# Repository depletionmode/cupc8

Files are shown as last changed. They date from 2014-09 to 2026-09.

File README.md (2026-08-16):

## CUPC/8

###### Documentation
https://github.com/depletionmode/cupc8/blob/master/doc/CUPC8%20Manual.md

###### Blog
http://depletionmode.com/

### Terminal debugger

Build the debugger from `tools/` with:

```sh
nim c -d:release simtui.nim
```

Then run `kernel/debug.sh`. The guest display is embedded by default; use
`kernel/debug.sh --display:window` for the standalone SDL window. Terminal
graphics and color treatment can be selected explicitly:

```sh
kernel/debug.sh --gfx:half --theme:light
kernel/debug.sh --gfx:auto --theme:dark
```

Inside the debugger, `:display embedded|window`, `:theme auto|dark|light`, and
`:gfx auto|kitty|half` switch these modes without restarting. Pane borders can
be dragged with the mouse to resize the layout. Press `?` for the complete
keymap and command reference.

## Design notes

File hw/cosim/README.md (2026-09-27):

# Schematic-derived wiring prerequisite

`gen_top.py` exports fresh KiCad netlists for the seven cards and reads the
main-board netlist. For routed slot execution it also reads the generated
GPU, IO, storage, Wi-Fi and e-ink card PCBs from `build/hw` (or
`--card-board-dir`), and the explicitly selected routed system PCB
(`--system-board`, default `build/hw/system/system-routed.kicad_pcb`) and CPU
card PCB (`--cpu-board`). It joins contacts by physical pad number, including the
system socket's x4 pad translation. It checks the shared slot buses, their
chipset series resistors, the weak MISO pull, CPU socket and resistor packs,
and SRAM/ROM attachment. Its JSON manifest lists contact joins and the
verified model attachment paths. A broken connection exits nonzero.

The native RTL machine consumes the manifest when `CUPC8_COSIM_TOP` points to
it. CPU address/data wires and SRAM/ROM address/data pins use physical bit
maps read from KiCad pads. Slot SPI/IRQ and system bridge lines use their
connector maps. The shared MISO idle level comes from the verified 47 kΩ
pull-up. Cards receive edges after the 33 Ω source RC delay (1.089 ns for a
15 pF input). SRAM and ROM reads wait their 45 ns and 70 ns maximum access
times plus routed copper delay (7 ps/mm). A memory bus with no routed copper
gets provisional access times and `routed_timing: false`. The manifest lists
unrouted CPU, memory, slot, bridge, clock, reset and power-policy signal nets
under `missing_routes`; `--require-route` rejects them.
The generator separates `runtime_nets`, whose netlist values affect the
machine, from `structural_only_nets`, which have only a connectivity check.
All named nets without an executed model or a reviewed waiver appear in
`unmodeled_nets`; `structural_only_nets` still lists every structural-only net,
including waived ones. `coverage_families` groups the remaining gaps by their
required model domain. This classification is a work queue and grants no
coverage. E2E-001 through E2E-004 use `--require-coverage` and fail while any
gap remains. This keeps local card and power circuits from being silently
counted as covered.

`reviewed_waivers` currently permits only reserved connector contacts with
exactly one passive test point and no active electrical load. CPU and system
reserved contacts require the corresponding card pad to be KiCad NC; a slot
reserved contact requires all five possible card pads to be NC. The system's
two B-side reserved contacts instead require a passive test point at each end.
The waiver is recalculated from both netlists on every generation. Attaching
an IC pin or changing a mating card pad to an active net restores the coverage
gap; the wiring mutation probe checks both cases. The record includes the
actual pin list, mating contact, and reason for review. No power, clock,
programming, bus, LED, or data signal receives this waiver.

The Type-C source input in E2E-004 passes through the extracted Rd/averaging/
reference network before it reaches the chipset's `PWR_HI` pin. The nominal
trip is 1.289 V on the active CC line; the test drives the 3 A minimum or
1.5 A maximum CC voltage, so a bad resistor network changes the class.
The main-board supervisor U6 reset output must connect to chipset U7's nPOR
input in the KiCad netlist **and** over measured routed copper. The manifest
passes `por_connected` to the native machine's reset input. On the routed
snapshot the shortest planar path is 88.152 mm; removing the supervisor
launch track makes `por_connected` false, and the native CPU stays at reset
PC `$E000` instead of reaching `$E2B9` in the 20 ms probe.
The separate chipset-to-CPU reset path crosses U7.32 to R34.1 on
`CPU_nRST_SRC`, R34.2 to main socket J2.B16 on `CPU_nRST`, and CPU-card
J1.B16 to U1.22. The archived main and current CPU card measure 12.342,
103.930, and 27.014 mm on these legs. The native RTL now gates the CPU's
reset input with their combined continuity while leaving the chipset's own
reset output visible. Opening the U7 launch removes only the source leg;
the native 20 ms probe leaves the chipset reset output high but holds the
CPU PC at `$E000` instead of `$E2B9`. Holding the otherwise floating input
low is a deterministic digital counterexample, not a voltage prediction.
The chipset's MEM_nWE pad U7.114 must also connect by KiCad net and routed
copper to SRAM U9.5 and ROM U10.31. The two independent branch flags gate
native memory writes. On the routed snapshot the shortest planar branches
measure 11.292 mm to SRAM and 54.867 mm to ROM. Removing the chipset's /WE
launch disables both. In a 20 ms CPU probe, an open SRAM /WE changes PC from
`$E2B9` to `$E1FF`; an open ROM /WE makes a 4 KiB sysctl flash write fail
read-back verification. This models the write-enable path only; other memory
controls and analog timing remain separate work.
ROM DQ0 has an additional route-bound read dependency from U10.13 to chipset
U7.119. The measured planar route is 23.517 mm. Opening its ROM launch track
keeps the other memory data traces in place but changes the native CPU's 20 ms
state from PC `$E2B9`/GPO `$02` to PC `$E35B`/GPO `$00`. The open net has no
pull resistor, so its voltage is physically undefined; the digital model
uses a deterministic high DQ0 value solely to expose the missing connection.
This counterexample does not establish analog open-pin behavior.
The CPU card's 16 address and 8 bidirectional data driver channels are now
traced in two copper legs each: FPGA pad to the 33 Ω pack input, and pack
output to the CPU socket finger. The generated per-bit links gate the native
CPU–chipset RTL bus in both data directions. Opening the routed FPGA A0
launch changes the native program counter; an open D0 link also changes
execution. An open bit is held high only as a deterministic digital
counterexample because its real voltage is undefined. This does not establish
CPU-card propagation delay or analog margin, and the remaining control lines
still need executed models.
The IO card's USB host data pair must pass from the RP2040 pins through the
27 Ω series resistors to the receptacle. That netlist path controls keyboard
attachment in the native machine; an open path leaves it disconnected.
Each of the six main-board slot chip selects is now connected to the native
card-select input through its netlist-identified 33 Ω resistor. Copper is
traced separately from the chipset package pad to the resistor input and
from the resistor output to the slot contact. A missing leg deasserts the
corresponding card's select in the native machine and fails `--require-route`.
The slot 1 source launch mutation leaves the other five selects intact and
reduces recorded SPI frames from 15 to 0. This accounts for the six
`SPI_nCS*_SRC` nets. Shared SPI SCK and MOSI use the same two-leg check from
the chipset through their 33 Ω source resistors to each of six slot pads;
MISO is traced from each slot pad back to the chipset input. The corresponding
per-slot link flags control the native card clock, outbound data, and return
bit. Opening the routed SCK source launch stops all slot 1 frames (15 to 0).
With the MOSI link disabled, the first GPU command changes from `$F0` to `$00`;
with MISO disabled, the native GPU workload records only 2 frames instead of
15. For digital counterexamples, open SCK/MOSI are held low and open MISO
reads the modeled idle high value; these choices do not predict analog
floating-pin voltage. The two source-side SCK/MOSI nets now count as executed.
The five slot cards now supply card-local route flags as well. SCK, MOSI,
CS_n and IRQ_n run from J1 to the MCU pad. MISO crosses the 74LVC1G125
buffer: MCU output to buffer input, buffer output to J1, and CS_n to its
output-enable pad. The generated top includes all five card kinds, while the
native machine combines only the installed kind's links with the physical
slot's main-board links. A missing generated card PCB leaves those links
disconnected and fails `--require-route`. Opening the GPU card's U1 SCK
launch changes 15 SPI frames to 0; opening IO-card IRQ_n prevents five
keyboard-service SPI frames within the first 25 ms after a key is queued.
This models digital connectivity and IRQ delivery, not analog edge quality
or open-pin voltage.
Five RP2040 boards (system, GPU, IO, storage, e-ink) also require all six
QSPI MCU-to-flash nets to have pad-to-pad copper before their native firmware
starts. An open clock launch on the GPU card changes 15 SPI frames to none;
the same board-level prerequisite removes only that card's firmware endpoint.
Mutating the IO prerequisite removes its keyboard, and mutating the system
prerequisite removes its bridge USB endpoint. The native firmware still comes
from an ELF image, so this checks a digital boot wiring prerequisite only;
flash contents, protocol timing, signal integrity, power rails, crystals,
reset and RP2040 boot-ROM fallback remain outside this model.
The storage card's seven SD signal contacts similarly control whether the
microSD socket is attached to its RP2040 model.
All four HDMI differential pairs, including the clock pair, must pass through
their 270 Ω series pack channels to the receptacle before the TMDS capture
endpoint attaches. Seven e-paper data/control lines through 33 Ω resistors
likewise control whether the panel attaches.
E2E-002 and E2E-003 capture the native HDMI frame after the BASIC program or
network page, replay the
observed GPU-slot SPI traffic through the independent host GPU core, and
compares all 640×480 decoded TMDS pixels at RGB222 precision. A fast mutation
test changes one SPI PUTC byte and requires the pixel comparison to fail.

From the repo root, after building the main board and five slot cards:

```
python3 hw/cosim/gen_top.py --output build/hw/cosim/top.json
python3 test/hw/test_cosim_wiring.py --main-board build/hw/main/main.kicad_pcb --card-board-dir build/hw --system-board build/hw/system/system-routed.kicad_pcb --cpu-board build/hw/cpu/cpu.kicad_pcb
python3 test/hw/test_cosim_runtime.py --top build/hw/cosim/top.json
# after the main route is complete:
python3 hw/cosim/gen_top.py --require-route --output build/hw/cosim/top.json
CUPC8_COSIM_TOP=build/hw/cosim/top.json CUPC8_EMU=native node test/emu/test_e2e.mjs E2E-002
# The catalogue can use this strict entry point for each row:
python3 hw/cosim/run.py E2E-001
python3 hw/cosim/run.py E2E-002
python3 hw/cosim/run.py E2E-003
python3 hw/cosim/run.py E2E-004
```

The second command proves swapped SCK/MOSI contacts, a missing chip select,
and a missing MISO pull are rejected. With `--main-board` it also opens the
supervisor's routed nPOR launch, chipset CPU-reset launch, slot 1 chip-select launch, shared SCK
source launch, GPU card SCK launch, GPU QSPI clock launch and CPU-card A0
launch, then executes the native
counterexamples. The third proves
that ROM and CPU
address/data swaps, slot SCK/MOSI swaps, bridge SCK/MOSI swaps, an open
nPOR and CPU-reset paths, memory-write branches and ROM DQ0 read route change the running
machine. The manifest currently covers the CPU, main memory, slot data paths,
system bridge, Type-C source class and
supervisor nPOR release and CPU reset delivery. Other power and reset circuits still use native
machine wiring. On the routed-board snapshot used for this audit, all required
top-level routes are present. Of 502 previously uncovered named nets, 45
reserved contacts have pin-bound waivers, eight slot-bus source nets, 30
card-local slot nets, 30 QSPI boot nets, 24 CPU-card bus nets and three CPU
reset nets now affect execution; 362 remain unmodeled. The remaining groups are boot/programming
(68), slot/control bus (36), CPU/memory (47), power/return (65), clock/reset
(50), indicators (52), external IO (26),
and power policy (18). E2E-001 through E2E-004 remain
pending behind `--require-coverage` despite passing narrower runtime probes.

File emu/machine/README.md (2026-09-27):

# emu/machine: the whole machine, natively

The native whole-machine emulator of `doc/milestone-1.md` ("Whole-machine
emulator", "Emulator speed"): `test/emu/machine.mjs` in C++, cycle for cycle.
The main board is the Verilated CPU + chipset (`soc/emu/board.h`, shared with
`build/emu/core.node`) with the SRAM and the SST39 ROM model
(`fw/test/sysmodels.c`); the GPU, IO and system cards run their real firmware
on the native RP2040 (`emu/rp2040`, its card-test harness for the `Emu` step
loop and TMDS capture); the Wi-Fi card is Espressif's QEMU, in step with the
board (below, "The Wi-Fi card"), with machine.mjs's `$A6`/`$A5` protocol.

| file | what |
|---|---|
| `machine.h`, `machine.cpp` | the cards (`Rp2040Card`, `SysctlCard`, `EspCard`), TMDS frame decoding and font matching, `Machine` (the loop, the card threads, `screen()`, `type()`) |
| `addon.cpp` | `machine.node`, wrapped by `test/emu/machinenative.mjs` into machine.mjs's `Machine` API |
| `machinerun.cpp` | the machine from the command line: speed runs, serial vs threaded digests |
| `../../soc/emu/board.h` | the main board (also used by `soc/emu/core.cpp`) |

## Build and run

```sh
tools/emu_machine_build.sh          # tools/emu_build.sh, then cmake + ninja into build/emu-machine
tools/qemu_build.sh                 # the Wi-Fi card's lockstep QEMU (build/qemu-esp); tools/fw_esp32c3.sh qemu, its firmware
node test/emu/test_wifi_lockstep.mjs # EMU-009: the Wi-Fi card in step, serial vs threaded
CUPC8_EMU=native node test/emu/test_e2e.mjs E2E-002
test/emu/machine_diff.sh            # serial/threaded determinism (EMU-007; machine.mjs is legacy, not compared)
build/emu-machine/machinerun --root . --rom ROM --mode both \
    --until '>>' 6e9 --type '10 print 6*7\nrun\n' --until 42 3e9 --run 200e6
```

`machinenative.mjs` has the same API as machine.mjs (`create({slots, rom,
sysctl})`, `powerOn`, `runFor`, `runAsync`, `runUntil`, `ns`, `state`,
`frame`, `screen`, `type`, `keyboard.press`, `stop`, `sysctlPort`), plus
`setThreaded`, `stats`, `cards`, `spiLog` and the `spiLog`/`threaded` create
options. `create({pwrHi: false})` drives the chipset's PWR_HI input low to
exercise the kernel policy for a source below 3 A; it does not model CC
voltage or supply current. `CUPC8_EMU_THREADS=0` runs serially. `runFor` runs on the calling
thread's call and returns; `runAsync`/`runUntil` yield to Node's event loop
between slices exactly as machine.mjs does, so cupc8.py can talk to the
system card's TCP port. The system card's CDC output is collected during a
slice and written to the socket at its end; input from the socket is queued
between slices, as in machine.mjs (where both only move when the event loop
turns). `-DMACHINE_LTO=ON`: see Speed.

The system card is a composite USB device with two CDC ports (`sysctl.md`);
the host side is `rp2040js::CdcHost` (`emu/rp2040/src/usb/cdchost.cpp`, the
port of `test/emu/cdchost.mjs`). Port 0 is the TCP port above; port 1, the
USB console (`../../doc/proposals/usb-console.md`), is `m.console` in
machinenative.mjs: `open()`/`close()` set and clear DTR on it (between
runs), `write()` queues bytes, `read()` returns what arrived, `listen(port)`
serves it on TCP (a connection opens it). The addon's `cdcWrite`/`cdcRead`
take the port as their last argument, and `consoleOpen(h, on)` sets DTR.

## The loop

`Machine::iterate()` is machine.mjs's `runFor` loop body, statement for
statement: `bridgePins` (the system card's SPI byte clocked into BR_* at
1 MHz); *busy* if a slot or the bridge is selected; while busy, every card is
advanced to the next clock edge, the board runs one clock, the system card
and then each slot card (slot order) advance to the board's time and are
driven; otherwise the board runs up to 120 clocks (stopping early when a
watched output changes) with its inputs sampled once, and the cards are
advanced and driven afterwards.

## Threads, and why they change nothing

Each RP2040 card has a thread. In an idle iteration nothing is advanced before
the board runs, the board's inputs (the cards' IRQ pins, the bridge pins,
`sysReset`) are sampled once at the start, and each card is then advanced to
the board's end time `t` (`while (ns < t) step()`) and driven with the
board's end outputs. So:

- The cards' work in the window depends only on `t`, the end outputs and the
  card's own state; it touches only that card (no RP2040 state is shared:
  emu/rp2040 has no globals). The order of cards within a window cannot
  matter, so they may run concurrently.
- A card's step sequence does not depend on its target. A card that steps
  while `ns < c * 1000/12`, for a clock count `c` the board has already
  reached in this window, takes a prefix of the steps `advance(t)` takes,
  because `t >= c * 1000/12` (the same double expression). So each card
  *chases* the board's clock count while the board runs, and finishes at
  `t` once the board marks the window FINAL: exactly the serial state.
- Nothing flows back until the window ends: the next iteration starts only
  when every card has arrived at the barrier; only then are the pins read.
- Busy iterations run serially, in machine.mjs's order, on one thread (every
  card is sampled each clock there: IRQ pins of unselected cards reach the
  chipset clock by clock, and the shared SCK/MOSI lines re-set their GPIO
  edge bits, so no card may run ahead).

There is no board thread: whoever leads an iteration runs the serial part
(bridgePins, busy iterations, the board's run while the others chase), then
does its own card's share; `runFor` hands the run to the threads and waits.
The leader is normally a quick card (IO, system card) that has finished its
window and volunteers, spinning until the slow card (the GPU) arrives and
hands over, so the GPU only ever chases; if nobody volunteers in time, the
last card to arrive leads. Who leads cannot change the result: the leader
does exactly the serial loop's work, with every other card parked.
`CUPC8_EMU_VOLUNTEER_SPINS` (default 200000, 0 = never volunteer) bounds the
volunteer's spin. Waits spin briefly and then sleep on a futex. `machinerun --mode
both` and `test/emu/machine_diff.sh` check the result: identical board
clocks, CPU state, RAM, every card's time, cycle counts and UART, a hash over
(board clocks, outputs, every card's time) after every iteration, every SPI
frame, and the screen.

A `storage` slot runs `build/rp2040/storage.elf` with the SD card model's
socket on its SPI1 (`emu/rp2040/harness/sdcard.h`); `Machine::sd()`, and
`sdInsert`/`sdRemove`/`sdCard` in the addon (`m.sd` in machinenative.mjs), put
an image in and take it out between runs. The model runs on the storage
card's own clock, inside its thread.

Harness hooks used in emu/rp2040: `FIFO::onPull` (TMDS capture), the SPI
`onTransmit`/`completeTransmit` callbacks, USBCDC and UsbKeyboard; nothing in
emu/rp2040 was changed for this directory.

## Speed

Boot to BASIC and type a program (1.6 s emulated, `test/emu/machine_diff.sh`,
quiet 4-core 2.1 GHz Xeon, emu/rp2040 with its PIO fast path, 2026-09-24):

| backend | slower than real time |
|---|---|
| machine.mjs (rp2040js) | 108x |
| native, serial (`CUPC8_EMU_THREADS=0`) | 23.5x |
| native, threaded (default) | 18.0x |

The threaded machine runs at the GPU card's speed: the GPU thread is busy
~95% of the wall time (252 MHz, three DVI serialisers every cycle), while the
IO card, the system card and the main board (each ~2-3x slower than real time
alone) run beside it. The spec's "a few times slower than real time" needs a
faster GPU card emulation in emu/rp2040. `-DMACHINE_LTO=ON` builds this
tree's copy of the RP2040 library with -O3 and LTO (about 10% faster before
the PIO fast path; not re-measured). On an oversubscribed host the threaded
mode can be slower than serial: the threads meet every 10 us of emulated time.

## The Wi-Fi card

The Wi-Fi card's firmware (its QEMU build, `tools/fw_esp32c3.sh qemu`) runs
in Espressif's QEMU, built by `tools/qemu_build.sh` from the tag the SDK's
binary comes from with `tools/patches/qemu-esp-lockstep.patch` (the SDK's
binary has no plugins and no outside clock control). It runs **in step with
the board**:

- `-icount shift=3,sleep=off`: the guest's clock is its instruction count
  (8 ns each), and an idle guest's clock jumps straight to its next timer.
  `-seed 1` and the patch's fix to the SYSCON random register (it was
  `rand()` seeded from `time(NULL)`) make its random numbers repeat.
- `-chardev cupc8` (the patch's `system/cupc8-lockstep.c`) is the emulator's
  line to QEMU. The guest runs only as far as the emulator lets it:
  `EspCard::advance(t)` grants it the board's time in 100 us steps, so it
  trails the board and runs beside it, in its own process.
- **The slot SPI slave is a device in QEMU**, a stand-in for the ESP32-C3's
  GPSPI2 slave at GPSPI2's address and interrupt source (registers in
  `cupc8-lockstep.c`). Like the real slave's queued DMA descriptor it holds
  the MISO preload the firmware armed, so the board never waits for the
  guest: at CS_n falling QEMU runs to the board's time and hands the preload
  over, and at CS_n rising the frame's MOSI bytes reach the device at the
  board's time and raise its interrupt. The firmware's ISR
  (`fw/wifi/port/esp32c3/main/transport_slotdev.c`) is `transport_spi.c`'s
  `done()`/`arm()`: it queues the frame and arms the next preload, swapped
  in whole by one register write. QEMU's clock is the board's at every
  select (to within one instruction), through `net join`'s back-to-back
  polling too (EMU-009 checks both). A stock QEMU has no such device (its ID
  register reads 0): the firmware then serves frames over UART1 (`$A6`/`$A5`,
  `transport_uart.c`), which `test_wifi_qemu.py` and the legacy machine.mjs
  use.
- **When a stale preload can be seen**, as on the card (`slot.md`: the card
  preloads before CS_n falls; `wifi-card.md`, "Status byte"): a frame shifts
  out the preload armed after the previous frame ended, so the status byte
  and any offered response are as of the previous frame's end, never
  updated mid-frame. The status byte is the task's last reading (the firmware
  takes it with `frames_status()` in its main loop, at most a tick old): the
  ISR may not ask the network stack for it. A response is offered only when
  no command is queued or running (`frames_preload()`), so a READ gets it
  only if it was ready when the frame before that READ ended, and RESP_LEN
  `$00` otherwise. After a READ the next preload may offer the same response
  again until the task has replayed that READ; the host reads a response
  once and sends a new command, which discards it. If the host selects
  before the ISR has re-armed (the host must leave 20 us), the device shifts
  out the previous preload again and still takes the frame (INT bit 1 if the
  ISR had not read the last one); the real slave has no descriptor queued
  then and would miss the frame. EMU-009 counts such selects and requires
  none.
- So the same board run gives the same guest run, instruction for
  instruction: EMU-009 (`test/emu/test_wifi_lockstep.mjs`) runs a join and
  an HTTP GET serially and threaded twice and compares everything, the
  Wi-Fi card's frames, QEMU's clock and the guest's network traffic (pcap)
  included.

**The one known timing approximation: the guest runs at 125 MIPS.** icount
steps are powers of two (`shift=3`: 8 ns an instruction), and the real
ESP32-C3 runs at 160 MHz, at best one instruction a cycle (less out of
flash: cache misses). So the firmware takes its instruction counts at 125
MIPS, e.g. its frame-end ISR is up to 1.28x slower than on the card. Timers
(FreeRTOS ticks, lwIP, the UART's) are in guest time and exact. Accepted by
David, 2026-09-27.

**The network outside the machine is not in step and never can be**: QEMU's
user networking (slirp) talks to real sockets on the host's clock. The patch
pins down the common case: when the guest sends a packet the vCPU stops
right after it, and QEMU waits (wall clock) until slirp has given the guest
nothing new for `CUPC8_LOCKSTEP_SETTLE_MS` (default 20, at most
`CUPC8_LOCKSTEP_SETTLE_MAX_MS`, 2000), so a host that answers within that
time is seen at a defined guest time. A host that answers later, or sends
unasked (a client through a port forward, E2E-014), is seen whenever QEMU's
main loop gets to it. A server inside the test's own Node process answers
only when the event loop turns between slices, usually too late for that,
so EMU-009's server runs in a child process. (Runs where cupc8.py talks to
the system card are not deterministic either: its bytes arrive at slice
boundaries that depend on wall time.)

`CUPC8_ESP_TRACE=FILE` logs every select (`S`, with QEMU's clock after `@`
and the preload) and frame (`F`, the MOSI bytes) at the board's time, and `Machine.create({ pcap })` records the guest's traffic. Two
E2E-003 runs with `CUPC8_E2E003_PORT` set give identical traces (before the
lockstep they differed from the first exchange after the join).

Found by the SPI slave stand-in: the firmware's frame-end ISR built the
preload with the card's `status()`, which asks lwIP (FIONREAD on each
socket); from an interrupt that corrupted FreeRTOS's lists once a socket was
open (the interrupt watchdog fired in `vListInsert`). The UART stand-in took
the preload in a task and hid it; on the card it was waiting to happen. The
ISR now takes the status byte the task last read.

Speed (2026-09-26, 24-core host at load ~15, boot and type a program, 2.4 s
emulated): a Wi-Fi card costs nothing measurable, before or after the
lockstep: threaded 8.6x slower than real time without it, 8.5x with it;
serial 11.3x and 11.2x. QEMU runs in its own process beside the board and
is far faster than it (1.5 s of guest time takes about 0.3 s alone). E2E-003
took 32 s of wall time (40 s before, on its real-time clock).

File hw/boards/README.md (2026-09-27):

# Board designs

Each board is a Python script that generates its KiCad schematic and PCB and
runs the whole pipeline in `hw/tools/kicadgen.py` (`pipeline()`):

1. schematic, ERC
2. netlist, board build, Freerouting
3. GND stitching, zone fill
4. silkscreen and 3D-model checks
5. DRC with schematic parity
6. Gerbers and drill
7. JLC BOM and CPL (every placed part carries an LCSC number), and `order.json`
8. 3D renders

Outputs land in `build/hw/<board>/`, and `fab/` holds what goes to JLCPCB.

```
python3 hw/boards/wifi.py
```

Shared rules:
- **Revision:** every board passes `title`, `revision` and `revision_at` to `pipeline()`, which prints `<title> rev <revision>` on the top silkscreen and puts the revision in the title block (and so in the Gerbers). Bump the board script's `REVISION` (A, B, ...) for every order that changes the board (`doc/milestone-1.md`, Board revision).
- **Cards:** 1.6 mm, with hard-gold fingers and a 30° chamfer. These are
  order options, written in `fab/order.json` and checked there.
- **Card edge:** each card's finger tab is KiCad's `BUS_PCIexpress_*`
  footprint. The script draws the body's outline and meets the tab where it
  starts.
- **Finger tab (every card, done by `pipeline(card_edge=True)`):** GND
  fingers tied into the pour, the PRSNT1_n/PRSNT2_n presence link pre-routed
  (`presence={"layer": ..., "rise": ...}` puts its run on an inner layer: the
  CPU card and the system card use In2.Cu), no vias on the tab, pre-routed
  escapes for the signal fingers beside the key notch, and routed GND tracks
  cleared off the contacts.
- **Inner layers on 4-layer cards (both opt-in):**
  - `zones=(..., ("/GND", ("In1.Cu",)), ("/3V3", ("In2.Cu",)))` makes each named
    inner layer a solid **plane** (a power layer, which Freerouting never
    routes on): the **CPU card**.
  - `plane=True` pours the outer layers' net on In1.Cu as well but leaves In1
    a **signal layer**, which the pour fills around the routes: the **system
    card**. Its QFN-56 fan-out would not route with a layer lost to a plane.
- **Fine pitch:** `fine_nets=` puts nets in the "Fine" class (0.15 mm track
  and clearance, 0.7 mm vias), for parts at 0.4–0.5 mm pitch: the system
  card's RP2040 and USB-C.
- **Branding:** the Kaplan Labs logo on the top silkscreen of every board.
  On the cards, `pipeline(logo_keepout=True)` keeps tracks and vias off the
  top copper under it (a rule area; the pour still fills there), and the
  silkscreen step fails on any track under it: routed across the logo, a
  track shows through the mask as a ridge over the artwork. The system
  card's logo is the 10 mm size (milestone-1.md's minimum): with the 12 mm
  one's keep-out, Freerouting left QFN nets unrouted or pour pockets
  unjoined at every position tried.
- **Designators** (`kicadgen.place_designators`, checked by
  `check_designators` in the silkscreen step, SILK-001): never over a pad
  or a via, another part's courtyard, any part's body or another word, by
  their printed strokes. They are placed before routing; the fixed vias
  (finger ties, presence link, fan-out, a board's own) and then the
  router's move any that landed under one to the nearest clear spot, up to
  2 mm off its part (45 % of a big part's size, for a QFN in its ring of
  vias), turned upright or at JLC's 0.8 mm minimum if that is what fits.
  Two words in one line keep 0.5 mm apart (closer, "C13" and "C11" read
  as "C13C11"). A designator walled in by vias gets room from a
  neighbour's, which steps aside (the build output says which). The
  stitching vias keep off every word. A designator with still no clear
  spot is left off (listed in the build output); none is on the cards. The board's name moves the same way off vias (a wide tab's GND
  ties), and its new spot is then a via keep-out for the router.
- **Assembly:** nothing is fitted by hand. The Wi-Fi card's antenna lead (MHF III to SMA) is
  the one exception: it is plugged in, not soldered.

## Wi-Fi card (`wifi.py`)

Spec: `doc/hardware/wifi-card.md`.

- **U1, ESP32-C3-MINI-1U-N4** (C2911374). The antenna receptacle (MHF III) end sits towards the card's top
  edge. The GPIOs follow `hw/pins.yaml`:
  - SCK: GPIO6
  - MOSI: GPIO7
  - MISO: GPIO5
  - CS_n: GPIO10
  - IRQ_n: GPIO3, open drain
  - LINK, TX and RX LEDs: GPIO4, GPIO0, GPIO1
- **U2, TLV62569DBVR buck** (C141836), fed from the slot's +5V, with L1
  2.2 µH (FNR3015S2R2MT, C167747), 22 µF in, 22 µF + 100 nF out, and a
  453k/100k feedback divider (3.32 V). An AMS1117 LDO failed the power
  checks: in a TX burst at the worst-case corner it left the ESP32-C3 at
  2.71 V (3.0 V minimum), and it ran at Tj ≈ 120 °C (`hw/power`, POW-003,
  THM-001). The slot's +3V3 pins are left unconnected: Wi-Fi TX peaks near
  350 mA, and the slot's +3V3 is limited to 300 mA.
- **U3, 74LVC1G125** (C52140430). Its /OE is CS_n, so the card drives the
  shared MISO line only while it is selected.
- **EN:** 10 kΩ / 1 µF RC, per Espressif. CARD_RST_n, which is open drain on
  the main board, pulls it low.
- **Straps:** GPIO9 has a 10 kΩ pull-up and PROG_n pulls it low for the ROM
  bootloader. GPIO8 and GPIO2 each have a 10 kΩ pull-up and carry nothing
  else.
- **Programming port:** SWCLK drives U0RXD and SWDIO carries U0TXD. esptool
  runs through sysctl's UART tunnel.
- **LEDs:** power at the standard spot (red: a green LED drops ~3 V, too
  close to the 3.3 V rail for 1 kΩ), then LINK (GPIO4), TX (GPIO0) and RX
  (GPIO1) in a row with it along the top edge, green with 100 Ω. TX and RX light for 30 ms whenever
  socket data moves.
- **Outline:** the standard I/O card outline, with its M3 hole
  (`slot.md`, Mechanical).
- **Test pads** for the native USB-Serial/JTAG (GPIO18/19). They are for
  debugging only.
- **PRSNT1_n (A1) is joined to PRSNT2_n (B18).** The RSVD pins are left
  unconnected.

## RP2040 cards: what the GPU and IO cards share (`rp2040card.py`)

- **U1, RP2040** (C2040), the minimal design from Raspberry Pi's *Hardware
  design with RP2040*: 100 nF on each IOVDD, DVDD, ADC_AVDD and USB_VDD pin,
  1 µF on VREG_VIN and VREG_VOUT, the core regulator feeding DVDD (1V1).
  TESTEN to GND.
- **U3, W25Q16JVSSIQ** (C131025), QSPI boot flash, 100 nF.
- **Y1, 12 MHz X322512MSB4SI** (C9002, CL = 20 pF): 33 pF each side
  (2 × (20 − ~3 pF stray)), and 1 kΩ in series with XOUT as the design guide
  has for drive level (the crystal is rated 10–200 µW).
- **3V3 from the slot's +3V3** (power.md: each card is well under the
  slot's 300 mA), with 22 µF where it comes on at B4/A4. No regulator.
- **Slot:** SCK, MOSI, CS_n, IRQ_n on GPIO2, 3, 5, 6 (IRQ_n is open drain in
  firmware). SWCLK/SWDIO go straight to the RP2040's SWD pins; CARD_RST_n
  is RUN, with a 10 kΩ pull-up. PRSNT1_n is joined to PRSNT2_n, the RSVD pins
  and PROG_n are unconnected.
- **MISO through U4, 74LVC1G125** (C52140430), enabled by CS_n, as on the
  Wi-Fi card. An RP2040 pad resets with its ~50 kΩ pull-down on, so a card
  held in reset, blank, or running firmware that never clears the pull would
  otherwise drag the shared MISO line against the main board's 47 kΩ
  pull-up (two cards: ~1.2 V), and an empty slot would no longer read `$FF`.
- **BOOTSEL:** a test pad on QSPI_SS through 1 kΩ (short to GND at power-up).
  Test pads also for SWCLK, SWDIO, RUN, UART TX and GND, down the left edge.
  Blank cards need none of them: SWD loads the flash (`slot.md`).
- **Power LED** (red, 1 kΩ) at the standard spot; the M3 hole at the
  standard spot.
- **Net classes:** every net on the RP2040's 0.4 mm-pitch pads (3V3 and 1V1
  included) is in kicadgen's `Fine` class: 0.15 mm tracks, 0.15 mm clearance
  (JLC: 0.127) and 0.65 mm vias. With the Default 0.2/0.2, a track can't
  turn out of a pad beside its neighbour, and Freerouting left QFN pins
  unrouted.
- **Four layers** (JLC04161H-7628, the stackup `order_spec` names): In1 a
  solid GND plane (a power layer Freerouting doesn't route), In2 routed with
  a GND pour. On two layers Freerouting never completed around the QFN on
  any of the cards; four layers also put every fast line (TMDS, SD, USB)
  over a solid ground.
- **Hand-laid copper before Freerouting** (`preroute`): TESTEN straight in
  to the exposed pad (a GND pin between two signal pins, which no pour
  reaches); on the turned cards (GPU, storage) the seven pins in the middle
  of the chip's top edge escape by vias, three in the ring under the chip
  and four just outside (`pocket_escapes`), because on the GPU they are
  walled in by the TMDS pairs; on the IO card DVDD 23 is tied to its cap.

## IO card (`io.py`)

Spec: `doc/hardware/io-card.md`.

- **J2, USB-A USB-302S-T** (C112455) at the top edge, with our footprint
  `cupc8:USB_A_SOFNG_USB-302S-T` (EasyEDA's has a malformed courtyard that
  misses the pads' rear ends). The shell face is on the board edge.
- **U7, TPS61023DRLR** (C919459) boosts the slot's +5V to 5.06 V for the
  keyboard (power.md, IO card keyboard boost): 1 µH FXL0420 (C167203),
  10 µF in, 2 × 22 µF out, 750k/100k feedback. Always on. Its pins are
  0.3 mm pads, so the board script lays their tracks (VIN/EN to the input
  cap, SW to the inductor, VOUT to the output caps, FB to the divider) with
  the loops short, as TI's layout guide asks.
- **U5, SY6280AAC** (C55136) switches the boost's output to VBUS, enabled by
  GPIO7 (100 kΩ pull-down, so VBUS is off while the RP2040 is in reset).
  R_SET = 12 kΩ: I_lim = 6800 / 12k = 0.57 A nominal, 0.42–0.71 A over the
  datasheet's ±25 %, so a keyboard gets its 500 mA and the card stays under
  the slot's 750 mA PTC. 10 µF at IN, 100 µF + 100 nF on VBUS.
- **VBUS_nFAULT (GPIO8):** the SY6280AAC has no fault flag (io-card.md
  assumed one). GPIO8 reads VBUS through 15k/22k (5 V → 2.97 V), so it goes
  low when the switch limits and VBUS sags below ~3.4 V, or is shorted.
  The firmware's active-low sense is unchanged.
- **USB data:** 27 Ω in series with D+ and D− at the RP2040 (design guide),
  USBLC6-2SC6 (C7519) at the connector. **No external 15 kΩ pull-downs:**
  the RP2040's USB PHY switches its own on in host mode; external ones as
  io-card.md lists would halve them to 7.5 kΩ, outside USB's 14.25–24.8 kΩ.
- **LEDs:** PWR, KBD (red, GPIO25: keyboard connected) and KEY (green,
  100 Ω, GPIO24: lit 30 ms after each HID report, the one activity LED an
  input-only link needs). GPIO24 is new in `hw/pins.yaml`.
- **UART TX** (GPIO16) on a test pad.

## GPU card (`gpu.py`)

Spec: `doc/hardware/gpu-protocol.md`.

- **J2, HDMI type A** (C2858275) at the top edge, with our footprint
  `cupc8:HDMI_A_SHOUHAN_HDMI-19PIN-043`: EasyEDA's pads, the maker's drawing's
  leg slots (EasyEDA's are 0.2–0.4 mm smaller than the drawing asks), and a
  courtyard that covers the pads. The shell legs are through-hole.
- **TMDS:** 270 Ω in series with every line (two 4 × 0603 arrays, C425067),
  PicoDVI's DC-coupled output: the sink terminates each line with 50 Ω to its
  3.3 V, so a low GPIO sinks ~10 mA as TMDS asks (PicoDVI README, "Improved
  Output Circuit"; its mini board, R12–R19). 0402 arrays would put pads
  0.15 mm apart, under the 0.2 mm rule.
- **ESD:** two TPD4E05U06DQAR (C138714, 0.5 pF) by the receptacle, laid
  flow-through: each line crosses its pin and the NC pad opposite, which are
  on its net in the schematic (the datasheet: NC pads are for straight-through
  routing).
- **Pin order:** the RP2040's pins run counterclockwise, the receptacle's
  pads the other way round, so with the pins as they were every pair had to
  cross the others. `hw/pins.yaml` now puts green on GPIO14/15 and the clock
  on GPIO10/11, and the firmware sets PicoDVI's `invert_diffpairs` (P on
  GPIO n+1). Around the turned-round chip the pairs then come out in the
  receptacle's order, D2, D1, D0, clock, P before N: no crossings.
  `invert_diffpairs` is a pad output override, so the PIO lanes are the same;
  GPU-005 (the real gpu.elf, TMDS decoded) passes.
- **TMDS routing:** with the pairs in order they need no vias between the
  chip and the receptacle, over In1's solid ground. 252 Mb/s over < 20 mm
  is electrically short (a bit is ~0.6 m of FR-4), so the pairs are not
  impedance-controlled; PicoDVI's own 2-layer boards pass the DVI eye mask.
- **GND between the lines** (`preroute`): the receptacle's shield and DDC
  ground pins get a via 2 mm behind the pad, under the receptacle's body;
  each ESD's GND pins, in the middle of its rows, are joined through the
  package and taken down by a via.
- **+5V to the sink** (HDMI: 4.8–5.3 V, ≥ 55 mA at the source's pin), the
  circuit power.md decides ("GPU card HDMI +5V"): the slot's +5V is 4.1 V
  at the card at the worst corner and up to 5.4 V at vSafe5V max, so U7, a
  **TPS63802DLAR buck-boost** (C2845237), holds the pin at 5.045 V either
  way (4.88–5.21 V over VFB, the 1 % divider and the power-save ripple).
  Slot +5V → F1, a 200 mA PTC SMD0805P020TF (C20976), **ahead** of the
  converter (after it, its drop would take the pin to 4.67 V; ahead, it
  still trips on a shorted cable) → 10 µF (C21) at VIN → U7 (VIN and EN
  on the PTC's output, MODE to GND for power save, PG unconnected), L1
  0.47 µH FXL0420-R47-M (C167200), 2 × 22 µF out (C22, C23), FB 300k
  (C23024) / 33k (C4216), both basic → HDMI pin 18, with the DDC pull-ups and the HPD
  divider. No Schottky: the TPS63802 disconnects its output from its input
  when off. It draws 95 mA from the slot's +5V at the worst corner
  (POW-008; POW-006 B9b). `hw/power/design.py` `GPU_BOARD` lists these
  parts, and POW-008 and THM-001 fail if the board script differs.
- **Buck-boost layout** (TI SLVSEU9D, 12; `buck_boost()` lays it before
  Freerouting, the pads being 0.3 mm at 0.5 mm pitch): U7 turned so its
  power row (VIN, L1, GND, L2, VOUT) faces up, the inductor across it
  above, C21 and C22 at VIN and VOUT on either side, C23 beside C22. EN is
  tied to VIN under the package; MODE, AGND and GND pin 8 are joined
  through the package's middle and taken down by a via that also ties in
  C21's ground. FB runs down to the divider below, away from L1/L2. The
  block sits in the open area left of the receptacle.
- **HPD** (GPIO18): 22k/33k from the connector, 5 V → 2.9 V, pulled low when
  nothing is plugged in.
- **DDC** (GPIO19/20, EDID): a 2N7002 (C8545) per line as a bidirectional
  level shifter, gate at 3V3, 2.2 kΩ to the HDMI +5V on the cable side (HDMI
  source pull-ups) and 4.7 kΩ to 3V3 on the RP2040's. The RP2040 is not 5 V
  tolerant; the monitor's EEPROM wants 0.7 × 5 V for a high.
- **LEDs:** only PWR. GPIO25 (LED_ACT in pins.yaml) is left unconnected.
- **UART TX** (GPIO0) on a test pad. CEC and the utility pin are unconnected.

## Storage card (`storage.py`)

Spec: `doc/hardware/storage-card.md` (card type $04).

- The RP2040 core of the other two cards (`rp2040card.py`), turned round as
  on the GPU card so its SD pins (GPIO12–19) face the socket. Four layers,
  In1 a GND plane.
- **J2, TF-01A** (C91145, 206k in stock): push-push microSD with a
  card-detect contact, JLC's own footprint. It sits on the top edge with its
  opening flush with the edge; a card sticks out by the push-push travel.
  The card-detect contact closes to the shell (GND) with a card in, so
  SD_nDETECT (GPIO17) reads low (as `hw/pins.yaml` expects).
- SD in SPI mode on SPI1 (`storage_mcu` in `hw/pins.yaml`): SCK GPIO14, CMD
  GPIO15, DAT0 GPIO12, DAT3/CS GPIO13; DAT1/DAT2 routed to GPIO18/19.
- **Pull-ups:** 10 kΩ on CMD, DAT0, DAT1, DAT2 (a 4 × 0603 array, C29718,
  basic) and on DAT3 and card detect (0402).
- **At the socket:** 10 µF + 100 nF on VDD (the card's 3V3, from the slot).
- **ESD:** two TPD4E05U06DQAR on the seven signal lines.
- **LEDs:** PWR at the common spot, then ACT (GPIO24) and CARD (GPIO25),
  green with 100 Ω, along the top edge.

## System card (`system.py`)

    python3 hw/boards/system.py [outdir]     (default build/hw/system)

sysctl, the RP2040 that programs and debugs the machine
([system-slot.md](../../doc/hardware/system-slot.md),
[sysctl.md](../../doc/hardware/sysctl.md)), on a 56 × 48 mm card above a
PCIe x4 finger tab (the shared card rules above), with a USB-C port on
the top edge for the host PC. Everything is placed by JLC; nothing is fitted
by hand.

**Power.** The card runs from the slot's **+3V3** (contacts B1, B2, A2):
the main board's 3V3 buck, which is where [power.md](../../doc/hardware/power.md)
puts sysctl in its distribution tree and its current budget (50 mA max).
There is no AMS1117 on this card: running the RP2040 from the same rail as
the chipset, flashes and expanders it drives means its I/O can never be
powered while theirs is not, or the other way round, and it saves a part.
The slot's **+5V (A11) is not connected**. The ADC's reference (ADC_AVDD)
is the same slot +3V3, with 100 nF at the pin, which is what the power
analysis assumes for CC sensing (power.md: ±3 %, ≤ 12 LSB).

**USB-C.** A data-only device port: 5.1 kΩ Rd on CC1 and CC2, 27 Ω on
D+/D−, and a USBLC6-2SC6 between the receptacle and the resistors.
**VBUS powers nothing**, so the card cannot back-feed the host or the slot
rails. The USBLC6's rail pin goes to +3V3, not VBUS: tied to VBUS, its
steering diode would lift VBUS to about 2.7 V from the D+ pull-up whenever the
card is on and the host is not. **VBUS is sensed**, because a self-powered
device must not pull D+ up while VBUS is absent (USB 2.0, 7.1.5): it drives
the gate of Q1, a 2N7002 (10 kΩ in, 100 kΩ to GND: ~4.5 V from 5 V, Vth ≤ 2.5 V),
whose drain (10 kΩ to +3V3) is GPIO29, USB_nVBUS, low while a host is there.
The RP2040 pin never sees VBUS, so no 5 V on a 3.3 V pin and no current into
it while the card is unpowered. The firmware starts USB only once VBUS is
seen and calls `tud_disconnect()` (D+ pull-up off) whenever it goes. The pin
is active low so that a model with nothing driving it (the whole-machine
emulators) reads "host present" and behaves as before.

**RP2040.** Raspberry Pi's minimal design: W25Q16JVSSIQ on QSPI, a 12 MHz
X322512MSB4SI crystal (C_L 20 pF, so 33 pF load caps with about 4 pF of
stray capacitance) with 1 kΩ on XOUT, the internal 1V1 regulator (1 µF in
and out), and 100 nF on every supply pin.

**Slot signals.** Every signal goes to the GPIO in `hw/pins.yaml`, unchanged.
The nine SPI outputs sysctl drives (SCK, MOSI and nCS of the bridge, FL0 and
FL1) have 33 Ω source termination at the RP2040, as every card driver on
the CPU bus has ([cpu-bus.md](../../doc/hardware/cpu-bus.md)). MISO, CDONE,
the open-drain CRESET_n and SYS_nRST, the programming port (the main board
has its 33 Ω), MUX_SEL, CC1/CC2 and V1V2_SENSE (1.2 V fits the ADC's range
directly) connect directly. I2C has 10 kΩ pull-ups on the card, in parallel
with whatever the main board fits. PRSNT1_n (A1) is joined to PRSNT2_n (B32)
on the card, as on PCIe. RSVD_A1–A3 are not connected; RSVD_B1/B2 go to
test pads.

**Test pads** (not assembled parts): SWCLK, SWDIO, RUN, BOOTSEL (short it to
GND while powering up for the USB boot ROM; it reaches QSPI_SS through
1 kΩ), +3V3, 1V1, GND, and RSVD_B1/B2.

**LEDs** ([milestone-1.md](../../doc/milestone-1.md), Indicator LEDs):
power (D1, red KT-0603R, 1 kΩ from +3V3) at `kg.power_led_at`, 3 mm in from
the body's top-left; USB activity to the host (D2, TX, GPIO0) and from it
(D3, RX, GPIO1), green KT-0603G with 100 Ω, each lit for ~30 ms after data
in its direction. All 30 GPIOs were assigned, so the activity LEDs take
GPIO0/1, which `hw/pins.yaml` had as a debug UART that no firmware used (the
USB CDC link and the SWD pads cover debugging), and the VBUS sense takes
GPIO29, which was a status LED.

**Board.** Four layers (JLC04161H-7628), 56 × 48 mm above the tab. GND is
poured on F.Cu, B.Cu and In1.Cu; all four layers route (In1 as a power
plane left the QFN-56 fan-out unroutable). The body is taller than the parts
need: the 10 mm band above the tab is where 50-odd slot nets fan out of the
fingers. The RP2040's and J1's nets are in kicadgen's "Fine" class (0.15 mm
track and clearance, 0.7 mm vias): at 0.2 mm clearance Freerouting counts
every pair of the QFN's 0.2 mm-apart pads a violation and routes none of
them. Freerouting necks those tracks to 0.11 mm at the pads, inside JLC's
4-layer minimum (0.09 mm), which 4-layer boards now check against (0.1 mm).
The presence link (A1 to B32) crosses on In2.Cu 1.8 mm above the tab. The
script's `prepare()` pre-routes one finger's escape, CHIPSET_CDONE on A21:
it sits between two all-GND columns whose ties wall it in, and Freerouting
left it unrouted at every pass count. The pipeline checks it (and the
key-notch escapes) on KiCad's connectivity after routing. J1 is
JLC's own footprint (jlc: import), since KiCad's splits the paired contacts
(A1/B12 ...) that JLC places as one pad; its EasyEDA 3D model is moved
2.27 mm onto the footprint. Passives are 0603 basic parts.

**Firmware and pins.** `hw/pins.yaml` gives GPIO0/1 to LED_USB_TX/RX (they
were a debug UART that nothing used) and GPIO29 to USB_nVBUS (it was the
status LED); every other GPIO is taken. `fw/rp2040/sysctl/main.c` lights each
LED for 30 ms after USB data in its direction and follows VBUS as above.
SYS-006 checks the LEDs light after a request and go dark after, that
without VBUS there is no D+ pull-up and no enumeration, and that the pull-up
goes and comes back with VBUS.

## CPU card (`cpu.py`)

    python3 hw/boards/cpu.py            # outputs in build/hw/cpu

The M1 CPU card: `cpu.vhd` in an iCE40HX4K-TQ144 on the PCIe-x8-style CPU
socket ([cpu-bus.md](../../doc/hardware/cpu-bus.md)). It boots from its own
W25Q32JVSSIQ, which the system card reprograms through the socket (FL1 bus,
CRESET_n, CDONE; [system-slot.md](../../doc/hardware/system-slot.md)).

- **Outline.** The I/O cards' outline (cpu-bus.md, CPU card outline): the
  62 × 39.05 mm body `kg.IO_CARD_BODY`, with the M3 hole and the PWR LED
  where every card has them. The x8 tab (x −0.65…50.65) sits under it with
  5.35 mm shoulders, and finger B1 is at the same offset from the body's left
  edge as on the x1 cards. `pipeline(io_card=True, tab=kg.X8_TAB)` draws and
  checks the outline. The width is set by the x8 tab plus its two 5 mm
  shoulders (61.3 mm, which the existing 62 covers).
- **FPGA pins** are read from `hw/pins.yaml` (`cpu_fpga`), the file that also
  generates `build/hw/cpucard.pcf`, so the schematic and the bitstream agree
  by construction. Each side of the package carries its bus lines in the
  order of their fingers, left to right. The bottom side (bank 3) has A0–A15
  on pins 1–20, then CPU_CLK (21, GBIN6), /RST, /STB, /RDY, RW and SYNC
  (22–26). The right side (bank 2), bottom up, has D0–D7 (37–45), IRQ0–3
  (47–52), TMR_EXP0/1, HALTED and WAITING (55–61). I also tried the other
  way round (D and the control lines on the bottom side, A on the right),
  and it routed worse.
- **Footprints** are JLC's own (`jlc:`, imported from the LCSC part) for the
  FPGA, the flash and the resistor arrays, so the BOM check (BRD-001) matches
  them pad for pad. The pin tables are in `hw/parts/`. The FPGA's table is
  Lattice's HX4K TQ144 pinout. All 144 pins were cross-checked against
  KiCad's symbol and icestorm's chipdb.
- **Power** (Lattice FPGA-TN-02006, the iCE40 hardware checklist). VCC 1V2
  comes from an RT9013-12GB off the socket's +3V3. All four VCCIO banks,
  SPI_VCC and VPP_2V5 are on 3V3; VPP_2V5 may be 2.5–3.3 V when the FPGA
  boots from SPI flash. The PLLs are unused, but each VCCPLL still gets
  100 Ω + 4.7 µF + 100 nF, as the checklist asks. The caps go to that PLL's
  own GNDPLL pin, which is *not* joined to board ground. VPP_FAST is left
  open. Every supply pin has 100 nF and its own via to its plane or rail,
  and each rail group has 4.7 µF. The card takes nothing from +5V.
- **Configuration.** SPI_SS_B and SPI_SCK are pulled up (controller mode).
  CRESET_B and CDONE are pulled up on the card as well as on the main board.
  /WP and /HOLD are pulled high, because the FPGA uses plain 0x0B reads.
- **Bus.** Every card output (A, D, RW, /STB, SYNC, TMR_EXP, HALTED,
  WAITING) has 33 Ω at the driver: eight 4D02 arrays (0402x4, 4 × 33 Ω).
  Each array keeps its pins' order on both rows: FPGA side on pads 1–4,
  finger side on 8–5. CPU_CLK and the other inputs go straight to the FPGA.
- **Straps.** CARD_ID = `10`: CARD_ID0 goes to GND, and CARD_ID1 is left to
  the main board's pull-up. PRSNT1_n is joined to PRSNT2_n. On this wide
  card the link runs round the card's edge on In3 (`presence_ring`, passed to
  the pipeline as `presence=`). Straight across above the fingers, it walled
  that layer off from every line crossing towards them.
- **LEDs.** The PWR LED (D1, red, 1 kΩ from 3V3) is at the common power-LED
  spot, 3 mm in from the body's top-left corner. The 1V2 rail LED (D2,
  [power.md](../../doc/hardware/power.md)) is next to it along the top edge.
  1.2 V cannot light an LED, so an MMBT3904 driven from 1V2 switches a red
  LED on 3V3. The silkscreen labels them "PWR" and "1V2". There are test
  pads for 1V2, 3V3 and GND. The title and revision are "CUPC/8 CPU rev A".
- **Parts** (LCSC): iCE40HX4K-TQ144 C1521989, W25Q32JVSSIQ C179173,
  RT9013-12GB C58464, 4D02WGJ0330TCE 33 Ω × 4 C25501, MMBT3904 C20526,
  KT-0603R red LED C2286, and 0402 basics: 100 nF C1525, 1 µF C52923,
  4.7 µF C23733, 10 kΩ C25744, 1 kΩ C11702, 100 Ω C25076.
- **Stackup.** 6 layers (David, 2026-09-25), JLC06161H-3313, 1.6 mm, with
  hard-gold fingers, bevelled per the fab order spec (`kicadgen.order_spec`).
  The layers are signal + GND pour / solid GND plane / signal / signal /
  solid 3V3 plane / signal + GND pour. 1V2 is routed as tracks. JLC offers
  gold fingers at any layer count, given ENIG and a board of at least 50 mm.
- **Routing.** The bus and configuration nets are in kicadgen's Fine class,
  0.15 mm track and clearance (`fine_nets`). The TQ144's pads are 0.5 mm
  apart with 0.22 mm between them, so at the Default class's 0.2 mm
  clearance no track can pass between two pins. Freerouting then left 1–13
  nets unrouted on 4 layers and on 6 alike. With Fine, 11 of 12 tries of a
  search routed the card completely, and the pipeline's first try does.
- **Placement.**
  - The FPGA sits against the top edge, with its top pad row 0.85 mm in.
    That leaves the 10 mm band under it for the arrays and the bus fan-out.
  - The four top-side supply pins (VPP, VCC and 2 × VCCIO1, the last an
    unused bank) are decoupled from the package's corners and sides, 5–10 mm
    away, all on planes or the 1V2 rail. Every other supply pin has its
    100 nF beside it.
  - The A and control arrays are in a row under the bottom side, and the D
    arrays sit under the package's bottom-right corner. Every array flows
    down towards its fingers. The timer array is right of the right side,
    above its fingers at the right-hand end.
  - The flash is by the config pins, under the top edge beside the M3 hole.
    The configuration pull-ups are at the lower left, over their fingers.
  - The LDO, the 1V2 switch and the PLL1 filter are on the left, on a grid.
  - The logo is in the lower right.
  - The designators are at JLC's 0.8 mm minimum height (`silk_text`): the
    card is 0402s. Nothing sits in the 4.5 mm strip above the fingers.

## E-ink card (`eink.py`)

Spec: `doc/proposals/eink-gpu.md` (its Decisions): card type $01, a
replacement for the GPU card, never fitted with it. The panel (5.83"
GDEY0583T81 on a DESPI-C02, or a Waveshare e-Paper HAT) comes on its driver
module, which carries the booster; the card only drives its SPI.

- **The RP2040 core** from `rp2040card.py`, laid out as on the storage card
  (the same chip-area placement and `pocket_escapes` prerouting): the chip turned
  round, so the panel pins (GPIO9–15, `hw/pins.yaml` `eink_mcu`) sit at its
  top-right corner, facing the header. Four layers, In1 a GND plane.
  Its `pocket_escapes` put SWDIO's via a row further out and towards the
  fingers, as the storage card's do.
- **J2, 1 × 9 right-angle 2.54 mm header PZ254R-11-09P** (C492417,
  through-hole, JLC's own footprint) on the top edge: the insulator flush
  with the edge, the pins out over it, in the module cable's order: 1 VCC,
  2 GND, 3 DIN, 4 CLK, 5 CS, 6 DC, 7 RST, 8 BUSY, 9 PWR. Each pin's name is
  on the silkscreen under it (the DESPI-C02's header has another order and
  is wired with loose jumpers by these names); the names are a board-only
  footprint that `eink.py` writes (`cupc8:EInk_Header_Legend`).
- **ESD:** two TPD4E05U06DQAR (C138714), as the storage card, at the header:
  the seven signals and VCC. The header is handled from outside the case.
- **33 Ω in series** (0603, C23140, basic) with each of the seven signals,
  at the RP2040 side of the TVS: the edge rate on the 20 cm cable, and the
  current into a pin while the TVS clamps. They sit in two staggered rows in
  the order the chip's pins come out, so the fan-out doesn't cross (0603, not
  0402, so each designator fits over its part).
- **Module power:** the slot's +3V3 through F1, a 100 mA PTC (C20975, as on
  the GPU card's HDMI +5V), then 10 µF + 100 nF at the header. The slot's
  +3V3 has no fuse of its own and is shared by every card, so a shorted
  cable or module must not pull it down; the module's capacitors also charge
  through the PTC, not straight off the card's rail. The module draws
  ≤ 40 mA while refreshing (0.36 V across the PTC at its 9 Ω worst case).
  EPD_PWR (GPIO15) switches the module's power on Waveshare's Rev 2.3 HATs;
  the RP2040 pad's reset pull-down keeps it off until the firmware runs.
- **LEDs:** PWR, and REFRESH (green, 100 Ω, GPIO24) in the top-edge row:
  lit while the panel refreshes.
- **UART TX** (GPIO16) on a test pad.

## Main board (`main.py`)

Specs: `doc/hardware/cpu-bus.md`, `slot.md`, `system-slot.md`,
`memory-map.md`, `power.md` (and `hw/power`), `sysctl.md`, `debugging.md`.
6 layers (JLC06161H-3313), as the
CPU card: F.Cu / In1 GND plane / In2 / In3 / In4 +3V3 plane / B.Cu, with
GND also poured on the outer layers. Four signal layers are what it takes:
with two (a 4-layer board, both inner layers planes) Freerouting stalls at
~80 unrouted connections; with four on a 4-layer board (the pours cut round
the routing) it completes, but the +3V3 pour splits into pieces and GND
islands form round the chipset. Every SMD pad on GND or +3V3 has its own
via to its plane, placed where Freerouting also finds it clear
(`FANOUT_MARGIN`: its hole a clearance off its own pad, clear of the NPTH
holes' keep-outs; at KiCad's margins those vias were ~117 violations
Freerouting carried through every pass). The TQ144, sTSOP-32 and eFuse
signal nets route in kicadgen's Fine class (0.15 mm), as on the CPU card;
the eFuse's VBUS_F and 5V_SYS in FinePower (0.5 mm track, Fine's
clearance between the QFN's pins). Each routing try runs 16 differently
ordered Freerouting runs at once and keeps the lowest-ordered one that
completes (kicadgen `route_parallel`); tries are capped at 30 passes, then
60, then 90 (`ROUTE_PASSES`, `ROUTE_TRIES`), each run at 3 hours of wall
time (`ROUTE_TIMEOUT`) and a 1 GB Java heap (`ROUTE_HEAP`; uncapped, each
JVM reserved a quarter of the RAM). The eFuse's IN/OUT escapes, EN's stub,
and the VBUS_F/5V_SYS connections the router kept leaving open are locked
copper laid before routing (`prepare()`). 125 × 184 mm, 3 boards assembled.

```
python3 hw/boards/main.py        # also runs hw/boards/sockets.py and the pincheck netlist check
```

- **Chipset U7, iCE40HX4K-TQ144** (C1521989). Its pins come from
  `hw/pins.yaml` at run time, so the schematic cannot drift from the `.pcf`.
  The symbol is KiCad's (the footprint JLC's), whose pinout agrees with
  Lattice's HX4K pinout
  (`hw/datasheets/iCE40HX4K-TQ144-pinout.csv`). **EasyEDA's symbol for
  C1521989 is the HX1K-TQ144's** (pins 15–18 NC, PLL on 35/36): never use it.
  `cupc8_main.kicad_sym` is generated by `main.py` (the unused
  three-digit pins lengthened so their no-connect crosses clear the numbers).
  Configuration from U8, W25Q32 (C179173): CRESET, CDONE, SS pulled up, so
  it boots with no system card. Each VCCPLL pin through its own 100 Ω with
  10 µF + 100 nF beside it.
  VPP_FAST and the spare I/O (105–107 and others) are left unconnected.
- **Series terminations:** 33 Ω at the chipset on every chipset output to
  the CPU socket (/RDY, IRQ, D, /CPU_RST), the slot SPI (SCK, MOSI, every
  CS_n) and BR_MISO. The FPGA side of each is net `<signal>_SRC`.
- **Memory:** U9 IS62WV5128EBLL (all of A0–A18, for banked extended RAM; M1
  drives A16–A18 low for RAM), U10 SST39VF040 (PLCC-32),
  on MEM_A/MEM_D. /CE_RAM, /CE_ROM and /WE have 10 kΩ pull-ups, so nothing
  is selected or written while the chipset configures.
- **Clock and reset:** Y1 12 MHz (C160457) into CLK12 and CPU_CLK through
  33 Ω each. U6 MAX811T: nPOR to the chipset; MR from SW1 (RESET) and SYS_nRST.
- **Sockets:** one row (slot.md, "One row of cards"): the CPU socket
  (x8) first, then slots 1–6 (x1), 20.32 mm apart, all with contact 1 at
  x = 12 mm and the same way round, so the seven cards, which share one
  outline, stand in line with their top edges, M3 holes and LEDs aligned.
  Both are UMAX 3183 sockets from one drawing (318307001), so they seat the
  cards at the same height (the same 11.25 mm body and contact section). The
  system slot (x4, its own card) is off the row in the south-east.
  `sockets.py` mates KiCad's finger footprint with each socket footprint
  (key in key, B side facing south) and fails if any finger meets a contact
  of another name; its self-test proves it catches swapped rows and reversed
  numbering. The UMAX footprints are JLC's with the drawing's recommended
  holes (0.75 mm) and posts (2.35 mm), so pin A11/B11 clears the key post.
  The system slot uses JLC's own C19188869 footprint (hold-downs narrowed
  off the locating holes) with a copy of `CUPC8_SystemSlot` numbered as its
  pads (A1–A32 = 1–32, B1–B32 = 33–64, hold-downs 65 on GND).
- **Card rail:** the row's M3 holes (`kg.IO_CARD_HOLE`, 52 mm east of
  contact 1, 40 mm up) line up at x = 64 mm; two M3 holes on that line,
  midway between slots 1 and 2 and 10 mm south of slot 6, carry the rail's
  posts (`slot.md`, Mechanical). Six more M3 holes at the corners and the
  east edge.
- **Slots:** each +5V through its own 1.1 A PTC (SMD1206P110TFT: 0.80 A per card), 0 Ω 0805 link and 50 mΩ
  sense resistor, with test pads either side of the sense. IRQ_n 4.7 kΩ,
  CARD_RST_n, PROG_n and PRSNT2_n 10 kΩ pull-ups. SWCLK/SWDIO from the two
  CD74HC4051 (U11 clock, U12 data; channel n−1 = slot n, MUX_SEL pulled high
  = channel 7, nothing) through 33 Ω. Expanders U13 ($20: CARD_RST_n,
  PROG_n) and U14 ($21: slot presence, CPU presence and CARD_ID, PWR_HI), as
  `sysctl.md`. Shared MISO 47 kΩ pull-up. RSVD contacts to test pads.
- **CPU socket:** /STB, /CPU_RST, PRSNT2_n, CARD_ID, CRESET_n, CDONE and
  FL1_nCS 10 kΩ pull-ups; D[7:0] 47 kΩ keepers. PRSNT1_n on GND.
- **Power** (`power.md`; every value `hw/power/design.py` assumes is in
  `main.py`'s `POWER`, in one place): USB-C (C165948, JLC's footprint)
  with 5.1 kΩ Rd, USBLC6 on CC, SMD1812P350TF/16 3.5 A PTC, SMF5.0A,
  1 µF, then the TPS259470 eFuse (EN from the POWER button's controller, RILM 1.13 kΩ: 2.63–3.21 A,
  OVLO 37.4k/10.0k 0.1 %, dVdt 680 pF), 22 µF on 5V_SYS, 0 Ω link to +5V.
  3V3: TLV62569PDDCR (DDC, for THM-001; PG open), 2.2 µH HPC5020NF (4.1 A,
  32 mΩ), 10 µF in, 22 µF out, 453k/100k 0.1 %, 0 Ω link; 3 × 22 µF more at
  the loads. 1V2: RT9013-12, 1 µF in and out, 0 Ω link, 100 nF at each
  iCE40 VCC pin; each PLL supply pin its own 100 Ω + 10 µF/100 nF filter. PWR_HI (a 3.0 A source): TLV7011 with CC1/CC2 averaged
  through 1 MΩ each against 0.645 V (41.2k/10k from 3V3), because only
  the active CC line carries Rp.
- **POWER and RESET** (David, 2026-09-26; `power.md`, On/off): two
  C318884 tactile switches side by side on the front (south) edge, labelled
  on silk, in front of every card. POWER (SW2) toggles the machine: U16
  MAX16054 (C79401) drives the eFuse's EN/UVLO (R44 100 kΩ pull-down), from
  3V3_STBY, U15 HT7533-2 (C82217, 24 V in) on VBUS_F, so it is always
  powered; the machine starts off when USB is plugged in. RESET (SW1) is
  the MAX811's MR, as before.
- **LEDs:** PWR (3V3, top-left corner as on every board), then, in one row
  with it along the top edge (milestone-1.md, Indicator LEDs), east of the
  CPU socket: rails 5V, 3V3, 1V2 (the 1V2 one through an NPN), CDONE
  (through an NPN, 100 kΩ base so CDONE still reads high), and GPO bits 7–0
  (the POST code, read as a binary number). Each label just south of its
  LED, its resistor south of that (`LABEL_SIDE`); the NPNs in a column
  east of the row. All red 0603 (C2286), labelled on silk.
- **Headers and pads:** J4, 2 × 5 AUX SPI (SPI dev 6: 1 +3V3, 3 SCK,
  5 MOSI, 7 MISO, 8 AUX_CS_n, 9 +5V, even pins GND). Test pads on every rail,
  the clock, the resets, both flash buses, the bridge, the slot SPI, I2C, the
  programming port and every RSVD contact. The CPU-bus and memory-bus
  signals are probed on the CPU socket's through-hole pins and the ROM's
  PLCC leads, not on pads of their own.
- **Assembly:** the x8 and x1 sockets and J4 are through-hole parts in JLC's
  library; they need JLC's Standard PCBA with through-hole assembly
  (hand/wave soldered, charged per joint), not Economic.

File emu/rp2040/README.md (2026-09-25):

# rp2040emu: a native port of rp2040js

A C++17 port of [rp2040js](https://github.com/wokwi/rp2040js) v1.1.1 **with the
cupc8 dual-core patch** (`tools/patches/rp2040js-dualcore.patch`, applied at
`~/.local/share/cupc8-sdk/rp2040js`). It exists for the "Emulator speed" row of
`doc/milestone-1.md`: the whole-machine emulator must run natively with the
same cycle model as the TypeScript one. The port is **structure-preserving**:
one C++ class per TS class, the same member and method names, the same
algorithms and the same cycle accounting, so that running the same firmware in
both and diffing `--trace-every` output can prove it cycle-identical.

Do not improve behaviour. A TS bug is ported as a bug (and may get a comment).

## Build and run

```sh
cmake -G Ninja -S emu/rp2040 -B build/emu-native   # RP2040JS_DIR=... if the SDK is elsewhere
ninja -C build/emu-native
build/emu-native/rp2040run build/rp2040/emu_nested.elf \
    --until 'NEST (PASS|FAIL)[^\n]*\n' --max-ns 500e6 --toggle-gpio 2:997
```

Build options (plain `cmake` + `ninja` needs none of them). The library is
compiled twice: `rp2040emu` (plain `-O2`; what `emu/machine` links, and
`test_periph_diff`, whose `-Wl,--wrap` of `RP2040::setInterrupt` needs the
calls between object files) and `rp2040emu_fast`, which `rp2040run`,
`rp2040emu.node` (through `rp2040harness_fast`) and the other test drivers
link, with

- `-DRP2040EMU_LTO=ON` (the default where the compiler supports it):
  link-time optimisation;
- `-DRP2040EMU_NATIVE=ON`: `-march=native` (off by default: the binaries then
  need this kind of CPU);
- `-DRP2040EMU_PGO=generate|use` with `RP2040EMU_PGO_DIR`: profile-guided
  optimisation (GCC). `emu/rp2040/tools/pgo.sh [build dir] [-D...]` does it
  all: an instrumented build in `<dir>-pgogen`, trained by `rp2040run` on the
  gpu (also with the slot pins moving), io, sysctl and self-test images, then
  `<dir>` rebuilt with the profile.

Everything is compiled with `-ffp-contract=off`: the float arithmetic must
round as JS's does, so no fused multiply-adds (which `-march=native` offers).

`rp2040run <elf> --until <regex> --max-ns <ns> [--mhz N] [--core1-slow F]
[--toggle-gpio PIN:EVERY_N_CYCLES] [--trace-every N]` is
`test/emu/rp2040emu.mjs` in C++: B1 bootrom (extracted from
`rp2040js/demo/bootrom.ts` at build time), the ELF's `PT_LOAD` segments with a
flash `paddr`, `core0.PC = 0x10000000`, `nsPerCycle = 1000 / mhz`, the same
`step()` / `cycles()` / `runUntil()` loop (PIO stepped every cycle, the idle
path capped at 1000 ns), UART0 collected. It prints the UART0 text and exits 0
if `<regex>` (ECMAScript syntax, searched like `RegExp.test`) matched, else 1.
`--toggle-gpio` is `run_nested.mjs`'s `onCycle` hook;
`--core1-slow` is the `core1Slow` option. `--trace-every N` prints
`<ns> <pc0> <pc1>` to stderr after every Nth `step()`; the matching JS line is
`` `${emu.ns} ${hex8(mcu.core0.PC)} ${hex8(mcu.core1.PC)}` `` with
`hex8 = (v) => (v >>> 0).toString(16).padStart(8, '0')`.

Output of the library: `librp2040emu.a`, include directory `src/`, namespace
`rp2040js`.

## Card-test harness and Node addon

`harness/` (C++20, `librp2040harness.a`, namespace `rp2040js::harness`) is the
test bench side, reusable from C++: `emu.h` is `test/emu/rp2040emu.mjs`'s Emu
loop (bootrom, ELF loading, `step`/`cycles`/`runUntil`, an `onCycle` hook);
`slothost.h` is `test/emu/slothost.mjs` (the slot's SPI master; its
byte/select/deselect/frame/read generators are coroutines with the same waits
and pin changes, and a script is a callback run between operations);
`tmds.h` is `test/emu/tmds.mjs`'s capture. `node/rp2040emu_node.cpp` wraps
them as `build/emu-native/rp2040emu.node` (built when Node's headers are
found), which `test/emu/rp2040native.mjs` turns into drop-in Emu, SlotHost,
TmdsCapture, UsbKeyboard and USBCDC classes. The card tests pick it with
`CUPC8_EMU=native` (`test/emu/emu_backend.mjs`):

```sh
CUPC8_EMU=native node test/emu/test_gpu.mjs GPU-004     # also GPU-005, test_io.mjs, test_sysctl.mjs
CUPC8_EMU_TRACE=1 node test/emu/test_io.mjs 2> js.trace  # every runUntil's ns, host frame, TMDS digest
```

The two backends give byte-identical `CUPC8_EMU_TRACE` output on GPU-004,
GPU-005, IOC-004 (with `DEBUG=1`) and SYS-006.

## SD card model (not in rp2040js)

`harness/sdcard.h` is an SD memory card in SPI mode and the storage card's
microSD socket (`doc/hardware/storage-card.md`): `SdSocket` answers SPI1's
frames (`RPSPI::onTransmit`) after their real duration at the programmed SCK
rate, reads nCS from GPIO13 (a SIO output; SPI1's own CSn is refused, as a
real card would misbehave), drives card detect on GPIO17 and backs the card
with an image file (blocks written through when their busy time ends).
`SdCard` is the protocol, checked against the SD Physical Layer Simplified
Specification section by section (the header lists what is modelled and
where the spec says so); host mistakes are recorded in `violations`.
Tests: `test/sd/test_sdcard.cpp` and `test/emu/test_sdspi.mjs` (EMU-008),
`test/emu/test_storage.mjs` (STO-010), `test/emu/test_e2e.mjs` E2E-007.
From Node: `SdSocket` in `test/emu/rp2040native.mjs`, `m.sd` in
`test/emu/machinenative.mjs` (the machine's `storage` slot kind).

## Verification

Every module has a seeded differential harness against the patched rp2040js
(`test/diffs.sh`, catalogue EMU-005), and the whole chip is cycle-identical to
it on real firmware: the same `(ns, pc0, pc1)` trace every 97 steps and the
same UART output on the EMU-001/002 self-tests and the GPU, IO and system card
images (`test/trace/tracediff.sh`, EMU-004). The self-tests run 20-40x faster
than in rp2040js.

## Speed without changing behaviour

The port stays line for line with TS, with a few places where it takes a
shortcut that is exact (same results, same calls, same order; EMU-004/005/006
prove it):

- **PIO fast path** (`RPPIO::sync`, pio.cpp's comments have the argument).
  While every enabled machine of a block is either stalled on a WAIT that
  only a syncing event can end, or a *runner* (divider 1, autopull, every
  reachable instruction an OUT to PINS/X/Y/NULL/PINDIRS/PC/ISR with one bit
  count and no delay: PicoDVI's `out pc, 1` serialiser), and the runners'
  pins are disjoint, listener-free and muxed to the block, `step()` only
  counts cycles. Its autopull cycle runs every machine's real `clockTick()`
  (the pull's FIFO, DREQ and interrupt effects happen as they would), and a
  TX FIFO write to a runner does not leave the fast path. What is owed —
  the runners' registers and pins, stalled machines' divider phases, and
  `checkForUpdates` for every pin that changed (with no listeners that only
  sets `lastValue`) — is replayed by `sync()`, which every way in calls
  first: the block's bus registers, `GPIOPin`'s PIO output functions,
  `setInputValue`, `addListener`, IO_BANK0 ctrl and PADS writes. **C++ code
  that reads PIO machine or pin fields directly must call
  `RP2040::syncPIO()` first** (test_pio_diff does). A pull whose
  `FIFO::onPull` is set only stays on the fast path if the hook sets
  `onPullRecordsOnly` (it must not read or change the chip; TmdsCapture's
  does). `RPPIO::fastPath = false` turns it off; `lazyCycles`/`lazyEvents`
  count it (`RP2040RUN_STATS=1 rp2040run ...` prints them). `stepPIOs()` is
  Emu.cycles' PIO loop with the lazy stretches done in bulk.
- The Cortex-M0 decode is a 64K-entry handler table (`decodeTable`, by first
  halfword). The TS if/else chain is split, by a script, into its branches'
  conditions (`decodeCond<k>`) and bodies (`exec<k>`), verbatim; entry
  `opcode` is the handler of the first branch whose opcode test can hold
  (`decodeEntry`, the chain's own conditions), which runs that branch and,
  if its opcode2 term fails, the rest of the chain (`chain(k + 1)`). So every
  opcode runs the branch the chain would. `test_decode` (EMU-005 `decode`)
  checks the table exhaustively (all opcodes; all second halfwords of the
  32-bit ones) and executes every opcode through the table and through the
  plain chain (`executeInstructionChain()`, the reference) from the same state.
  The table is `constexpr` (built at compile time).
- Instruction fetch (`CortexM0Core::fetch16`) reads SRAM, flash, its XIP
  mirrors (0x11-0x13) and the bootrom directly, as `readUint16`'s own fast
  paths and its aligned-word fallback do (no side effects there); anything
  else (and, to keep the bounds simple, the last halfword of flash and of
  the bootrom) takes `readUint16`.
  Nothing is cached, so writes need no invalidation. core-diff runs blocks
  from SRAM, flash, the three mirrors and the bootrom, and now and then
  fetches at the end of a memory or outside every memory.
- The core's own bus accesses (`CortexM0Core::readUint32` etc.) take the
  chip's SRAM and flash branches directly: an aligned SRAM or flash (and
  mirror) word read, `readUint16`/`readUint8` from flash or SRAM, and
  stores to SRAM (which has no peripheral in `findPeripheral`); anything else
  goes through `RP2040::readUint32` etc. as before.
- `RP2040::runSteps(limit, stopNanos, clock, nsPerCycle)` is the Emu loop
  (rp2040emu.mjs's `step()` and `cycles(n)` without an `onCycle` hook: the
  idle path, `step()`, `stepPIOs`, `clock.tick`) as one function with the
  instruction inline; `Emu::runUntil` (`Emu::steps(64)`), `Emu::runTo(t)`
  (`while (ns() < t) step()`) and rp2040run (runs of steps between trace
  points) use it. `test_runsteps` (EMU-005 `steps`) runs every card image
  by `Emu::step()` and by runSteps in random runs and compares the chips.
  There is no decoded-instruction cache: decoding is one table load and the
  fetch one direct load, and an idealised cache (SRAM, never invalidated)
  measured 0.4% fewer instructions and ~1% less time on gpu.elf, not worth
  an invalidation scheme.
- `toUint32`/`jsMathRound` go through int64 where that is exact
  (`test/js/test_js_numbers.cpp`); Timer32 keeps `baseFreq / prescaler`.
- `RPSIO::selectCore` defers the divider/interpolator bank swap to the next
  SIO access (code reading those fields directly calls `flushSelect()`).
- Inline common cases: `CortexM0Core::setInterrupt`, alarm unlinking, FIFO
  wrap-around, `checkInterrupts`' single `intRaw()`.
- The step loop is inline: `RP2040::step()` (reading the cores' `waiting`
  flags directly), the Emu's `step()`/`cycles()` (the idle path and the
  `onCycle` loop out of line), and `SimulationClock::tick`, which only walks
  the alarm list when the next alarm is due (`fireAlarms`).

## Status

| TS module | C++ | state |
|---|---|---|
| rp2040.ts, sio.ts, interpolator.ts, gpio-pin.ts, irq.ts, simulator.ts | `src/` | ported |
| peripherals/{peripheral,clocks,reset,psm,io,pads,ssi,busctrl,syscfg,sysinfo,tbman}.ts | `src/peripherals/` | ported |
| clock/{clock,simulation-clock}.ts, utils/{fifo,logging,time,bit}.ts | `src/clock/`, `src/utils/` | ported |
| cortex-m0-core.ts, peripherals/ppb.ts | `src/`, `src/peripherals/` | ported; `test/core` |
| peripherals/pio.ts | `src/peripherals/` | ported; `test/pio` |
| peripherals/{dma,uart,spi,i2c,timer,watchdog,rtc,adc,pwm}.ts, utils/timer32.ts | `src/peripherals/`, `src/utils/` | ported; `test/periph` |
| peripherals/{usb,usb-host}.ts, usb/{cdc,setup,interfaces}.ts, test/emu/usbkbd.mjs | `src/peripherals/`, `src/usb/` | ported; `test/usb` |

Not ported: gdb/*, utils/assembler.ts, utils/pio-assembler.ts, clock/mock-clock.ts,
index.ts, the specs.

A stub `.cpp` has every method, each with its TS source pasted in as a
`// TODO(port)` comment. Methods that firmware reaches through the bus
(`readUint32`/`writeUint32`, `DPRAMUpdated`, `executeInstruction`, PIO
`step`/`clockTick`) call `TODO_PORT_ABORT`, so nothing runs silently on a
half-ported chip; constructors and `reset()` are no-ops so the chip can be
built. Porting a file means replacing those bodies; keep the header's public
surface unless you own every user of it.

## Porting rules

**Files.** One `.h`/`.cpp` pair per TS module, at the same path and with the
same name as the TS file (`src/cortex-m0-core.ts` → `src/cortex-m0-core.{h,cpp}`,
`src/peripherals/usb-host.ts` → `src/peripherals/usb-host.{h,cpp}`). Everything
is in `namespace rp2040js`. Exception: `enum DREQChannel` lives in
`peripherals/dreq.h` (it is in dma.ts) so that uart/spi/pio/adc need not
include the DMA header. `utils/js.h` (not a TS module) holds the JS-semantics
helpers.

**Structure.** Names, structure and control flow follow the TS line for line
where practical; keep the TS comments. A class's fields keep their TS order
where C++ construction order can observe it. Module-level `const`s become
`static constexpr` in the `.cpp` (inside the namespace); only what another
module imports goes in the header. If a file-local name clashes with a
header's, the header wins (the TS imports it from there anyway); rename
locals that are C++ keywords with a trailing underscore (`register_`,
`signed_`).

**Numbers.**
- A `number` used as a 32-bit register/value → `uint32_t`; `int32_t` where the
  TS does signed arithmetic via `| 0` / `s32()` and the sign is observable.
- Nanosecond times, frequencies, and counters that TS computes with floats
  (Timer32, clock, `cycles`, the chip's `coreTime`) → `double`, exactly as the
  JS number. Never "simplify" a float expression to integers unless you can
  show it is exact.
- `x >>> 0` → `toUint32(x)` for a double, nothing for a `uint32_t`;
  `x | 0` → `toInt32(x)`; `Math.round` → `jsMathRound` (half rounds up, unlike
  `std::round`); `Math.floor` → `std::floor`. JS takes shift counts `& 31`
  (`jsShl`, `jsSar`, `jsShr`); a C++ shift by ≥ 32 is undefined.
- A JS value that can leave the 32-bit range (`reg + carry`, `accum += value`,
  a float quotient) must be computed in `double` (or `int64_t` where provably
  identical) and converted where the TS converts it (a `Uint32Array` store is a
  ToUint32). Comment each such spot.
- Values on the bus (`readUint32` results, `writeUint32` values) are
  `uint32_t`. A few TS producers pass a negative int32 (`writeUint8`/`16`
  byte replication with bit 7 set, DMA byte swap); consumers only see the
  same 32-bit pattern. That differs from TS only if a consumer does
  non-bitwise math on `value` (compare, add a float); flag any such place with
  `// JS-SIGN:`.
- Byte arrays → `std::vector<uint8_t>`/`std::array`; `DataView` and typed-array
  views → `loadLE32`/`storeLE32`/`loadLE16`/`storeLE16`. `Uint32Array(n)` →
  `std::array<uint32_t, n>{}`.

**Getters and setters.** `get foo()` → `T foo() const` (non-const if it has
side effects); `set foo(v)` → `void setFoo(T v)` (first letter upper-cased:
`set xPSR` → `setXPSR`, `set en` → `setEn`). Call sites change from `x.foo`
to `x.foo()` and from `x.foo = v` to `x.setFoo(v)`. Plain fields stay fields.

**Callbacks.** TS callbacks and arrow-function hooks (`onByte`, `onBreak`,
alarm callbacks, pin listeners, `onTransmit`, ...) → `std::function` members
(empty = `undefined`, so `this.onByte?.(v)` → `if (onByte) onByte(v)`). An
arrow-function *field* that is really a method (`transfer = () => {...}`,
`handleAlarm`, `update`) → a method; where it is passed as a callback, pass
`[this] { method(); }`. Objects that hand out `this` (alarms, listeners) are
non-copyable and non-movable; hold them by value in their owner (arrays via
brace initialisers) or in a `unique_ptr`.

**Clock and alarms.** `IClock::createAlarm` returns `std::unique_ptr<IAlarm>`;
the peripheral owns it, the clock only links it. `SimulationClock` keeps the
TS linked list exactly (equal-time alarms: a later `schedule()` goes first; a
fired alarm keeps `scheduled == true`). The clock must outlive the chip.

**No exceptions for control flow, no globals.** Everything is owned by the
`RP2040` object, so chips can run on separate threads. The only throws
mirror a JS throw that ends the run: `ConsoleLogger::error` with
`throwOnError` (as the TS logger throws `Error`) and DataView/TypedArray
`RangeError`s. `console.warn`/`console.error` calls in the TS (not via the
logger) → `consoleWarn`/`consoleError` (stderr). The logger prints every level
to stderr (node sends debug/info to stdout; here stdout is the UART).

**Harness hooks.** Where the JS harness monkey-patches an instance, the C++
has an explicit hook: `RPPIO::run` is a `std::function` (the host sets it to a
no-op and steps PIO itself; there is no `setTimeout`), and
`CortexM0Core::executeInstructionOverride`, when set, is called by
`RP2040::step()` instead of `executeInstruction()` (`--core1-slow`).
Two more, empty by default and not in rp2040js: `FIFO::onPull` is called with
every value `pull()` returns (test/emu/tmds.mjs wraps the PIO TX FIFOs'
`pull`), and `RPPPB::onWrite(offset, value)` at the start of every PPB
`writeUint32` (rp2040emu.mjs's `ppbWriteTrap` wraps `ppb.writeUint32`).

## Differences from TS that cannot be avoided

- `GPIOPin`'s `lastValue = this.value` runs before `ctrl`/`padValue` exist in
  TS, giving `GPIOPinState.Input`; the port initialises it to that.
- Listener sets (`Set<GPIOPinListener>`) cannot deduplicate `std::function`s;
  adding the same listener twice calls it twice.
- `RPPIO.run` and `Simulator.execute` do one batch instead of re-arming with
  `setTimeout`.
- `RP2040.flash16` is not ported (nothing in the chip uses it).
- `RP2040.logger` is declared before the peripherals (TS initialises it after
  them; TS would crash if a constructor logged).

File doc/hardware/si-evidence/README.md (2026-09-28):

# Field-model run reports

These JSON files are generated by `hw/si/openems_usb_io.py` and
`hw/si/openems_gpu_d0.py` from provenance-checked IO and GPU pipeline boards.
Each report records its exact board hash and, for FDTD runs, the generated
field XML and run-log hashes. The USB report also records the netlist hash and
raw port-trace hashes. The large field and port files remain under ignored
`build/hw/si/`; the commands and interpretation are in
[`../si-models.md`](../si-models.md).

`gpu-d0-legacy-reprocessed.json` and `gpu-d0-pml-short.json` are deliberately
rejected diagnostic runs. The geometry reports run no FDTD. Even an accepted
diagnostic S-parameter report does not close the full row 4.6 SI gate.
`gpu-d0-pml-fixed.json` is the completed, boundary-safe D0 copper-subset run;
`usb-io-pml-fixed.json` is the completed IO USB copper-subset run.
`gpu-d0-boundary-comparison.json` recomputes both D0 spectra with the same
9.8 ns Fourier cutoff on the same board and records the hashes of every raw
port trace used.
`gpu-four-pair-summary.json` links the completed D0, D1, D2 and CK reports
on the PML-safe grid. Its `all_four_subset_pass` flag covers the separate
routed-copper models only; it does not certify coupling or the full HDMI
path.
`usb-io-pml-mesh-090-fixed.json` is a completed coarser-grid run with the
same IO board; `usb-io-mesh-comparison.json` records its exact S-parameter
differences from the 0.075 mm report. Two grids quantify sensitivity but do
not establish mesh convergence.

`board-migration.json` binds those six saved field models to the final GPU
and IO board receipts. The full PCB and IO netlist hashes changed after the
mask/STEP verifier and card-local silkscreen rebuilds. The migration checker validates both receipts,
compares every modeled copper segment and USB endpoint, regenerates each
field XML, and matches a solver-relevant XML fingerprint against the saved
field XML. The fingerprint preserves the grid, dielectric, ground, copper,
ports and excitation. It ignores CSXCAD's random display colors and the
insertion order of same-priority copper polygons. A separate fingerprint
also matches both boards' tracks, vias, copper zones, footprints, layers and
outline after UUID removal and one redundant GPU zone vertex normalization.
The changed solder-mask setup and footprint silk graphics are outside the copper fingerprint. No new FDTD run was needed
for those equivalent field inputs. The saved reports retain their archived
board hashes; this migration is the explicit link to the current receipts.
It does not close full row 4.6 or USB mesh convergence.
`board-migration-pre-silk.json` preserves the preceding receipt comparison;
the interrupted 0.060 mm run names its IO receipt. The final migration is
`board-migration.json`.

`usb-io-pml-mesh-060-interrupted.json` records the attempted finer-grid run
on the earlier rebuilt IO receipt (before the final silk-only rebuild).
Routing contention left only 22,190 of 250,000
steps (1.455 ns) after 16 minutes, so the solver was stopped. Its field
XML, log, stats and partial port-file hashes are recorded. It has no valid
S-parameters and must not be included in a mesh-convergence comparison.
`usb-io-complex-port-comparison.json` independently transforms the saved
0.075/0.090 mm raw port traces at the same 16 ns cutoff. It records complex
S11/S21 and the 90 Ω terminated loaded input impedance, plus their mesh
differences. Loaded input impedance is not trace characteristic impedance.

`ibis-source-routed-snapshot.json` audits the pinned Lattice source against
the waveform fixture and threshold/voltage constants used by the diagnostic,
then validates archived main and CPU board receipts, the TQ144 pin table,
source resistors and planar copper paths. It binds the old 96-case diagnostic
and a second 96-case sweep using both commented vendor TQ144 typical R/L/C
rows by report hash. The raw vendor IBIS remains in ignored `build/` under
its license. Neither report substitutes routed branch topology into ngspice
or closes physical bus SI.

`board-migration-post-shared-tool.json` rebinds the six earlier PML-safe GPU/IO
field inputs to the shared-tool rebuilt card receipts.
`usb-io-pml-mesh-060-fixed.json` is the completed finer-grid USB subset run.
`usb-io-060-receipt-migration.json` validates its raw field hashes and exact
modeled-input equivalence on the rebuilt IO receipt.
`usb-io-three-mesh-comparison.json` compares all three receipt-bound meshes;
it measures sensitivity but does not establish asymptotic convergence or close
row 4.6.

`ibis-current-route-top.json`, the two `ibis-current-route-*.json` diagnostic
sweeps and `ibis-current-route-source-audit.json` bind the pinned vendor model
and source-pin copper paths to earlier main/CPU receipts. The waveform line
models still use assumed lengths and loads, so the audit does not certify
physical bus SI.

`ibis-final-top.json`, `ibis-final-source-audit.json` and
`ibis-final-receipts.json` refresh the top and source copper audit against
canonical main/CPU, all seven card receipts and the canonical system routed
board. They do not rerun the earlier assumed-line
ngspice diagnostics. The source/path check is current; analog bus SI remains
open.

`usb-io-three-mesh-complex-port.json` checks the three runs against their
raw port traces at 16 ns and quantifies complex reflection and loaded input
impedance sensitivity. Loaded input impedance is not characteristic impedance.

`gpu-coupled-d0-fixed.json`, `gpu-coupled-d1-fixed.json` and
`gpu-coupled-d0-d1-audit.json` bind two four-port adjacent HDMI D0/D1
excitations to the final GPU receipt and every saved raw port trace. This
quantifies copper-subset cross response and reciprocal consistency; it does
not close the physical TMDS path or row 4.6.

`gpu-coupled-d2-fixed.json`, `gpu-coupled-ck-fixed.json` and
`gpu-coupled-d2-ck-audit.json` preserve two PML-safe reciprocal D2/CK
field runs on the final GPU receipt. Their 100 MHz weak cross-port spectrum
fails the 0.05 dB stability gate in both 8–12 and 12–16 ns comparisons, so
these are rejected diagnostics. The audit hashes both XML/log files and all
16 raw port traces; it does not mark the coupled subset valid.

`gpu-coupled-d2-long-fixed.json`, `gpu-coupled-ck-long-fixed.json` and
`gpu-coupled-d2-ck-long-audit.json` extend the same physical D2/CK XML to a
26.740 ns fixed window. Both copper-subset numerical gates pass; the audit
independently checks raw traces, spectral drift and reciprocal response.
`gpu-coupled-final-receipt-migration.json` validates all six coupled field
runs against the canonical GPU receipt by full physical fingerprint and
regenerated solver-input equality. These records omit the full four-pair
interaction and the actual HDMI launch, loss and source/sink models; row 4.6
remains open.

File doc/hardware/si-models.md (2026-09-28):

# Signal-integrity models in progress

The [run reports and matched-window comparison](si-evidence/README.md)
record board, field XML, run-log and port-trace hashes for the bounded
studies below.

`hw/si/openems_gpu_d0.py` reads the GPU card's routed KiCad board and models each of the four HDMI TMDS pairs independently, from a source resistor pack to J1, in openEMS (`--pair d0|d1|d2|ck`). The input must be a completed GPU pipeline build when run by `SI-003`; its board receipt and file hashes are checked before simulation. Each JSON result records the board SHA-256 and the field-energy decay.

The selected [JLC04161H-7628 stackup](https://jlcpcb.com/impedance) puts 0.2104 mm of 7628 prepreg (Dk 4.4) between top copper and the L2 ground plane. The model uses those values, a rectangular L2 ground plane, lossless dielectric, and ideal copper. It excites and terminates the pair with two 100 Ω lumped differential ports on the z=0 copper plane, then derives S11 and S21. [openEMS warns](https://docs.openems.de/en/latest/concepts/ports.html) that lumped ports can perform poorly on differential pairs; these results remain diagnostic pending mesh and port sensitivity checks. The script rejects results where |S11|² + |S21|² exceeds 1.001 or the nominally matched passive port has an incident wave exceeding 1% of the driven port's incident wave at any sampled frequency. These small numerical margins are basic consistency checks, not complete port calibration. It also fails if either route disconnects, changes layers, or adds a via (those changes need new geometry, not a silent approximation).

This is a subset, not `GC-007`. The pairs are solved separately, so inter-pair coupling is absent. Exact pad and HDMI connector metal, solder mask, finite copper and dielectric loss, and source/sink behavior are also absent. The reported S21 therefore cannot certify the real insertion-loss budget, and S11 includes the model's launch discontinuities. The script's `--straight-control` option keeps the same ports and endpoints while replacing bends and width changes with straight 0.2 mm tracks; a mesh/port sensitivity run is still needed before using the model to judge impedance. `GC-007` and the row 4.6 system gate remain pending.

To audit the corrected geometry after building the GPU board, then repeat
the bounded four-pair subset:

```sh
for pair in d0 d1 d2 ck; do
  python3 hw/si/openems_gpu_d0.py --pair "$pair" --board build/hw/gpu/gpu.kicad_pcb \
    --out "build/hw/si/gpu-$pair-pml-geometry.json" --pml-clearance-mm 1 \
    --geometry-only --require-evidence
done
python3 hw/si/openems_gpu_d0.py --pair d0 --board build/hw/gpu/gpu.kicad_pcb \
  --out build/hw/si/gpu-d0-pml-fixed.json --pml-clearance-mm 1 \
  --fixed-window --max-steps 126000 --threads 4 --require-evidence
for pair in d1 d2 ck; do
  python3 hw/si/openems_gpu_d0.py --pair "$pair" --board build/hw/gpu/gpu.kicad_pcb \
    --out "build/hw/si/gpu-$pair-pml-fixed.json" --pml-clearance-mm 1 \
    --fixed-window --max-steps 126000 --threads 1 --require-evidence
done
```

On a fresh, provenance-checked GPU board (SHA-256 `95fa5811164a2fb367d8bf085ae1cfb91ced5320b8bb77a9227961c85535c9fa`), the original lumped-port boxes extending from z=-0.05 to +0.05 mm reached -40.06 dB in 87,200 steps on openEMS v0.37.0-rc3-1-g65f8771. At 1.26 GHz they gave S11 -10.66 dB and S21 -0.26 dB, but their squared magnitudes summed to 1.027414, violating passive two-port power balance by 2.74%. The unexcited port had |uf_inc,2/uf_inc,1| about 0.18 and measured -U2/I2 about 145.4 Ω across 0.1–1.26 GHz, despite a declared 100 Ω load. Those data fail the new validity gates.

Changing only the lumped-port boxes to two-dimensional surfaces at z=0 kept the same board, traces, substrate, 0.05 mm x/y mesh, and 100 Ω port resistors. That comparison run reached -40.14 dB in 96,792 steps. Its passive port measured 99.94 - j0.15 Ω at 1.26 GHz, with |uf_inc,2/uf_inc,1| = 0.000775. At that frequency S11 was -12.45 dB and S21 was -0.54 dB, with squared magnitudes summing to 0.939621. The comparison isolates the port thickness as the cause of the 145 Ω mismatch on this mesh.

The routed GPU board used for the four exploratory runs is SHA-256 `86185894b9863e53bdbc19ff3b0940147180a36fb3725be38f39f54d2479b66f`. Each reached at least -40 dB field-energy decay, and all four sampled frequencies passed the port consistency and passive power checks. At 1.26 GHz:

| Pair | Steps | S11 | S21 | Power sum |
| --- | ---: | ---: | ---: | ---: |
| D0 | 102,678 | -12.44 dB | -0.54 dB | 0.939592 |
| D1 | 107,692 | -12.06 dB | -0.57 dB | 0.939937 |
| D2 | 104,640 | -12.34 dB | -0.54 dB | 0.941130 |
| CK | 102,678 | -12.56 dB | -0.52 dB | 0.943002 |

The rebuilt GPU package had a valid pipeline receipt and board SHA-256 `9bd334fb357846039ba6d0ae36a49c3d48630778e5827e729cc34401207c6362`. Running `--postprocess-only --require-evidence` for each pair regenerated byte-identical field geometry against that board and reproduced the four saved-field results above. A later PML audit found those legacy results cannot close `SI-003`: the rectangular dielectric and L2 ground reached every x/y PML boundary, the L2 plane lay inside the lower eight z cells, and the top copper sat at the upper PML inner edge. The four values above are retained as historical diagnostics. The runner now refuses to mark a result valid when physical material enters PML and requires an 8–12 ns port-spectrum stability comparison. A new `--pml-clearance-mm 1` option extends the air/PML grid without moving the routed copper, dielectric or ground.

On the current provenance-checked GPU board SHA-256
`2d36c983527678daf64f8d2ba2a773eee1eceaaebc4e85560348f39172822031`,
geometry-only checks for D0, D1, D2 and CK all report
`pml_geometry_ok: true` with a 1 mm air clearance and false with the legacy
boundary. D0's corrected grid is 121×227×34 cells. A bounded D0 run reached
−40.08 dB after 10,246 steps, about 0.98 ns; its port and passive-power
checks passed, but that trace is too short for the 8–12 ns spectrum audit.
Its nominal 1.26 GHz S11/S21 of −20.62/−0.038 dB are therefore exploratory,
not accepted `SI-003` evidence. The large change from the legacy numbers
shows why boundary placement must be controlled before comparing route
impedance. The subsequent fixed-window D0 rerun below accepts this one
copper-only subset; the other three pairs and mesh sensitivity remain open.

The saved legacy D0 fields also match that exact current board. Reprocessing
them reports `pml_geometry_ok: false` and a 9.85 ns trace, too short for the
new 12 ns window. A matched 9.8 ns Fourier cutoff on those traces and the
completed corrected D0 trace gives S11/S21 at 1.26 GHz of −12.443/−0.542 dB for the
legacy boundary and −20.615/−0.0378 dB for the corrected boundary. Routed
copper, ports, material coordinates and the interior x/y grid phase are held
fixed; the boundary clearance and extra z cells cause the difference. The
corrected 140,000-step run was externally interrupted at 137,558 steps
(13.14 ns), so it has no solver completion record. Its saved 8–12 ns port
traces nonetheless drift by at most 0.000023 dB across S11 and S21 at the
four sampled frequencies. This is a useful boundary diagnosis, not a
completed `SI-003` run.

A shorter fixed-window D0 rerun completed at 126,000 steps (12.03 ns) with
last sampled field energy −95.01 dB. Its maximum 8–12 ns S11/S21 drift is
0.000023 dB against the 0.05 dB limit; PML geometry, passive power and
passive-port checks pass. At 1.26 GHz, S11 is −20.6154 dB, S21 is
−0.03775 dB, and the power sum is 1.000024. Reprocessing the saved fields
reproduced byte-identical XML (SHA-256
`6c60b4d3ed307a0034b710f4e3ac8a72e74d6f77877f79fdc695b093bb5c084c`)
and `valid_for_si_evidence: true` for this **D0 routed-copper subset**.

The same provenance-checked GPU board then completed PML-safe fixed-window
runs for D1, D2 and CK. Each used one solver thread, a 126,000-step cap,
the same 12.03 ns duration and a 133×227×34 grid. Saved-field
postprocessing reproduced byte-identical XML for every pair. The
[four-pair summary](si-evidence/gpu-four-pair-summary.json) links each full
report and its board, XML and run-log hashes:

| Pair | Final field energy | Maximum 8–12 ns drift | S11 at 1.26 GHz | S21 at 1.26 GHz | Power sum |
| --- | ---: | ---: | ---: | ---: | ---: |
| D0 | −95.01 dB | 0.000023 dB | −20.615 dB | −0.03775 dB | 1.000024 |
| D1 | −95.24 dB | 0.000081 dB | −20.604 dB | −0.03779 dB | 1.000038 |
| D2 | −96.08 dB | 0.000123 dB | −20.178 dB | −0.04169 dB | 1.000045 |
| CK | −96.30 dB | 0.000045 dB | −20.383 dB | −0.03983 dB | 1.000027 |

All four pass the model's PML, −40 dB field, 0.05 dB spectral, passive
power and passive-port checks. This closes `SI-003` for its stated four
**independent routed-copper pairs**. It does not close `GC-007` or row 4.6:
pair coupling, mesh and port sensitivity, finite loss, pads, connector metal
and source/sink behavior remain unmodeled.

### Adjacent D0/D1 four-port copper model

The [coupled-field audit](si-evidence/gpu-coupled-d0-d1-audit.json) binds two
[GPU D0](si-evidence/gpu-coupled-d0-fixed.json) and
[D1](si-evidence/gpu-coupled-d1-fixed.json) excitations to final GPU receipt
`5c7808f1f5294b09e289feb08b5f138583fd5bf411bca826e8ef9410fde42575`.
The model places both routed differential pairs, four 100 Ω lumped ports,
the common lossless dielectric, and L2 ground in one PML-safe 167×227×34
grid. Each excitation ran 180,000 steps (17.190 ns) with two threads. Final
field energy was −104.98/−106.57 dB. Both pass the PML, power-balance,
passive-port and 8–12 ns spectral checks; the largest spectral drift is
0.00135/0.00202 dB. The audit verifies both source hashes, receipts, XML,
logs, all 16 raw port files, and identical passive geometry after removing
only excitation and CSXCAD-generated property IDs.

| Frequency | D0→D1 source | D0→D1 load | D1→D0 source |
| --- | ---: | ---: | ---: |
| 100 MHz | −67.86 dB | −75.33 dB | −67.86 dB |
| 480 MHz | −54.33 dB | −61.88 dB | −54.33 dB |
| 800 MHz | −49.92 dB | −57.54 dB | −49.92 dB |
| 1.26 GHz | −46.07 dB | −53.82 dB | −46.07 dB |

The reciprocal source-to-source complex responses differ by at most
4.45×10⁻⁷ in linear magnitude. This is an adjacent D0/D1 **routed-copper
subset** result. The D2 and CK conductors, pads, connector, solder mask,
finite loss, cable and actual source/sink loads are absent. Two excitations
also leave half the four-port matrix unmeasured. The field result therefore
does not establish the required ±10% impedance or insertion-loss budget for
the full TMDS path and does not close `GC-007` or row 4.6.

Reproduce with an absolute `--out` path; openEMS changes the working
directory during a field run:

```sh
python3 hw/si/openems_gpu_coupled.py --board build/hw/gpu/gpu.kicad_pcb \
  --source-root . --excite-pair d0 --max-steps 180000 --threads 2 \
  --out "$(pwd)/build/hw/si-current/gpu-coupled-d0-fixed.json"
python3 hw/si/openems_gpu_coupled.py --board build/hw/gpu/gpu.kicad_pcb \
  --source-root . --excite-pair d1 --max-steps 180000 --threads 2 \
  --out "$(pwd)/build/hw/si-current/gpu-coupled-d1-fixed.json"
python3 hw/si/audit_gpu_coupling.py --board build/hw/gpu/gpu.kicad_pcb \
  --source . --reports build/hw/si-current --fields build/hw/si-current \
  --model-source hw/si/openems_gpu_coupled.py \
  --out build/hw/si-current/gpu-coupled-d0-d1-audit.json
```
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

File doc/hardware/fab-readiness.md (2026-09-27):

# Fab readiness (Milestone 1)

*Generated by `tools/fabready.py` from the last `make verify` (2026-09-23 00:28:27) and the board builds. Do not edit; edit `fab-waivers.md` for decisions and hand checks.*

Nothing is ordered until every row below is green and David has signed off at the bottom (`verification.md`).

## Verification rows

| Row | Artifact | Tests | State |
|---|---|---|---|
| 1.1 | ALU, SPI master (incl. SPI_CS), IRQ controller, MMU decode,  | 20 | **red**: ALU-001 not run, MMU-001 not run, MMU-002 not run, MMU-003 not run, MMU-005 not run, ROM-001 not run (+14) |
| 1.2 | CPU card (cpu.vhd) | 7 | **red**: CPU-001 not run, CPU-002 not run, CPU-008 not run, CPU-003 not run, CPU-006 not run, CPU-007 not run (+1) |
| 1.3 | CPU bus, CPU side | 5 | **red**: CPU-004 not run, CPU-005 not run, BUS-001 not run, BUS-002 not run, BUS-003 not run |
| 1.4 | Chipset and CPU bus | 5 | **red**: BUS-004 not run, MMU-004 not run, SPI-004 not run, CLK-002 not run, MUT-001 not run |
| 1.5 | Both FPGA designs, post-synthesis | 4 | **red**: RST-001 not run, RST-002 not run, SYN-001 not run, SYN-003 not run |
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

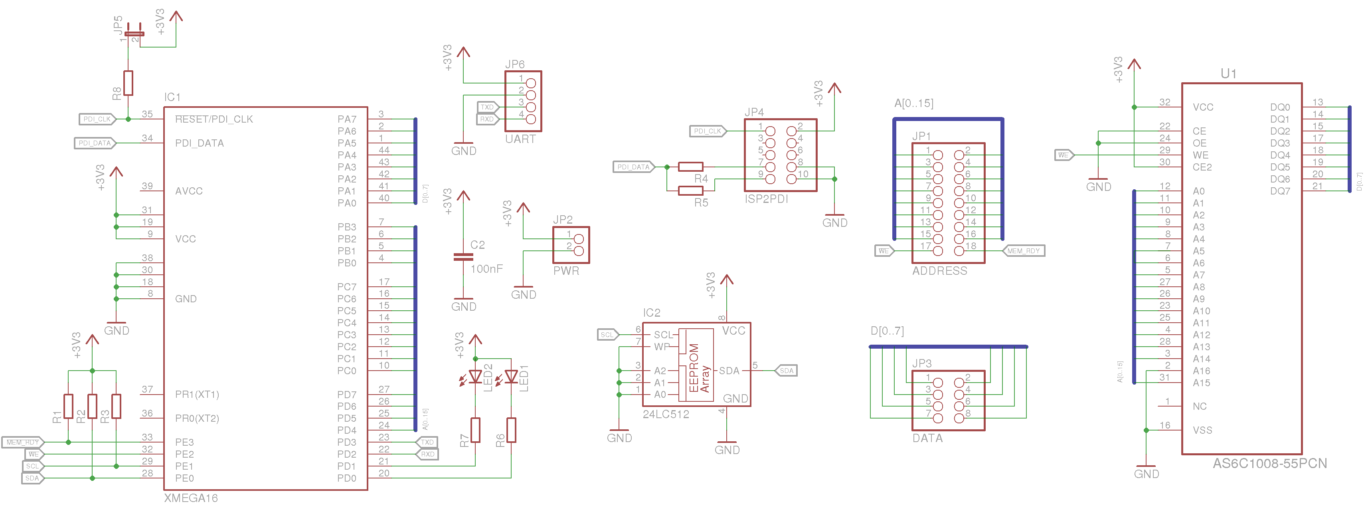
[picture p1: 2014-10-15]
pcb/memory/memory_sch.png

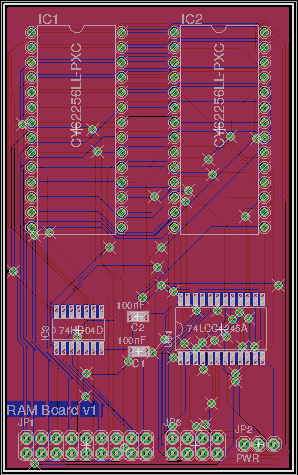
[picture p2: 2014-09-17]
pcb/memory-2chip/memory_brd.png

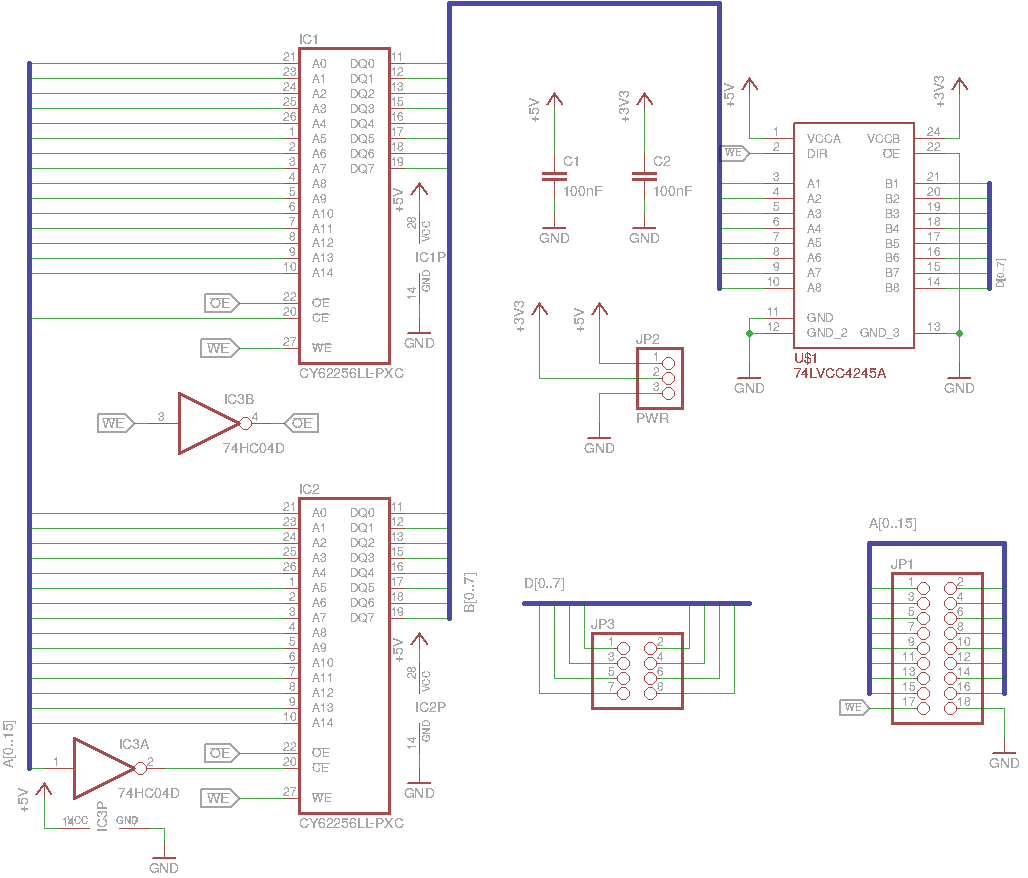
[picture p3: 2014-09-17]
pcb/memory-2chip/memory_sch.png

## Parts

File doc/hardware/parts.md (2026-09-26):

# Key parts: JLCPCB assembly availability

Stock is from JLCPCB's assembly parts library, which is what JLC can
actually place. It was checked on 2026-09-22 with `hw/tools/jlcparts.py`.
Re-run the check before ordering:

```
hw/tools/jlcparts.py check C1521989 C645939 C632851 C1348955 ...
```

"ext" means an extended part, which costs a small per-part-type loading fee.
None of the key ICs are basic parts. Passives will be chosen from basic parts
during schematic capture.

**Build quantity: 2 systems.** JLC fabricates 5 bare PCBs of each design;
we assemble **3 main boards** (one spare, since there is no prototype) and
**2 of each card** (CPU, system, GPU, IO, Wi-Fi) (JLC's minimum for assembly).
"Qty" is parts placed across all assembled boards, before JLC's attrition
extras. Stock checked 2026-09-23 (the power parts: 2026-09-24).

| Function | Part | LCSC | Stock | Qty | Board |
|---|---|---|---|---|---|
| Chipset FPGA **and** CPU card FPGA | ICE40HX4K-TQ144 | C1521989 | 51 | 5 | main, CPU |
| ROM | SST39VF040-70-4I-NHE (512 KB, PLCC-32) | C645939 | **11** | 3 | main. ⚠ low stock: fallbacks below |
| ROM (fallback) | SST39VF010-70-4I-NHE-T (128 KB, PLCC-32) | C632851 | 33 | | same footprint; A17/A18 NC, ROM_BANK 0–63, enough for boot + kernel |
| SRAM | IS62WV5128EBLL-45HLI (512K×8, 45 ns, sTSOP-32) | C1348955 | 224 | 3 | main; A16–A18 to MEM_A16–A18: banked RAM, extended-ram.md |
| FPGA config flash | W25Q32JVSSIQ | C179173 | 25,178 | 5 | main (FL0), CPU (FL1) |
| 12 MHz clock | HSO321S 12 MHz 3.3 V CMOS oscillator | C160457 | 3,086 | 3 | main: CLK12 and CPU_CLK, 33 Ω each (cpu-bus.md) |
| Reset supervisor | MAX811TEUS+T (3.08 V, 140 ms, manual reset) | C7272 | 11,115 | 3 | main: nPOR; MR from the button and SYS_nRST |
| USB-C power policy | TLV7011DBVR comparator | C702117 | 6,161 | 3 | main: PWR_HI (a 3.0 A source) when CC ≥ ~1.30 V (`power.md`, POW-005) |
| 3V3 buck | TLV62569PDDCR (2 A, SOT-23-6, 106 °C/W) | C398365 | 16,188 | 3 | main: the DBV (188 °C/W) reaches 100 °C at 1.21 A of 3V3 (THM-001) |
| 1V2 LDO | RT9013-12GB (500 mA) | C58464 | 16,404 | 5 | main, CPU |
| Input eFuse | TPS259470ARPWR (2.7–23 V, 28 mΩ, adjustable limit, OVLO, dVdt) | C3662799 | 2,749 | 3 | main input: RILM 1.13 kΩ (2.63–3.21 A), OVLO 37.4k/10.0k 0.1 %, dVdt 680 pF. Fallback: the latch-off TPS259470LRPWR, C3662793 (2,832) |
| USB power switch | SY6280AAC | C55136 | 142,696 | 2 | IO card VBUS (the main input moved to the eFuse: the SY6280 can't pass the 3 A case) |
| USB-C receptacle | TYPE-C-31-M-12 (16P) | C165948 | 98,793 | 5 | main (power), system card (USB) |
| USB ESD | USBLC6-2SC6 | C7519 | 38,417 | 5 | main, system card, IO card |
| 5V TVS | SMF5.0A | C193402 | 582,382 | 3 | main |
| Input fuse | SMD1812P350TF/16 (3.5 A PTC, 16 V, 8–30 mΩ) | C46970911 | 310 | 3 | main. Fallback: SMD1812P350TF (6 V rating), C20815 (2,858) |
| Slot +5V fuse | SMD1206P110TFT (1.1 A PTC, 0.92 A hold at 40 °C, 0.04–0.21 Ω) | C143975 | 1,442 | 21 | main: 6 slots + system slot. Up from the 0.75 A part: the IO card's keyboard boost draws up to 0.75 A at the worst corner (POW-006 B10b) |
| IO card keyboard boost | TPS61023DRLR (sync boost, SOT-563), 1 µH FXL0420-1R0-M (C167203, 27 mΩ, Isat 7 A), 750k (C23240) / 100k (C25803) 1 % | C919459 | 14,097 | 2 | IO: holds the keyboard's VBUS at 5.06 V from a card +5V down to 3.9 V (POW-007); feeds the SY6280 port switch (`power.md`) |
| CPU socket | UMAX 3183-10112P1T, PCIe x8 98-pin, THT | C404111 | 418 | 3 | main |
| I/O slot socket | UMAX 3183-10200P1T, PCIe x1 36-pin, THT | C404113 | 2,418 | 18 | main |
| System slot socket | PCIE-64P11L, PCIe x4 64-pin, SMD with posts | C19188869 | 201 | 3 | main |
| Slot control expanders | TCA9555PWR | C465732 | 39,970 | 6 | main |
| Programming-port mux | CD74HC4051PWR | C352826 | 26,017 | 6 | main |
| Card MCUs and sysctl | RP2040 | C2040 | 74,212 | 6 | system, GPU, IO |
| MCU flash | W25Q16JVSSIQ | C131025 | 17,654 | 6 | one per RP2040 |
| 12 MHz crystal | X322512MSB4SI | C9002 | 74,175 (basic) | 6 | one per RP2040 |
| Wi-Fi card 3V3 buck | TLV62569DBVR (2 A), with a 2.2 µH FNR3015S2R2MT (C167747) | C141836 | 251,932 | 2 | Wi-Fi: an LDO failed the TX-burst and thermal checks (`hw/power`, POW-003, THM-001). The system, GPU and IO cards run from the slot's +3V3 (`power.md`). |
| HDMI connector | HDMI 19PIN 043 (type A, SMD right angle) | C2858275 | 47,920 | 2 | GPU |
| HDMI ESD | TPD4E05U06DQAR (4 lines) | C138714 | 182,893 | 4 | GPU: two, for the 8 TMDS lines |
| HDMI +5V buck-boost | TPS63802DLAR (VSON-10), 0.47 µH FXL0420-R47-M (C167200, 14 mΩ, Isat 9.5 A), 300k (C23024) / 33k (C4216) 1 %, basic | C2845237 | 18,125 | 2 | GPU: the pin at 5.045 V (HDMI: 4.8–5.3 V) whether the card's +5V is above or below it (POW-008); replaces the B5819W Schottky |
| HDMI +5V fuse | SMD0805P020TF (200 mA PTC, 0.5–3.5 Ω) | C20976 | 16,020 | 2 | GPU: ahead of the buck-boost (POW-008); the 100 mA C20975 holds only 0.08 A at 40 °C there |
| USB-A receptacle | USB-302S-T (SMD right angle) | C112455 | 3,791 | 2 | IO |
| Wi-Fi module | ESP32-C3-MINI-1U-N4 | C2911374 | 2,225 | 2 | Wi-Fi |
| Wi-Fi MISO buffer | 74LVC1G125GW | C52140430 | 9,721 | 2 | Wi-Fi: releases MISO when not selected |
| Wi-Fi antenna lead (loose, not assembled) | KH-IPEX3-SMA-RG081-150mm, MHF III (IPEX gen 3) to SMA, 150 mm | C709347 | 162 | 2 | the module's receptacle is MHF III: a 1st-gen U.FL antenna (C4943394, first listed here) does not mate (MECH-007). Buy with the order, plug in by hand |
| Wi-Fi antenna (loose, not assembled) | HJ-2.4GHz-SMA, 2.45 GHz rubber duck | C1509156 | 329 | 2 | screws onto the lead's SMA; check the lead is SMA female (jack) and the antenna SMA male, not RP-SMA, when ordering |

All of the key parts above have a JLC minimum purchase of 1. The small parts
have a minimum of 2–5 plus 1–4 attrition spares, which costs cents.

## Risks and actions

1. **ROM stock.** The whole PLCC-32 SST39VF family at JLC is under 60 parts.
   JLC can buy parts into **your JLC parts inventory** ahead of the PCB
   order, which reserves them. Do that for 3–4 × C645939 (or C632851)
   once the specs are approved. Only you can do this, because it needs
   payment.
2. **FPGAs.** 5 × HX4K out of 51 in stock. Reserve them the same way.
3. **Datasheet checks:** still to do during schematic capture, when each
   footprint is imported:
   - the connector suffixes (-10112P1T / -10200P1T: plating and post style)
   - the HDMI connector's mechanical drawing against the card edge
   - the USB-A mechanical drawing against the card edge

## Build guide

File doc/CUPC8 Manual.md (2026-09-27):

# CUPC/8 MANUAL

## 1. Introduction

> The _**C**ompletely **U**seless and **P**ointless **C**omputer / **8**_ bit.

**CUPC/8** is a simple 8-bit microcomputer designed and built by myself *(David Kaplan)* for fun over the years 2014-2016. The design is pretty dirty and 'evolved' as I added features necessary to achive the goal of a fully working, custom-designed 8-bit machine that could connect to the Internet.
The full hardware and software stacks have been designed and coded from the ground up (with the exception of certain 3rd-party open source pieces of software whch I ported over to the CUPC/8 ISA). This document serves as a manual detailing all aspects of the computer for anyone that may, however unlikely, be interested in my work in the future.

The entire project is open-sourced under a Creative Commons Attribution-NonCommercial 4.0 International license (with the exception of 3rd-party software where other licenses may apply).

## 2. System Overview
#### 2.1. Central Processing Unit SoC
The **CUPC/8** microcomputer is made up of a Central Processing Unit (a simple SoC really) implemented in VHDL and running on an FPGA. The CPU has an 8-bit data bus and a 16-bit address bus and runs a custom Instruction Set Architecture (ISA). Coupled with the CPU is a Memory Management Unit (MMU) which is responsible for memory mapping external interfaces. The last component of the CPU SoC is some Serial Peripheral Interface (SPI) logic which is used to provide an interface with external peripherals. Other than a memory-mapped 8-bit output only register hardwired to LEDs on the PCB, peripherals can only connect to the microprocessor over the SPI bus.

#### 2.2. Memory
As the CPU sports a 16-bit address bus, the maximum amount of RAM that can be addressed (without bank switching) is 64KB. This is provided by a external SRAM chip.
This RAM chip is loaded on poweron from an external ROM chip which provides the initial code to be executed by the CPU. This is necessary due to the fact that there is no code within the FPGA SoC itself and the CPU can therefore not know how to load any code directly from ROM over the SPI bus. The current memory board design has a microcontroller on board which is responsible for copying ROM into RAM on poweron. Furthermore this microcontroller can interface to another external computer and allows for RAM and ROM to be written over UART.

#### 2.3. Display
Display is piped over the SPI bus. Theoretically any display that works over SPI can be used (provided that a driver is writted for it). In reality, **CUPC/8** neither has sufficient bandwidth over its SPI bus nor enough memory to drive large displays with many colours. The display chosen reflects these limitations.

The M1 machine's console is its graphics card, one of two (a machine has one or the other): the **HDMI card**, 80 x 30 text or 320 x 240 graphics in 256 colours on a monitor (`doc/hardware/gpu-protocol.md`), or the **e-ink card**, the same text and graphics on an e-paper panel on the card's cable, a 5.83" 648 x 480 panel (or a 7.5" 800 x 480), plus the panel's own resolution in 4 greys (`doc/hardware/eink-card.md`). On e-paper the text is black on white (each cell's brighter colour is the ink), the cursor does not blink, and the card refreshes the panel by itself: a line typed reaches the panel about half a second later, and continuous output updates it about once a second. The kernel asks the card which it is and drives either.

#### 2.4. Input
Keys come from a USB keyboard on the IO card (`doc/hardware/io-card.md`).

**The USB console.** With the system card fitted, its USB port is also a terminal for the machine: a PC sees two serial ports (Linux: `/dev/ttyACM0`, the programming port `cupc8.py` uses, and `/dev/ttyACM1`, the console). Open the console with `cupc8.py console`, or any terminal program (`picocom /dev/ttyACM1`, PuTTY; the baud rate does not matter), and everything the terminal prints appears there as well as on the screen, and what you type there is typed into the machine, as on its own keyboard. A BASIC program can be pasted in. Enter is CR (a pasted LF works too), Backspace or DEL takes a character back.

The kernel keeps two small rings in the API block for this (`doc/hardware/memory-map.md`), and the system card moves them to and from the PC every 2 ms, but only while a PC has the console open. Then the terminal waits for the PC when it prints faster than the PC reads; with the console closed, or no system card, nothing waits and the machine runs as without it. A program can see whether a PC is listening: bit 0 of `CON_FLAGS` ($6f26).

#### 2.5. Software Stack
The software stack consists of a monolithic kernel which provides drivers for the SPI peripherals and filesystem, handles interrupts, etc. It also provides a limited set of fixed-vector 'libc-like' functions and graphic routines that can be used by applications. There is no separation between kernel- and user-space (it's more of a convention) and any application has full access to the entire memory space at any time. Ideally applications would take care not to overwrite kernel regions but there is nothing stopping them from doing so.

In addition to drivers and system functions, the kernel provides a 'terminal' interface which accepts a number of commands. A limited subset of BASIC is provided which allows BASIC programs to be executed directly from the terminal (in a non-interactive fashion).

The BASIC is uBASIC with 16-bit signed numbers (-32768 to 32767; arithmetic wraps, so 32767+1 is -32768), line numbers 1-32767, one-letter variables `a`-`z`, and an 8 KB program buffer at $c000-$dfff (a line that does not fit is refused with `PROGRAM FULL`; a typed line is at most 78 characters).

Program lines are edited as on the home computers of old: the program is kept in line-number order, whatever order the lines are typed in, so `list`, `save` and `run` all see it sorted. A typed line goes in its place; a line with the number of one already there replaces it; a line number on its own (`20`, spaces after it are fine) deletes that line, and does nothing if there is none. A replacement only needs room for the difference, so on a full program a line can still be replaced by a shorter one, or by one as long as the space left allows. Typing a program in order is as quick at line 300 as at line 1; a line that goes before the last one typed is looked for from the start (about 0.2 s in a near-8 KB program).

Statements: `let`, `print` (`,` prints a space, `;` nothing; numbers print signed), `if ... then ... else`, `for ... to ... next`, `goto`, `gosub`/`return`, `rem`, `end`, `poke addr, value` and `peek addr, var` (a 16-bit address: `poke 61440, 5` sets the LEDs at $f000, since 61440 wraps to the same 16 bits; the old form `poke hi, lo, value` / `peek hi, lo, var`, the address hi*256+lo, still works, so `poke 240, 0, n` in a saved program does what it did), and the graphics statements below. Operators: `+ - * / % & |` and a leading `-`, `< > =` (signed), parentheses. `/` and `%` truncate toward zero (`-7/2` is -3, `-7%2` is -1); dividing by 0 gives 0 (and `%` by 0 the number itself). A number is at most 5 digits; 32768 to 99999 wrap. uBASIC's `for` runs its body once even when the limit is below the start.

Graphics, through the kernel API, so a program runs on either graphics card:

| Statement | Does |
|---|---|
| `mode n` | 0 TEXT, 1 GFX (320 x 240, 256 colours; on the e-ink card shown in grey), 2 the e-ink card's native mode (the panel's 648 x 480 or 800 x 480 in 4 greys). Mode 2 on HDMI, or any other n, is ignored, as the card ignores it. |
| `cls [c]` | clear: TEXT with attribute c ($07 if not given), GFX with colour c (0), mode 2 with grey c (3, white) |
| `color fg [, bg]` | the TEXT attribute for what is printed next: 16 colours each (bg 0 if not given) |
| `plot x, y, c` | a pixel: colour 0-255 in GFX, grey 0 black ... 3 white in mode 2 |
| `line x0, y0, x1, y1, c` | a line, both ends drawn |
| `box x, y, w, h, c [, f]` | a rectangle's outline, or filled with a last argument f that is not 0 (`box 10, 10, 50, 20, 4, 1`) |
| `palette i, r, g, b` / `palette` | set palette entry i (r, g, b 0-255) / the default palette back |
| `refresh [m]` | on the e-ink card, refresh the panel now: m 0 partial, 1 fast, 2 clean, 3 greyscale (3 in mode 2, 0 otherwise, if not given); nothing on HDMI |

Drawing is clipped to the screen. In GFX mode y (and a box's h) is 8-bit on the card, so values outside 0-255 are taken as 0 or 255. A wrong number of arguments is an error. A program that ends in mode 1 or 2 leaves its picture up until a key is pressed; then TEXT mode comes back (cleared) with `DONE.`.

Terminal commands besides BASIC lines: `help`, `new` (clear the program), `list` (print it), `run`, `clr` (clear the screen), `refresh` (on the e-ink card, a clean full refresh of the panel, which clears the faint ghosts partial refreshes leave; on HDMI it does nothing) and `net`, for the Wi-Fi card:

- `net join SSID PASSWORD` joins that network, keeps the credentials on the card (it joins them again at power-up) and prints the address it was given.
- `net get HOST [PORT]` sends `GET / HTTP/1.0` (with a `Host:` header) to HOST, port 80 unless given, and prints the reply until the server closes the connection. HOST is a name, looked up by the kernel's own DNS client, or a dotted address used as it is. A refused connection prints `connect failed`.
- `net lookup NAME` prints the address the DNS client finds for NAME. It asks the DNS server `net config` names (or the one DHCP gave), waits a second, asks once more, and takes the first A record of the answer. It says `name not found` (the server has no such name), `no address for that name` (the name exists, with no IPv4 address), `DNS server not answering`, `DNS server error`, `bad answer from the DNS server` or `no DNS server`.
- `net ping HOST [COUNT]` sends COUNT (4 unless given, up to 255) ICMP echo requests to HOST (a name or an address), one after the other, and prints each reply's round-trip time in milliseconds (`seq 1 time 3 ms`), or `seq 2 timeout` when none comes within a second, then `4 sent, 3 received, 2-5 ms` (the shortest and longest).
- `net config` shows the card's settings: `mode dhcp` or `mode static` with its address, mask and gateway; the DNS server (`from dhcp`, or an address) and its port; whether they are saved on the card. `net config dns IP [PORT]` sets the DNS server (port 53 unless given), `net config ip IP MASK GW` a static address, `net config dhcp` goes back to DHCP, and `net config save` keeps the settings on the card, applied at power-up (until then they last until the card is powered off).
- `net` on its own shows whether the link is up, and the address.

The times come from the chipset's millisecond counter (`doc/hardware/memory-map.md`), so they are exact to the millisecond: a DNS server has 1000 ms to answer each query, and an echo request 1000 ms.

`net` refuses to start the radio on a USB source under 3 A (see the power budget).

Files, on the storage card's microSD card (`doc/hardware/storage-card.md`). A card formatted on a PC works as it is (FAT12, FAT16 or FAT32). Names are 8.3 (`PROG.BAS`), in any case, with or without the quotes:

- `save "NAME"` writes the program as text, one line per program line, each ending in CR LF, so a PC can read and edit it. It replaces a file of that name.
- `load "NAME"` clears the program (`new`), then takes the file's lines as if they were typed (up to the 8 KB buffer), so a file with its lines out of order loads in order, and of a line number given twice the later line is kept: a line that does not start with a line number from 1 to 32767 (a blank line, say) is skipped, and a line longer than 78 characters is cut. A line that does not fit stops the load with `PROGRAM FULL`.
- `dir` lists every file with its size in bytes.
- `del "NAME"` deletes a file.
- `type "NAME"` prints a text file (a PC's CR LF line ends show as the terminal's own).
- `exec "NAME"` runs a file: a program for $7000 (it starts with the header `C8P` and version 1; `tools/mkprg.py` makes one, and it calls the kernel through `kernel/api.inc`), which comes back to the prompt when it returns or calls `API_EXIT`, or else a BASIC program, which it loads and runs. A program for $7000 longer than 20 KB (past $bfff) goes over the BASIC program at $c000-$dfff, as on the home computers of old: nothing warns about it. `cupc8.py run PROG` does the same from the PC through the system card.

They print `SAVED` or `LOADED` when done, or what went wrong: `no SD card`, `no storage card` (none fitted), `file not found`, `card full`, `write protected`, `bad file name` (not 8.3), `no file system on the card` (not formatted) or `card error`. On a USB source under 3 A, `save` and `del` print `USB power under 3A: SD writes off` and leave the card as it was; `load` and `dir` still work.

A program calls the kernel through its jump table at *$1003*: 8 groups of 32 entries, 3 bytes each, entry *n* of group *g* at *$1003* + 96*g* + 3*n* (*$1003*-*$1302*). The groups are system (with the RAM bank routines, and `API_MEM_CMP`/`API_MEM_CPY`: compare or copy up to 65535 bytes, overlapping copies done right), console, graphics (GFX mode, and the e-ink card's native mode 2: `API_GFX_MODE` 2 and the `API_GFX2_` entries, which give $ff on HDMI), e-ink, storage, net (16 routines: sockets, the DNS client, the card's settings), timers (milliseconds since power-on, and a wait) and one reserved; the unused entries answer *$ff*. `kernel/api.inc` names every entry (`API_PUTC`, `API_NET_OPEN`, ...); an entry's address never changes once it is there. Arguments go in **r0**/**r1** and the API block at *$6f00*, and **r0** comes back 0 or an error code (`doc/proposals/kernel-api.md`). The CPU's two timers are left to programs: the kernel's clock is the chipset's millisecond counter.

There is no compiler available for the CUPC/8 ISA. Development tools are cross-platform and consist of an assembler and a simulator which provides 1-to-1 simulation of the full computer (including display and input). The simulator can be executed natively or compiled to JavaScript (using emscripten) and run through a web browser.

## 3. Central Processing Unit

#### 3.1. Registers

The **CUPC/8** has two 8-bit General Purpose Reigsters (GPRs), **r0** and **r1**. These are available for use by arithmetic operations and *LOAD*/*STORE* operations.

A status register **f** exists which provides the internal logic with flags that are set due to operations. Bit 0 is the **Z** (*zero*) flag, set during comparison operations (*EQ*/*GT*/*LT*) and used by *BZF*. Bit 1 is the **I** (*interrupt enable*) flag. *CLI* clears **I**, *STI* sets it. **f** can be restored from the stack with *POP f* (the same *POP* opcode used for **r0**/**r1**/**pcl**/**pch**).

Two internal 16-bit address registers are provided for program flow; the **pc** (program counter) and **sp** (stack pointer) registers. The **pc** register holds the address of the next instruction awaiting execution. The **sp** register points to the address of the next free chunk of the stack memory region. Neither of these two registers can be acted upon directly and are modified through program flow and stack operations only.

There are two special 8-bit registers, **pcl** and **pch** (the 'low' and 'high' program counter registers). These registers can be acted upon through the use of stack operations (i.e. *PUSH*/*POP*) only. The **pch** register is special in that upon receiving a value though a stack *POP* operation, the 8-bit values of the **pcl** and **pch** registers are copied into the **pc** register such that _**pc** := **pch**||**pcl**_ and program flow jumps immediately to the new **pc** address. This is used to return from functions and from interrupts (there is no dedicated *RET* or *IRET* instruction).

#### 3.2. Memory layout

 Region | Start address | End Address 
 :--- | :---: | :---:
 Soft Reset Vector | $0000 | $0001
 *Reserved* | $0002 | $000f
 Interrupt Vector Table | $0010 | $00ff
 Stack | $0100 | $0fff
 Program | $1000 | $efff
 I/O | $f000 | $ffff

###### Soft Reset Vector (SRV) Region
On boot, the CPU will start executing from the Hard Reset Vector, *$f000* (i.e. _**pc** := $1000_) and **sp** will be reset to the bottom of the stack (_**sp** := $0100_). A configurable SRV can be set at *$0000*. Even if unused this vector should be set to *$1000* as soon as possible after boot.

###### Interrupt Vector Table (IVT) Region
Four 16-bit little-endian vectors sit at the bottom of the reserved IVT. The rest of *$0018*-*$00ff* is reserved.

IRQ | Vector | Source
:--- | :---: | :---
0 | *$0010* | Keyboard character ready
1 | *$0012* | Timer 0 expired
2 | *$0014* | Timer 1 expired
3 | *$0016* | SPI transaction complete

After an instruction finishes, if **I** is set and a pending unmasked source exists, the CPU takes the lowest numbered IRQ:

1. Push **pch**, then **pcl** (same order as a call).
2. Push **f** (bit 0 = **Z**, bit 1 = **I**).
3. Clear **I**.
4. Load **pc** from the vector.

Return is the same as a call return plus one extra pop for the flags:

	pop f
	pop pcl
	pop pch

An IRQ is never taken right after *POP pcl*: it and the *POP pch* after it are one return. (Taken between them, the IRQ's frame would go over the byte just popped, and its handler's own *POP pcl* would replace **pcl**, so the return would go astray.)

*POP f* restores **I**, so an IRQ still pending is taken right after it, inside the epilogue and before the return. This nests correctly: the new handler pushes the address of the *POP pcl* (three more stack bytes), and its own return lands back in the epilogue, which then completes. Interrupts can therefore nest one level per pending source; leave room on the stack for it.

Sources are latched. *$f200* is the pending register (write-1-to-clear). *$f201* is the mask (1 = enabled). Reset leaves **I** and the mask clear; the kernel plants the vectors and *STI*s when it is ready. Pending bit 4 is the chipset's tick (every 50 ms); it shares IRQ 3, and its vector, with SPI complete, so that handler reads *$f200* to tell them apart.

*WAI* stops fetching until an IRQ is accepted. If **I** is clear it is a *NOP*. *HALT* still means stop forever.

###### Stack Region
The stack is an 8-bit stack which can be accessed by *PUSH*/*POP* operations. The architecture does not support addressing off the stack pointer (there is no way to access something like _[**sp** + $10]_ for example) or block allocation of stack regions (there are no base/frame pointers). *Warning: Overflowing the stack is completely possible and the CPU will not care - so **don't do this!***

###### Program Region
This is where the code goes. The CPU will start executing from *$1000* and the **CUPC/8** kernel places a jump to the kernel initialization function vector at this address.

###### Input/Output Region
The MMU is responsible for mapping peripherals to the memory space. Currently this region is used for the General Purpose Output (GPO) pins (8-bit mapped to *$f000*), the SPI bus (mapped at *$f1XX*), and the interrupt controller (*$f200*, *$f201*) and the millisecond counter (*$f206*-*$f209*).

#### 3.3. Input/Output
###### General Purpose Output
GPOs are mapped to *$f000*, a simple 8-bit *STORE* operation to this address will set the pin states accordinly.

###### Serial Peripheral Interface Bus
The CPU can act as an SPI master for up to 4 SPI slaves. Each SPI controller is mapped to *$f1X0*-*$f1Xf*, where *X* denotes the device number (0-3).

The low nybble of the address denotes the SPI operation to be performed via interactions with the following registers:

Address | Operation | Descrption
:--- | :--- | :---
$f1X0 | STORE | Write byte to TX buffer
$f1X1 | LOAD | Read byte from RX buffer
$f1X2 | STORE | Perform transaction
$f1X3 | LOAD | Get SPI status
$f1Xf | STORE | Configure SPI

SPI master configuration is done via a *STORE* to the configuration register, *$f1Xf*. The register configuration bits are as follows:

```
00000 0 0 0
|   | | | |
 ---  | |  ----> continous
  |   |  ------> cpol
  |    --------> spha
   ------------> clk_div
```

The *continous*, *cpol* and *cpha* bits are self-explanatory to anyone familiar with SPI. 	*clk_div* allows the user to select the SPI bus speed as a factor of the system clock speed. The 5-bit value allows for a division of up to 31 such that a *clk_div* value of 1 will run the SPI bus at the same speed as the system clock.

After configuration of the SPI device, a typical transaction might look as follows:

	.transact:
		mov r0, #255
		st $f100, r0	; write 0xff to TX buffer
		mov r0, #1
		st $f102, r0	; perform transaction by writing 1 to $f10X2
	.loop:
		eq r0, #0
		bzf .transaction_done
		ld r0, $f103	; see if SPI is busy
		b .loop
	.transaction_done:
		ld r0, $f101	; read RX buffer

###### Interrupts
Address | Operation | Description
:--- | :--- | :---
*$f200* | LOAD | Pending bits (bit *n* = IRQ *n*; bit 4, the tick, is IRQ 3 too)
*$f200* | STORE | Write-1-to-clear pending bits
*$f201* | LOAD/STORE | Mask (1 = enabled), bits 4:0
*$f206* | LOAD | Milliseconds since reset, bits 7:0; latches bits 31:8 for *$f207*-*$f209*
*$f207*-*$f209* | LOAD | Bits 15:8, 23:16, 31:24 as latched by the last load of *$f206*

*TMR0* / *TMR1* load an 8-bit countdown (immediate or register). The value decrements after every retired instruction, the *TMR* instruction itself included (so *TMR0 #1* fires as it retires, and *TMR0 #3* as the second instruction after it retires). While parked in *WAI* it keeps decrementing, once every 3 CPU clocks. Crossing zero latches the matching timer IRQ. Writing 0 stops the timer without firing.

#### 3.4. Instruction Set Architecture
The **CUPC/8** instruction set contains of 38 8-bit instructions plus a handful of later additions (*HALT*, *CLI*, *STI*, *WAI*, *TMR0*, *TMR1*, and *POP f*).
Each instruction consists of an 5-bit/6-bit operation code (*opcode*) followed by register bits and zero, one or two bytes as defined by the instruction *format*.

###### Register Format
Instructions of the **register** format act on registers only and are 8-bit in length. The 5 most significant bits 7..3 denote the operation, bit 2 should always be cleared, bits 1 and 0 are registers Rb and Ra respectively (bit cleared = **r0**, bit set = **r1**).

The CPU performs only a single *fetch* operation for instructions of this formations are the fastest to execute.

	 -----------------------------
	[   ins   |  0  |  Rb  |  Ra  ]
	 -----------------------------
	   {7..3}   {2}    {1}   {0}

###### Immediate Format
Instructions of the **immediate** format are used when operations are performed on immediate 8-bit values. The most significant 5 bits denote the operation. Bit 10 must always be set. Bit 9 is ignored. Bit 8 denotes register Ra (bit cleared = **r0**, bit set = **r1**). The final 8 bit value is the immediate value.

The CPU performs two *fetch* operation for instructions of this format.

	 --------------------------------    -------
	[    ins    |   1   |  ?  |  Ra  ]  [  IMM  ]
	 --------------------------------    -------
	   {15..11}   {10}    {9}    {8}      {7..0}

###### Memory Format
Instructions of the **memory** format are used to store and load values via the MMU. The 5 most significant bits denote the operation. The next bit is ignored. Bits 17 and 16 are the Rb and Ra registers respectively. The final 16 bits denote the address of the memory operation.

The CPU performs three *fetch* operation for instructions of this format. These, together with the **flow** format instructions, are the slowest instructions to execute.

	 -------------------------------------    ----------
	[    ins    |   ?   |   Rb   |   Ra   ]  [   ADDR   ]
	 -------------------------------------    ----------
	   {23..19}   {18}     {17}     {16}       {15..0}

###### Flow Format
Instructions of the **flow** format are used to modify program execution flow (such as by modification of the program counter). The most significant 5 bits denote the operation. The next 3 bits are ignored. The final 16 bit value holds the target address for the program flow change operation.

The CPU performs three *fetch* operation for instructions of this format. These, together with the **memory** format instructions, are the slowest to execute.

	 -----------------------    ----------
	[    ins    |     ?     ]  [   ADDR   ]
	 -----------------------    ----------
	   {23..19}   {18..16}        {15..0}

###### Instructions
Mneumonic | Opcode | Format | Syntax | Operation
:--- | :--- | :--- | :--- | :---
NOP|80|R|NOP
MOVr|88|R|MOV Ra, Rb|Ra <= Rb
MOVi|8c|I|MOV Ra, #imm|Ra <= imm
PUSHr|90|R|PUSH Rb|[SP] <= Rb; SP <= SP + 1
PUSHi|94|I|PUSH #imm|[SP] <= imm; SP <= SP + 1
POP|98|R|POP Ra|Ra <= [SP]; SP <= SP - 1 *(; PC <= PCH\|\|PCL on Ra = PCH; f <= [SP] on Ra = f)*
LD|a0|M|LD Ra, $addr|Ra <= [addr]
LDind|a4|M|LD Ra, $addr+Rb|Ra <= [addr + Rb]
ST|a8|M|ST $addr, Rb|[addr] <= Rb
STind|ac|M|ST $addr+Ra, Rb|[addr + Ra] <= Rb
LDD|70|M|LDD Ra, $addr|Ra <= [[addr]]
LDDind|74|M|LDD Ra, $addr+Rb|Ra <= [[addr] + Rb] (the pointer at addr, plus Rb: 16-bit sum)
STD|78|M|STD $addr, Rb|[[addr]] <= Rb
STDind|7c|M|STD $addr + Ra, Rb|[[addr] + Ra] <= Rb (the pointer at addr, plus Ra: 16-bit sum)
B|b0|F|B $addr|PC <= addr
BZF|b8|F|BZF $addr|if ZF: PC <= addr
EQr|00|R|EQ Ra, Rb|ZF <= Ra == Rb
EQi|04|I|EQ Ra, #imm|ZF <= Ra == imm
GTr|08|R|GT Ra, Rb|ZF <= Ra > Rb
GTi|0c|I|GT Ra, #imm|ZF <= Ra > imm
LTr|10|R|LT Ra, Rb|ZF <= Ra < Rb
LTi|14|I|LT Ra, #imm|ZF <= Ra < imm
ANDr|18|R|AND Ra, Rb|Ra <= Ra & Rb
ANDi|1c|I|AND Ra, #imm|Ra <= Ra & imm
ORr|20|R|OR Ra, Rb|Ra <= Ra \| Rb
ORi|24|I|OR Ra, #imm|Ra <= Ra \| imm
XORr|30|R|XOR Ra, Rb|Ra <= Ra ^ Rb
XORi|34|I|XOR Ra, #imm|Ra <= Ra ^ imm
NORr|38|R|NOR Ra, Rb|Ra <= ~(Ra \| Rb)
NORi|3c|I|NOR Ra, #imm|Ra <= ~(Ra \| imm)
ADDr|40|R|ADD Ra, Rb|Ra <= Ra + Rb
ADDi|44|I|ADD Ra, #imm|Ra <= Ra + imm
SUBr|48|R|SUB Ra, Rb|Ra <= Ra - Rb
SUBi|4c|I|SUB Ra, #imm|Ra <= Ra - imm
SHLr|60|R|SHL Ra, Rb|Ra <= Ra << Rb
SHLi|64|I|SHL Ra, #imm|Ra <= Ra << imm
SHRr|68|R|SHR Ra, Rb|Ra <= Ra >> Rb
SHRi|6c|I|SHR Ra, #imm|Ra <= Ra >> imm
CLI|c0|R|CLI|I <= 0
STI|c8|R|STI|I <= 1
WAI|f0|R|WAI|wait until an IRQ is accepted (NOP if I = 0)
HALT|f8|R|HALT|stop
TMR0|e0|R/I|TMR0 Rb / TMR0 #imm|timer0 <= value
TMR1|e8|R/I|TMR1 Rb / TMR1 #imm|timer1 <= value

The immediate form of an instruction is always its register opcode plus 4 (bit 2 set).

###### Special register operands
*PUSH* and *POP* also take **pch**, **pcl** and **f**. These use the low three bits of the opcode byte, which would otherwise hold bit 2 and the register bits:

Instruction | Byte | Operation
:--- | :--- | :---
PUSH pch|96|[SP] <= high byte of (address of this instruction + 5); SP <= SP + 1
PUSH pcl|97|[SP] <= low byte of (address of this instruction + 4); SP <= SP + 1
POP pcl|9f|SP <= SP - 1; pcl <= [SP]
POP pch|9e|SP <= SP - 1; PC <= [SP]\|\|pcl (the jump that returns)
POP f|9c|SP <= SP - 1; f <= [SP] (bit 0 **Z**, bit 1 **I**)

A call is `PUSH pch` / `PUSH pcl` / `B target`: both pushes name the address just after the *B*. A return is `POP pcl` / `POP pch`. *PUSH f* does not exist: its byte, 94, is *PUSHi*.

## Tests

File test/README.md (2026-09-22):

# Tests

Every test in the project is listed in **`catalogue.toml`**: the CPU, ALU,
chipset blocks (MMU, SPI, IRQ, ROM windows, bridge, debug), the CPU bus, boot
ROM, kernel, each card's firmware, sysctl, host tools, the whole system, and
**each board** (main board, CPU card, GPU card, IO card, Wi-Fi card).

| Command | What it does |
|---|---|
| `make test` | run every implemented test |
| `make verify` | the fab gate: also fails while any non-hardware test is still pending |
| `make test-list` | list all tests and whether they're implemented |
| `test/run.py CPU MB-0` | run only tests whose id starts with a prefix |
| `test/run.py --kind hw MB-1` | hardware bring-up tests, run on the real boards |

Logs are written to `build/test/<id>.log`, and a summary to
`build/test/results.json`.

## Adding a test

1. Add or edit its entry in `catalogue.toml`, keeping the id prefix of its
   block or board.
2. Implement it, and give the entry a `cmd` that exits 0 on pass. The entry
   stays "pending" until it has a `cmd`.

## Kinds

| Kind | Meaning |
|---|---|
| sim | simulation or unit test |
| static | checks on design files (ERC, DRC, BOM, pins, fab package) |
| formal | SymbiYosys proofs |
| hw | bring-up on real boards after delivery (not part of the pre-fab gate) |

The contract these tests implement is `doc/hardware/verification.md`.

## Where the pieces live

- `test/*.s`: the original 2016 CPU test programs, used by CPU-001.
- `tools/testdata/*.s`: the simulator's test programs, used by SIM-001 and
  CPU-001.
- `soc/tb/`: VHDL testbenches.
- `test/board-test/`: the 2016 memory-board scripts (historical).

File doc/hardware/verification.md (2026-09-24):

# Verification contract (Milestone 1)

**Rule:** no hardware is ordered until **every row below is green in
`make verify`** and `doc/hardware/fab-readiness.md`, which is generated from
the results, is signed off by David.

There is no hardware prototype, so simulation and test must cover everything
that can be covered. The last section lists what physically cannot be
simulated, and how each item is mitigated.

Rules for the matrix:
- Every row names the **artifact under test**, **how** it is tested, and
  **what "green" means**.
- A row counts only if it runs in `make verify` and fails the build on
  regression.
- Hand checks count only where noted, and are recorded with a date in
  `fab-readiness.md`.

## 1. Logic (HDL)

| # | Artifact | Method | Green when |
|---|---|---|---|
| 1.1 | ALU, SPI master (incl. `SPI_CS`), IRQ controller, MMU decode, ROM windows/banking, bus bridge, stop/step/trace | GHDL unit testbenches | all pass; line and branch coverage ≥ 95% |
| 1.2 | CPU card (`cpu.vhd`) | Lockstep against `sim.nim`, instruction by instruction: every `test/` and `tools/testdata/` program plus ≥ 10⁶ fuzzed instructions | zero divergence; 100% opcode × format coverage |
| 1.3 | CPU bus, CPU side | Conformance testbench (`cpu-bus.md`): random wait states, stalls, mid-cycle reset, IRQ at every phase | zero protocol-monitor violations, lockstep still exact |
| 1.4 | Chipset and CPU bus | SymbiYosys proofs: one data-bus driver, /RDY rules, no RAM+ROM select together, no bridge+CPU grant together, one-hot SPI CS | all properties proven, not just bounded, where the solver allows. Bounded depth ≥ 40 otherwise. |
| 1.5 | Both FPGA designs, post-synthesis | Rows 1.2 and 1.3 re-run on the yosys netlist in Verilator | identical results to RTL |
| 1.6 | Both FPGA designs, post-place-and-route | nextpnr timing at 12 MHz | ≥ 30% slack on every path |
| 1.7 | External bus timing (SRAM, ROM, CPU socket) | `hw/timing/*_budget.py` using FPGA I/O timing, datasheet parameters and extracted trace lengths | every parameter ≥ 20% margin |

## 2. Firmware and software

| # | Artifact | Method | Green when |
|---|---|---|---|
| 2.1 | `sim.nim`, the reference model | `tools/run_tests.sh`. Every divergence found in 1.2 is resolved by the manual, not by the model. | all pass |
| 2.2 | Boot ROM `rom/boot.s` | Run in the simulator and the co-sim on every path: normal boot, each POST failure (RAM fault injection, bad magic, bad version, oversize, bad checksum), 0–6 cards, SST39VF040 vs VF010 chip ID | each path gives its specified LED code and console text |
| 2.3 | Kernel (new `gpu.s`, `keyb.s` framing, slot IRQ, network driver + commands) | Simulator scenario tests: boot to BASIC, typed programs, the Wi-Fi fetch test | scripted transcripts and golden frames match |
| 2.4 | GPU card firmware | Core: host unit tests on every opcode, malformed frames and flow control, plus golden images for TEXT and GFX. **Real binary** in rp2040js: PIO SPI slave driven with CUPC/8 timing, and the TMDS output captured and decoded back to pixels. | tests pass; decoded frame == golden |
| 2.5 | IO card firmware | Core: host tests on the keymap, repeat and overflow, fed by **HID reports recorded from ≥ 5 real keyboards** (committed as test data). Real binary in rp2040js for the SPI side. | pass |
| 2.6 | Wi-Fi card firmware | Core: host tests with lwIP's Unix port on TAP: DHCP, DNS, TCP, UDP, and TLS against a local server with a test CA. **Real binary** in Espressif's QEMU (esp32c3), with Wi-Fi replaced by QEMU's OpenCores Ethernet, running the same network tests. | pass |
| 2.7 | sysctl firmware | Core: host tests of the USB command protocol, FPGA configuration (flash and CRAM), SST39 JEDEC program and erase via the bridge model, the SWD engine against an SWD target model, the ESP UART flasher against the esptool reference protocol, I²C expander and mux sequencing, and USB-C CC → current policy | pass |
| 2.8 | Host tools (`cupc8.py`, `mkrom.py`, `jlcparts.py`) | pytest, including `cupc8.py` end-to-end against the co-sim's modelled USB | pass |
| 2.9 | Storage card firmware (`storage-card.md`) | Core: host tests of every command and malformed frame on FatFs over disk images (handles, chunking, end of file, full medium, write-protect, card removal, 8.3 names, block commands), and the images cross-checked with a PC's FAT reader (pyfatfs, `fsck.fat`) both ways (STO-001/002). **Real binary** on the native emulator with an SD SPI-mode model (STO-003). | pass |

## 3. Whole system

| # | Artifact | Method | Green when |
|---|---|---|---|
| 3.1 | **The schematics themselves** | The co-sim's top level is **generated from the KiCad netlists** of all five boards. Every connection between FPGA netlists, SRAM/ROM timing models, connectors and card models comes from the schematic. Pull-ups become weak pulls, and series resistors become delays. A swapped or missing wire fails the simulation. | the end-to-end tests below pass on the netlist-generated top level |
| 3.2 | End-to-end | Blank ROM → program over modelled USB → boot → BASIC → type a program → run it → Wi-Fi join → TCP fetch from a local test server → golden HDMI frame | all pass |
| 3.3 | Negative end-to-end | Empty slots, a card removed between power cycles, corrupt kernel (bad header, bad body checksum), interrupted ROM programming, low-power USB source. Out of scope: a missing CPU card (broken hardware) and cards plugged or pulled while powered (cards change only with the power off, `slot.md`) | each behaves as specified |
| 3.4 | Pin consistency | `pins.yaml` ↔ `.pcf` ↔ firmware `pins.h` ↔ KiCad netlists, and iCE40 pin roles ↔ the Lattice pinout CSV | zero differences |

## 4. Electrical and board

| # | Artifact | Method | Green when |
|---|---|---|---|
| 4.1 | Schematics | KiCad ERC | 0 errors, and every waiver justified in writing |
| 4.2 | Layouts | KiCad DRC with JLC's rule set | 0 errors, 0 unconnected |
| 4.3 | Footprints and symbols | Every footprint matches, pad for pad, the EasyEDA footprint JLC places for its LCSC part (KiCad's own footprints are allowed when they do; an imported one when they don't). `hw/tools/bomcheck.py` (BRD-001) checks the package, the symbol pinout against the datasheet table in `hw/parts/<LCSC>.yaml`, and each line's CPL rotation against JLC's footprint. | all lines pass |
| 4.4 | Power | ngspice for each regulator (startup, load step, dropout, PSRR), USB-C inrush, and the 6-slot worst-case budget. A script checks the USB-C CC divider and ADC thresholds against the Type-C spec. | within spec with margin |
| 4.5 | Thermal | Per-regulator dissipation vs θJA at 40 °C ambient | Tj ≤ 100 °C |
| 4.6 | Signal integrity | openEMS: HDMI TMDS route, connector breakout and vias (loss and return loss up to 1.26 GHz), and the USB D+/D− routes. ngspice with IBIS models: the 6-slot shared SPI bus (SCK fan-out, MISO sharing), the CPU bus across the x8 socket, and the SRAM/ROM bus. | TMDS/USB impedance within ±10% and loss within budget; no ringing past VIH/VIL thresholds |
| 4.7 | Mechanical | STEP of all boards plus connector models, FreeCAD script: each card in each slot, card-to-card clearance, CPU card clearance, Wi-Fi antenna cable route, connector overhang, finger depth and bevel against PCIe CEM | no collisions; all dimensions in tolerance |
| 4.8 | BOM and stock | `jlcparts.py check` on every BOM line, and BOM ↔ schematic consistency | all in stock at ≥ 2× build quantity; no mismatches |
| 4.9 | Fab package | Gerbers re-imported and re-checked with DRC. The CPL is rendered over the board for a rotation and polarity review (hand check, recorded). The drill file is checked against the footprint holes. | pass, plus the recorded hand check |

## 5. Cannot be simulated: mitigations

| Risk | Why not simulable | Mitigation |
|---|---|---|
| TMDS analog eye at 252 Mb/s per lane | Needs the monitor's receiver behaviour | Pico DVI Sock pin mapping and resistors copied exactly; openEMS on our route; 4-layer board with controlled impedance |
| RP2040 at 252 MHz (per part) | Silicon margin varies | PicoDVI's standard 252 MHz with its core voltage bump (VREG 1.20 V), used widely on RP2040. Bring-up checks each unit for an hour with a soak test pattern. The spare boards cover a marginal part. |
| USB-host enumeration with real keyboards | rp2040js has no USB host | TinyUSB host HID is widely used; the HID parsing is tested on recorded reports from real keyboards; boot protocol forced |
| ESP32-C3 SPI slave on silicon | QEMU doesn't model the GPSPI slave | Espressif's documented `spi_slave` driver; the core is tested through an SPI shim that follows the datasheet timing; the framing rules (READ frames, 20 µs re-arm gap) were chosen for this driver |
| Wi-Fi RF | Radio isn't simulable | **Pre-certified module with an external antenna** (ESP32-C3-MINI-1U + MHF III lead to an SMA antenna), so our layout doesn't affect the radio |
| Assembly defects | Manufacturing | JLC AOI and X-ray on request for the TQFP; the debug features in `debugging.md` (LEDs, POST codes, test pads, isolation links, current sense, and the RP2040's stop/step/trace with `trace --diff` against the simulator); bring-up in stages; the spare main board |

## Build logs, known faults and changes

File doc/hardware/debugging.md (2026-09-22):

# Debugging the hardware

There is no prototype before the boards are made, so the boards themselves
have to be debuggable. This lists what goes on them, what each feature is
for, and what to reach for when something does not work.

Every feature here is a requirement on the schematics, and is checked by the
board tests in `test/catalogue.toml`.

## 1. LEDs: what the machine tells you without any tools

| LED | Where | Meaning |
|---|---|---|
| 5V, 3V3, 1V2 | main board, one per rail | the rail is up. The first thing to look at. |
| 1V2 (card) | CPU card | the card's own core rail |
| CDONE ×2 | main board (chipset), CPU card | the FPGA is configured. Off = configuration failed. |
| GPO D1–D8 | main board | the CPU's `$f000` port: the boot ROM's POST code, then whatever the kernel writes |
| ACT | graphics card | video output is running |
| KBD | IO card | a keyboard is enumerated |
| LINK | Wi-Fi card | associated to a network |
| PWR | each card | the card has 3V3 |

**POST codes** on the GPO LEDs, from the boot ROM (`doc/hardware/memory-map.md`):

| Code | Stage | If it stops here |
|---|---|---|
| $01 | boot ROM entered | the CPU runs and reads the ROM |
| $02 | RAM test | RAM, its address/data lines, or the chip select |
| $04 | slot probe | an SPI transfer to a card hangs |
| $08 | console banner | the graphics card answered IDENT but not the text commands |
| $10 | kernel header | the ROM contents are wrong: reprogram it |
| $20 | copying the kernel | ROM banking or RAM writes |
| $40 | checksum | the copy is corrupt: suspect the bus or marginal timing |
| $80 | jumping to the kernel | after this the kernel owns the LEDs |
| $82 | RAM test failed | stuck or shorted RAM lines |
| $90 | no valid kernel in ROM | reprogram the ROM |
| $91 | kernel too large | rebuild it |
| $A0 | kernel checksum bad | reprogram the ROM; if it repeats, suspect the bus |

A failure that reaches the console also prints a message.

## 2. The RP2040 as a debug probe

The system controller is on the CPU bus's doorstep and is reachable over the
single USB-C port, so most debugging needs no other equipment.

| `cupc8.py` command | What it does | Use it when |
|---|---|---|
| `status` | rails, CDONE, card presence, CPU state (halted/waiting/stopped), card IDs | first contact with a new board |
| `ram poke/peek/dump` | read and write SRAM with the CPU stopped | the CPU never runs |
| `selftest ram` | a March C- pattern over all of RAM | POST $02 fails |
| `rom read/write/verify` | program the ROM chip in place | ROM contents, or POST $10/$90 |
| `fpga flash` / `fpga load` | program or directly load a bitstream | CDONE stays off |
| `stop` / `step` / `step-cycle` | halt the CPU, then advance one instruction or one bus cycle | the CPU runs but does the wrong thing |
| `trace` | the last 512 completed bus cycles: address, data, read/write, opcode-fetch | anything that goes wrong "somewhere" |
| `trace --diff` | run the same program in `sim.nim` and compare traces instruction by instruction | the machine diverges from the simulator |
| `card flash/ident` | reprogram or identify a card | a card is silent |
| `power` | what the USB-C source advertises, and per-slot current | brown-outs, a card that trips the supply |

`trace --diff` is the strongest tool: the simulator is the reference model, so
a mismatch points at the exact cycle where the real machine differs.

## 3. Test points and links

- **Test pads** on every rail, every CPU-bus and memory-bus signal, both SPI
  buses, the clock and the resets, so a scope or logic analyser can attach
  without soldering to a pin.
- **0 Ω links** in each rail and each slot's 5 V feed: bring the board up one
  section at a time, and isolate a card that pulls a rail down.
- **Current-sense resistors** (50 mΩ) in each slot's 5 V feed with pads either
  side, so a meter reads the card's current.
- **UART headers** from the sysctl RP2040 and from each card MCU.
- **SWD pads and a BOOTSEL button** on every card: the normal path is through
  the slot, and these are the fallback if that path is the thing that's broken.
- **A spare main board** in the build, so a board-level fault doesn't stop
  everything.

## 4. Bring-up order

Each step is a test in the catalogue (`test/run.py --kind hw`), and each one
only depends on the steps before it.

1. **MB-101** rails, with nothing else fitted.
2. **MB-102** sysctl enumerates over USB.
3. **MB-103** chipset bitstream, CDONE on.
4. **MB-104** RAM march test through the bridge, CPU still in reset.
5. **MB-105** program and verify the ROM.
6. **CC-101** fit the CPU card, load it, single-step the boot ROM and diff the
   trace against the simulator.
7. **MB-106** slot signals and card presence.
8. **GC-101 / IC-101 / WC-101** one card at a time: flash it, IDENT it, then
   its own function (test pattern, typing, network).

## 5. Symptom → first checks

| Symptom | Look at |
|---|---|
| No LEDs | USB-C source, input fuse, 5 V rail, the rail links |
| sysctl does not enumerate | 3V3, the 12 MHz crystal, USB D+/D− (test pads), BOOTSEL |
| CDONE stays off | config flash contents (`fpga flash`), CRESET, the 1V2 rail |
| POST stops at $02 | `selftest ram`, then the address and data lines on the pads |
| POST stops at $04 | SPI pads: does SCK/MOSI move? Is one card holding MISO low? |
| Nothing on screen | graphics card ACT LED, `card ident`, HDMI cable, then the TMDS pads |
| No keyboard | IO card KBD LED, slot current, VBUS fault flag in `status` |
| Random crashes | `power` for brown-outs, then `trace` after the fault |
| Works stopped, fails running | timing: check the clock, then re-run the timing budget against the built board |

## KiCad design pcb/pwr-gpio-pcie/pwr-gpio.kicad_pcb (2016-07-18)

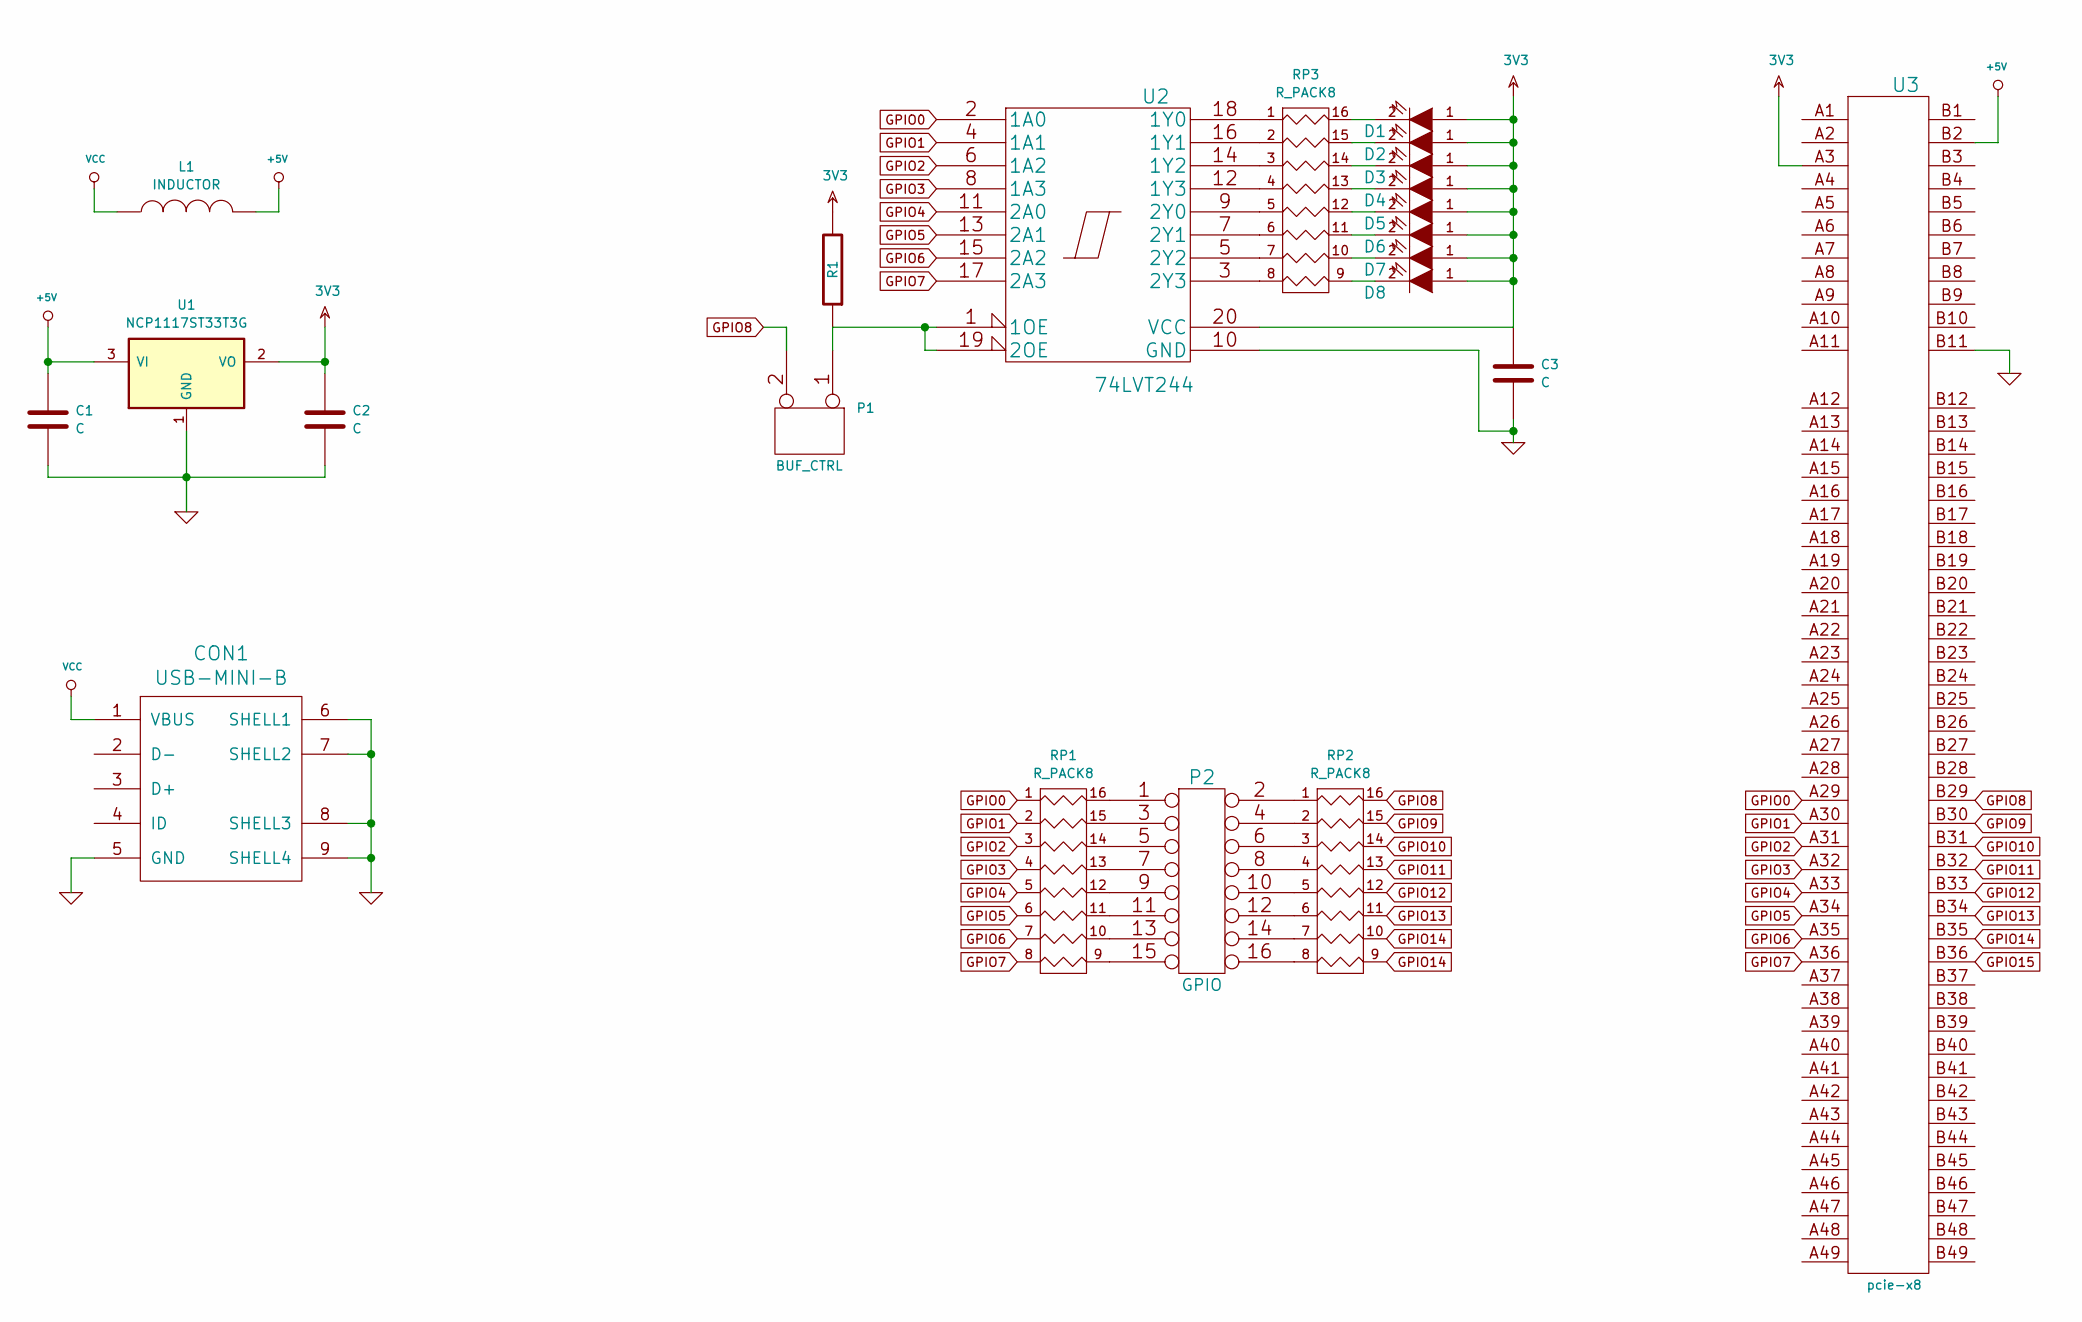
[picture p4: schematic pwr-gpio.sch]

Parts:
C1, C2, C3: C; C_0805_HandSoldering
CON1: USB-MINI-B; USB_Micro-B
D1, D2, D3, D4, D5, D6, D7, D8: LED; LED-0805
L1: INDUCTOR; C_0805_HandSoldering
P1: BUF_CTRL; Socket_Strip_Straight_1x02
P2: GPIO; Socket_Strip_Straight_2x08
R1: R; R_0805_HandSoldering
RP1, RP2, RP3: R_PACK8; R_Cat16-8
U1: NCP1117ST33T3G; SOT-223
U2: 74LVT244; SSOP-20
U3: pcie-x8

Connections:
3V3: C2.1, C3.1, D1.1 (A), D2.1 (A), D3.1 (A), D4.1 (A), D5.1 (A), D6.1 (A), D7.1 (A), D8.1 (A), R1.2, U1.2 (VO), U2.20 (VCC), U3.A3
+5V: C1.1, L1.2, U1.3 (VI), U3.B2
GND: C1.2, C2.2, C3.2, CON1.5 (GND), CON1.6 (SHELL1), CON1.7 (SHELL2), CON1.8 (SHELL3), CON1.9 (SHELL4), U1.1 (GND), U2.10 (GND), U3.B11
GPIO0: RP1.1, U2.2 (1A0), U3.A29
GPIO1: RP1.2, U2.4 (1A1), U3.A30
GPIO2: RP1.3, U2.6 (1A2), U3.A31
GPIO3: RP1.4, U2.8 (1A3), U3.A32
GPIO4: RP1.5, U2.11 (2A0), U3.A33
GPIO5: RP1.6, U2.13 (2A1), U3.A34
GPIO6: RP1.7, U2.15 (2A2), U3.A35
GPIO7: RP1.8, U2.17 (2A3), U3.A36
GPIO8: P1.2 (PM), RP2.16 (R1), U3.B29
GPIO9: RP2.15 (R2), U3.B30
GPIO10: RP2.14 (R3), U3.B31
GPIO11: RP2.13 (R4), U3.B32
GPIO12: RP2.12 (R5), U3.B33
GPIO13: RP2.11 (R6), U3.B34
GPIO14: RP2.9 (R8), RP2.10 (R7), U3.B35
GPIO15: U3.B36
unnamed: D1.2 (K), RP3.16 (R1)
unnamed: D2.2 (K), RP3.15 (R2)
unnamed: D3.2 (K), RP3.14 (R3)
unnamed: D4.2 (K), RP3.13 (R4)
unnamed: D5.2 (K), RP3.12 (R5)
unnamed: D6.2 (K), RP3.11 (R6)
unnamed: D7.2 (K), RP3.10 (R7)
unnamed: D8.2 (K), RP3.9 (R8)
unnamed: P1.1, R1.1, U2.1 (1OE), U2.19 (2OE)
unnamed: P2.1, RP1.16 (R1)
unnamed: P2.2, RP2.1
unnamed: P2.3, RP1.15 (R2)
unnamed: P2.4, RP2.2
unnamed: P2.5, RP1.14 (R3)
unnamed: P2.6, RP2.3
unnamed: P2.7, RP1.13 (R4)
unnamed: P2.8, RP2.4
unnamed: P2.9, RP1.12 (R5)
unnamed: P2.10, RP2.5
unnamed: P2.11, RP1.11 (R6)
unnamed: P2.12, RP2.6
unnamed: P2.13, RP1.10 (R7)
unnamed: P2.14, RP2.7
unnamed: P2.15, RP1.9 (R8)
unnamed: P2.16, RP2.8
unnamed: RP3.1, U2.18 (1Y0)
unnamed: RP3.2, U2.16 (1Y1)
unnamed: RP3.3, U2.14 (1Y2)
unnamed: RP3.4, U2.12 (1Y3)
unnamed: RP3.5, U2.9 (2Y0)
unnamed: RP3.6, U2.7 (2Y1)
unnamed: RP3.7, U2.5 (2Y2)
unnamed: RP3.8, U2.3 (2Y3)
VCC: CON1.1 (VBUS), L1.1

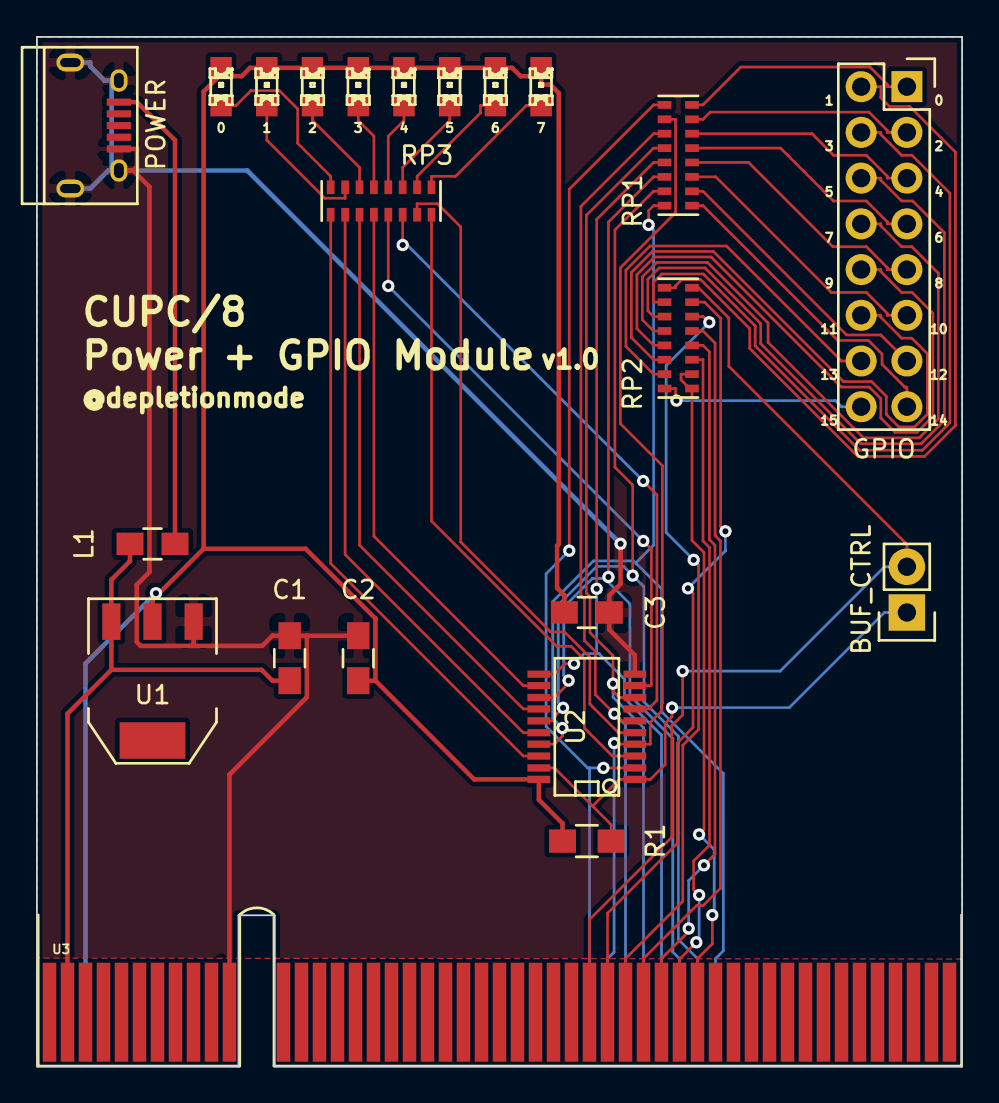
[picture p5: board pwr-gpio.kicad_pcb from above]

Board: 2 copper layers, 51.4 x 57.2 mm, 22 parts (0 on the bottom side), 52 nets.

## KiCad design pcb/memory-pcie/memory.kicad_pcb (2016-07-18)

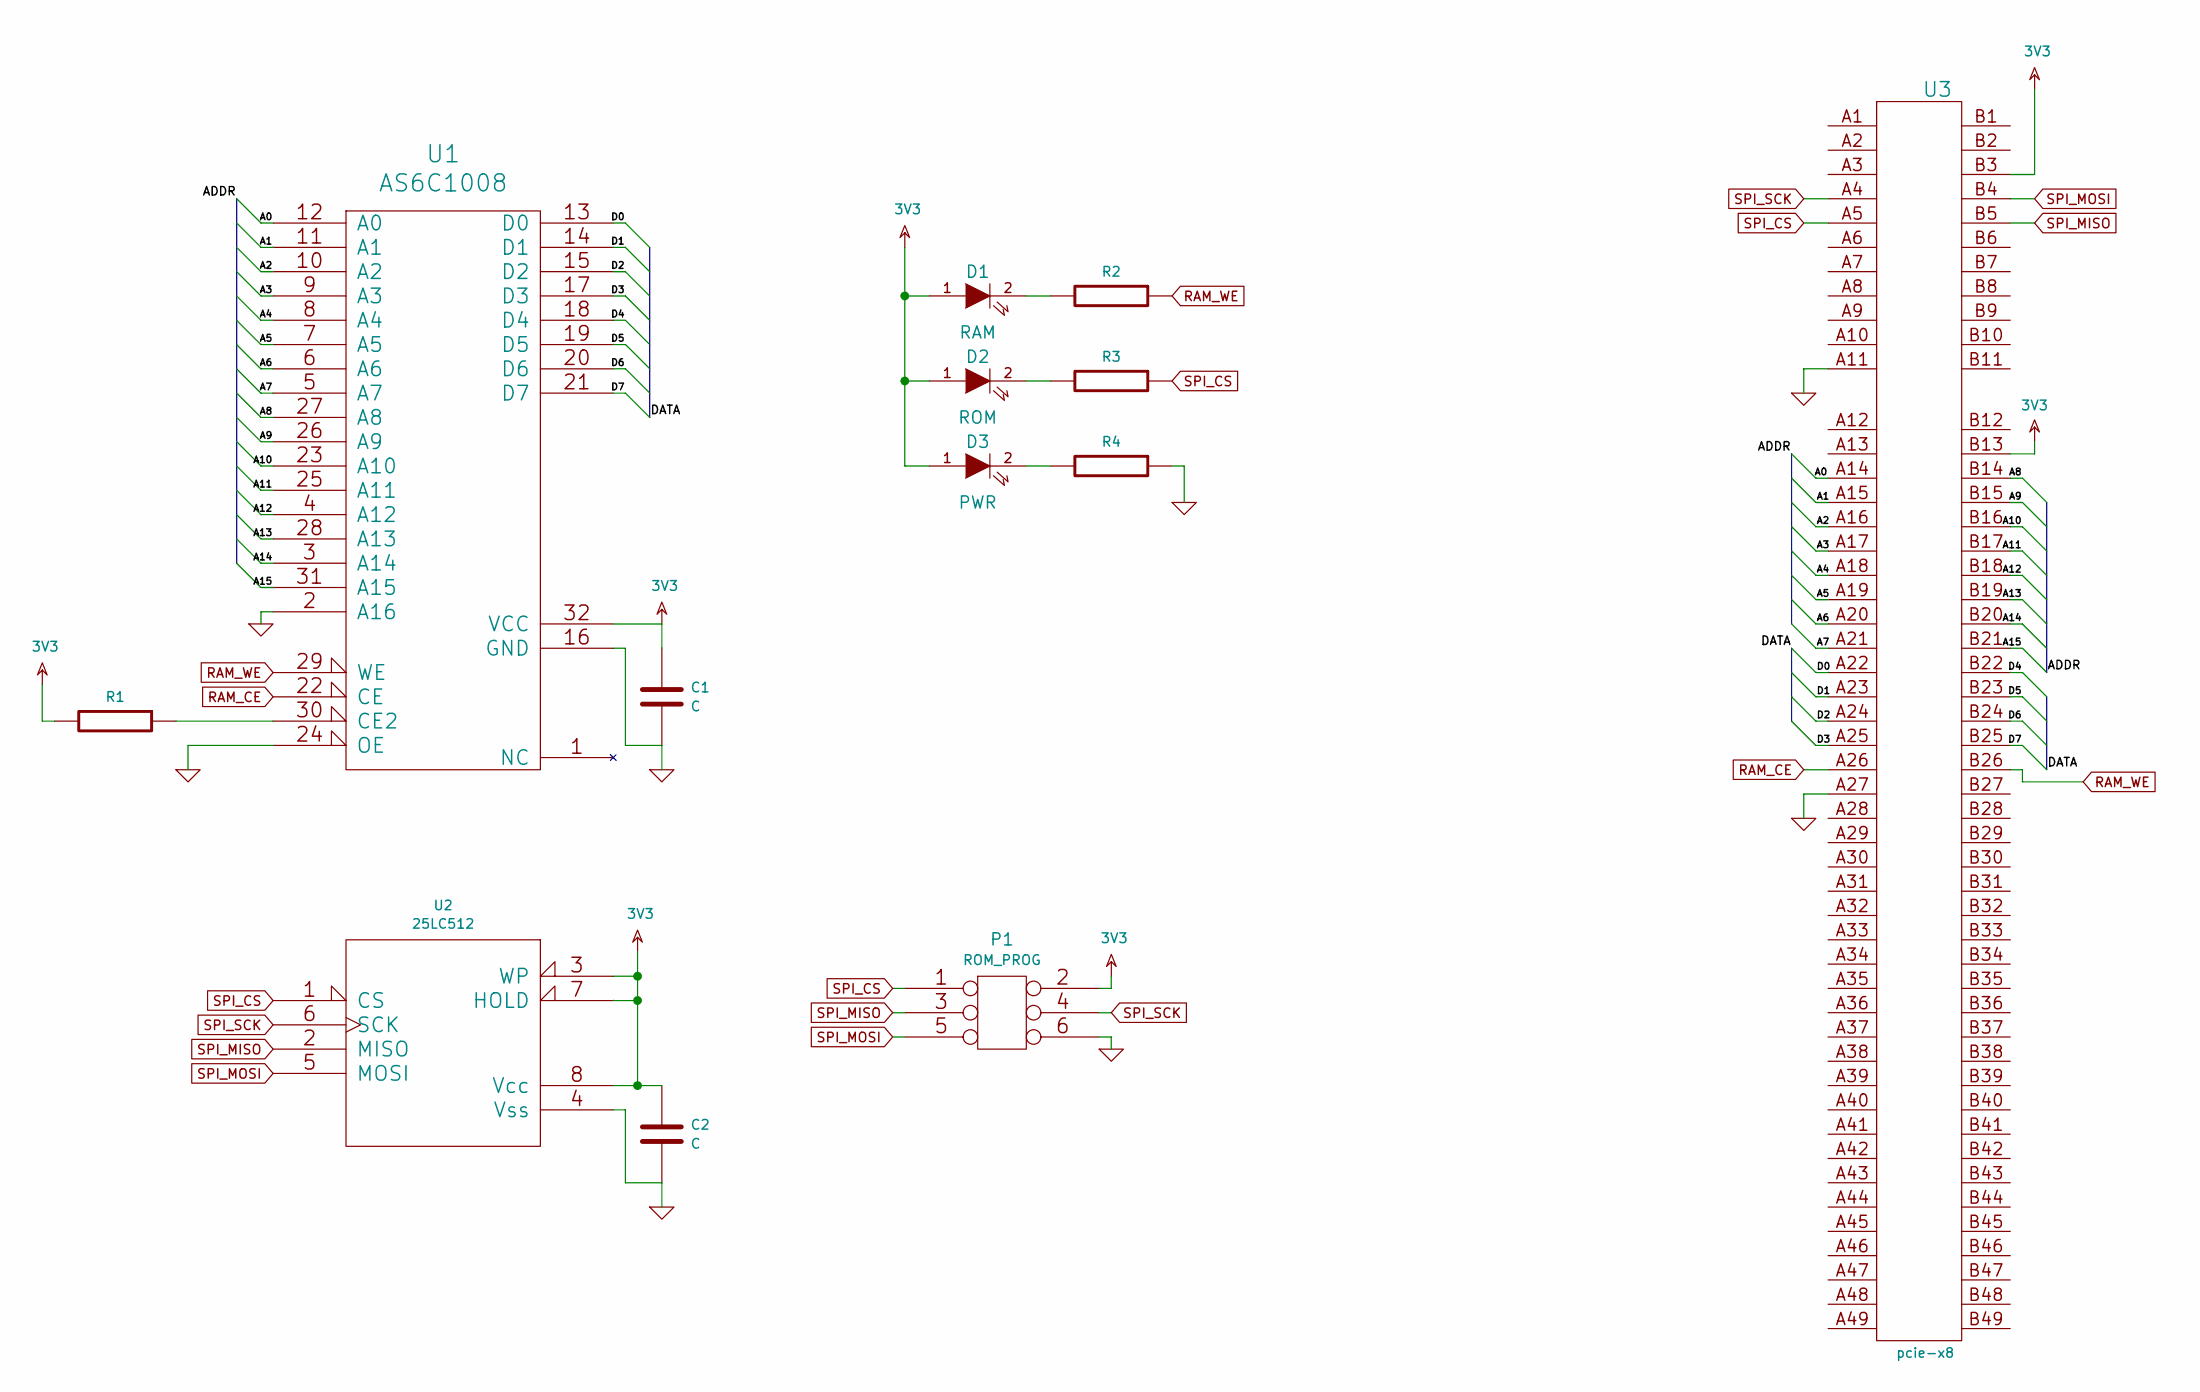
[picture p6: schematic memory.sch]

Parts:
C1, C2: C; C_0805_HandSoldering
D1: RAM; LED-0805
D2: ROM; LED-0805
D3: PWR; LED-0805
P1: ROM_PROG; Pin_Header_Straight_2x03
R1, R2, R3, R4: R; R_0805_HandSoldering
U1: AS6C1008; DIP-32__600
U2: 25LC512; DIP-8__300
U3: pcie-x8

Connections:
3V3: C1.1, C2.1, D1.1 (A), D2.1 (A), D3.1 (A), P1.2, R1.2, U1.32 (VCC), U2.3 (WP), U2.7 (HOLD), U2.8 (Vcc), U3.B3, U3.B13
/A0: U1.12 (A0), U3.A14
/A1: U1.11 (A1), U3.A15
/A2: U1.10 (A2), U3.A16
/A3: U1.9 (A3), U3.A17
/A4: U1.8 (A4), U3.A18
/A5: U1.7 (A5), U3.A19
/A6: U1.6 (A6), U3.A20
/A7: U1.5 (A7), U3.A21
/A8: U1.27 (A8), U3.B14
/A9: U1.26 (A9), U3.B15
/A10: U1.23 (A10), U3.B16
/A11: U1.25 (A11), U3.B17
/A12: U1.4 (A12), U3.B18
/A13: U1.28 (A13), U3.B19
/A14: U1.3 (A14), U3.B20
/A15: U1.31 (A15), U3.B21
/D0: U1.13 (D0), U3.A22
/D1: U1.14 (D1), U3.A23
/D2: U1.15 (D2), U3.A24
/D3: U1.17 (D3), U3.A25
/D4: U1.18 (D4), U3.B22
/D5: U1.19 (D5), U3.B23
/D6: U1.20 (D6), U3.B24
/D7: U1.21 (D7), U3.B25
GND: C1.2, C2.2, P1.6, R4.1, U1.2 (A16), U1.16 (GND), U1.24 (OE), U2.4 (Vss), U3.A11, U3.A27
unnamed: D1.2 (K), R2.2
unnamed: D2.2 (K), R3.2
unnamed: D3.2 (K), R4.2
unnamed: R1.1, U1.30 (CE2)
RAM_CE: U1.22 (CE), U3.A26
RAM_WE: R2.1, U1.29 (WE), U3.B26
SPI_CS: P1.1, R3.1, U2.1 (CS), U3.A5
SPI_MISO: P1.3, U2.2 (MISO), U3.B5
SPI_MOSI: P1.5, U2.5 (MOSI), U3.B4
SPI_SCK: P1.4, U2.6 (SCK), U3.A4

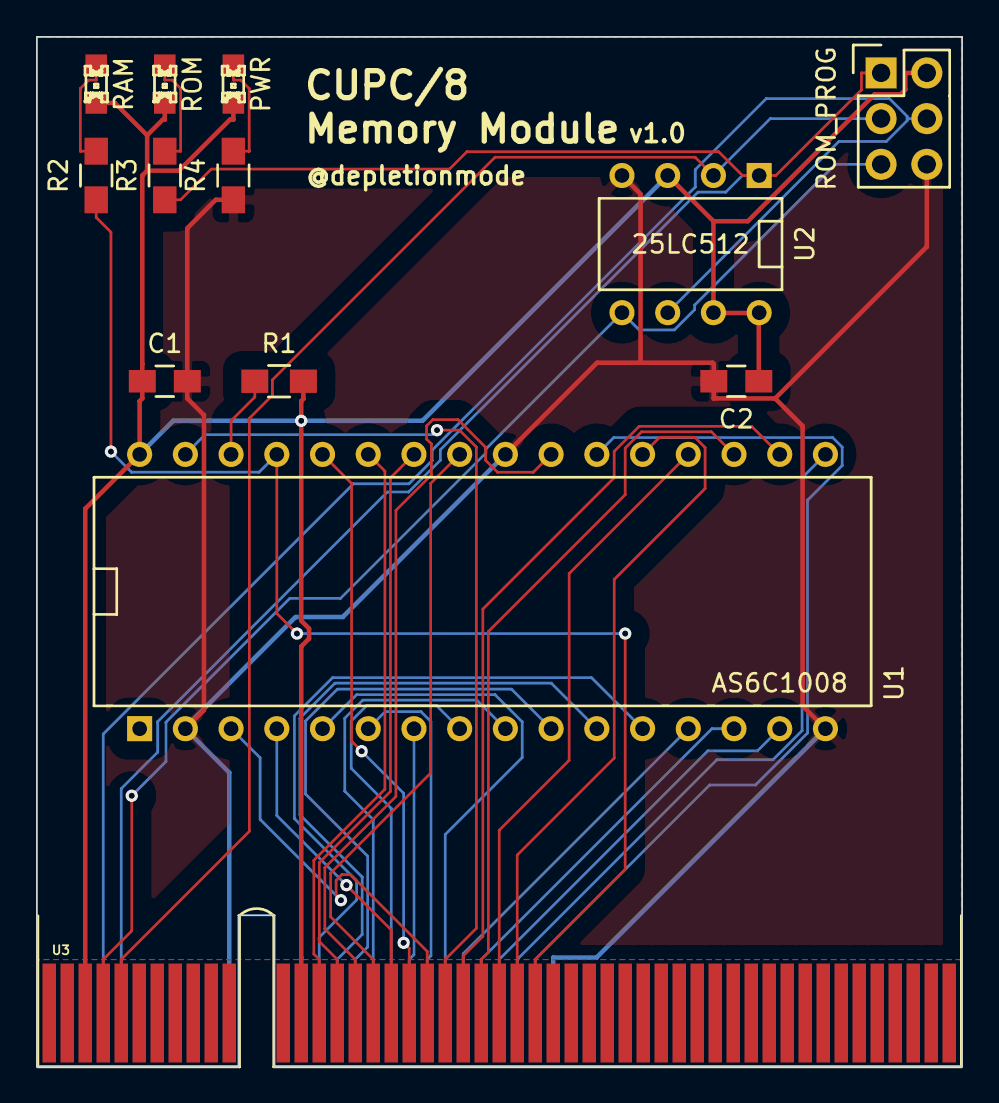
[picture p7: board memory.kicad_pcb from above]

Board: 2 copper layers, 51.4 x 57.2 mm, 13 parts (0 on the bottom side), 36 nets.

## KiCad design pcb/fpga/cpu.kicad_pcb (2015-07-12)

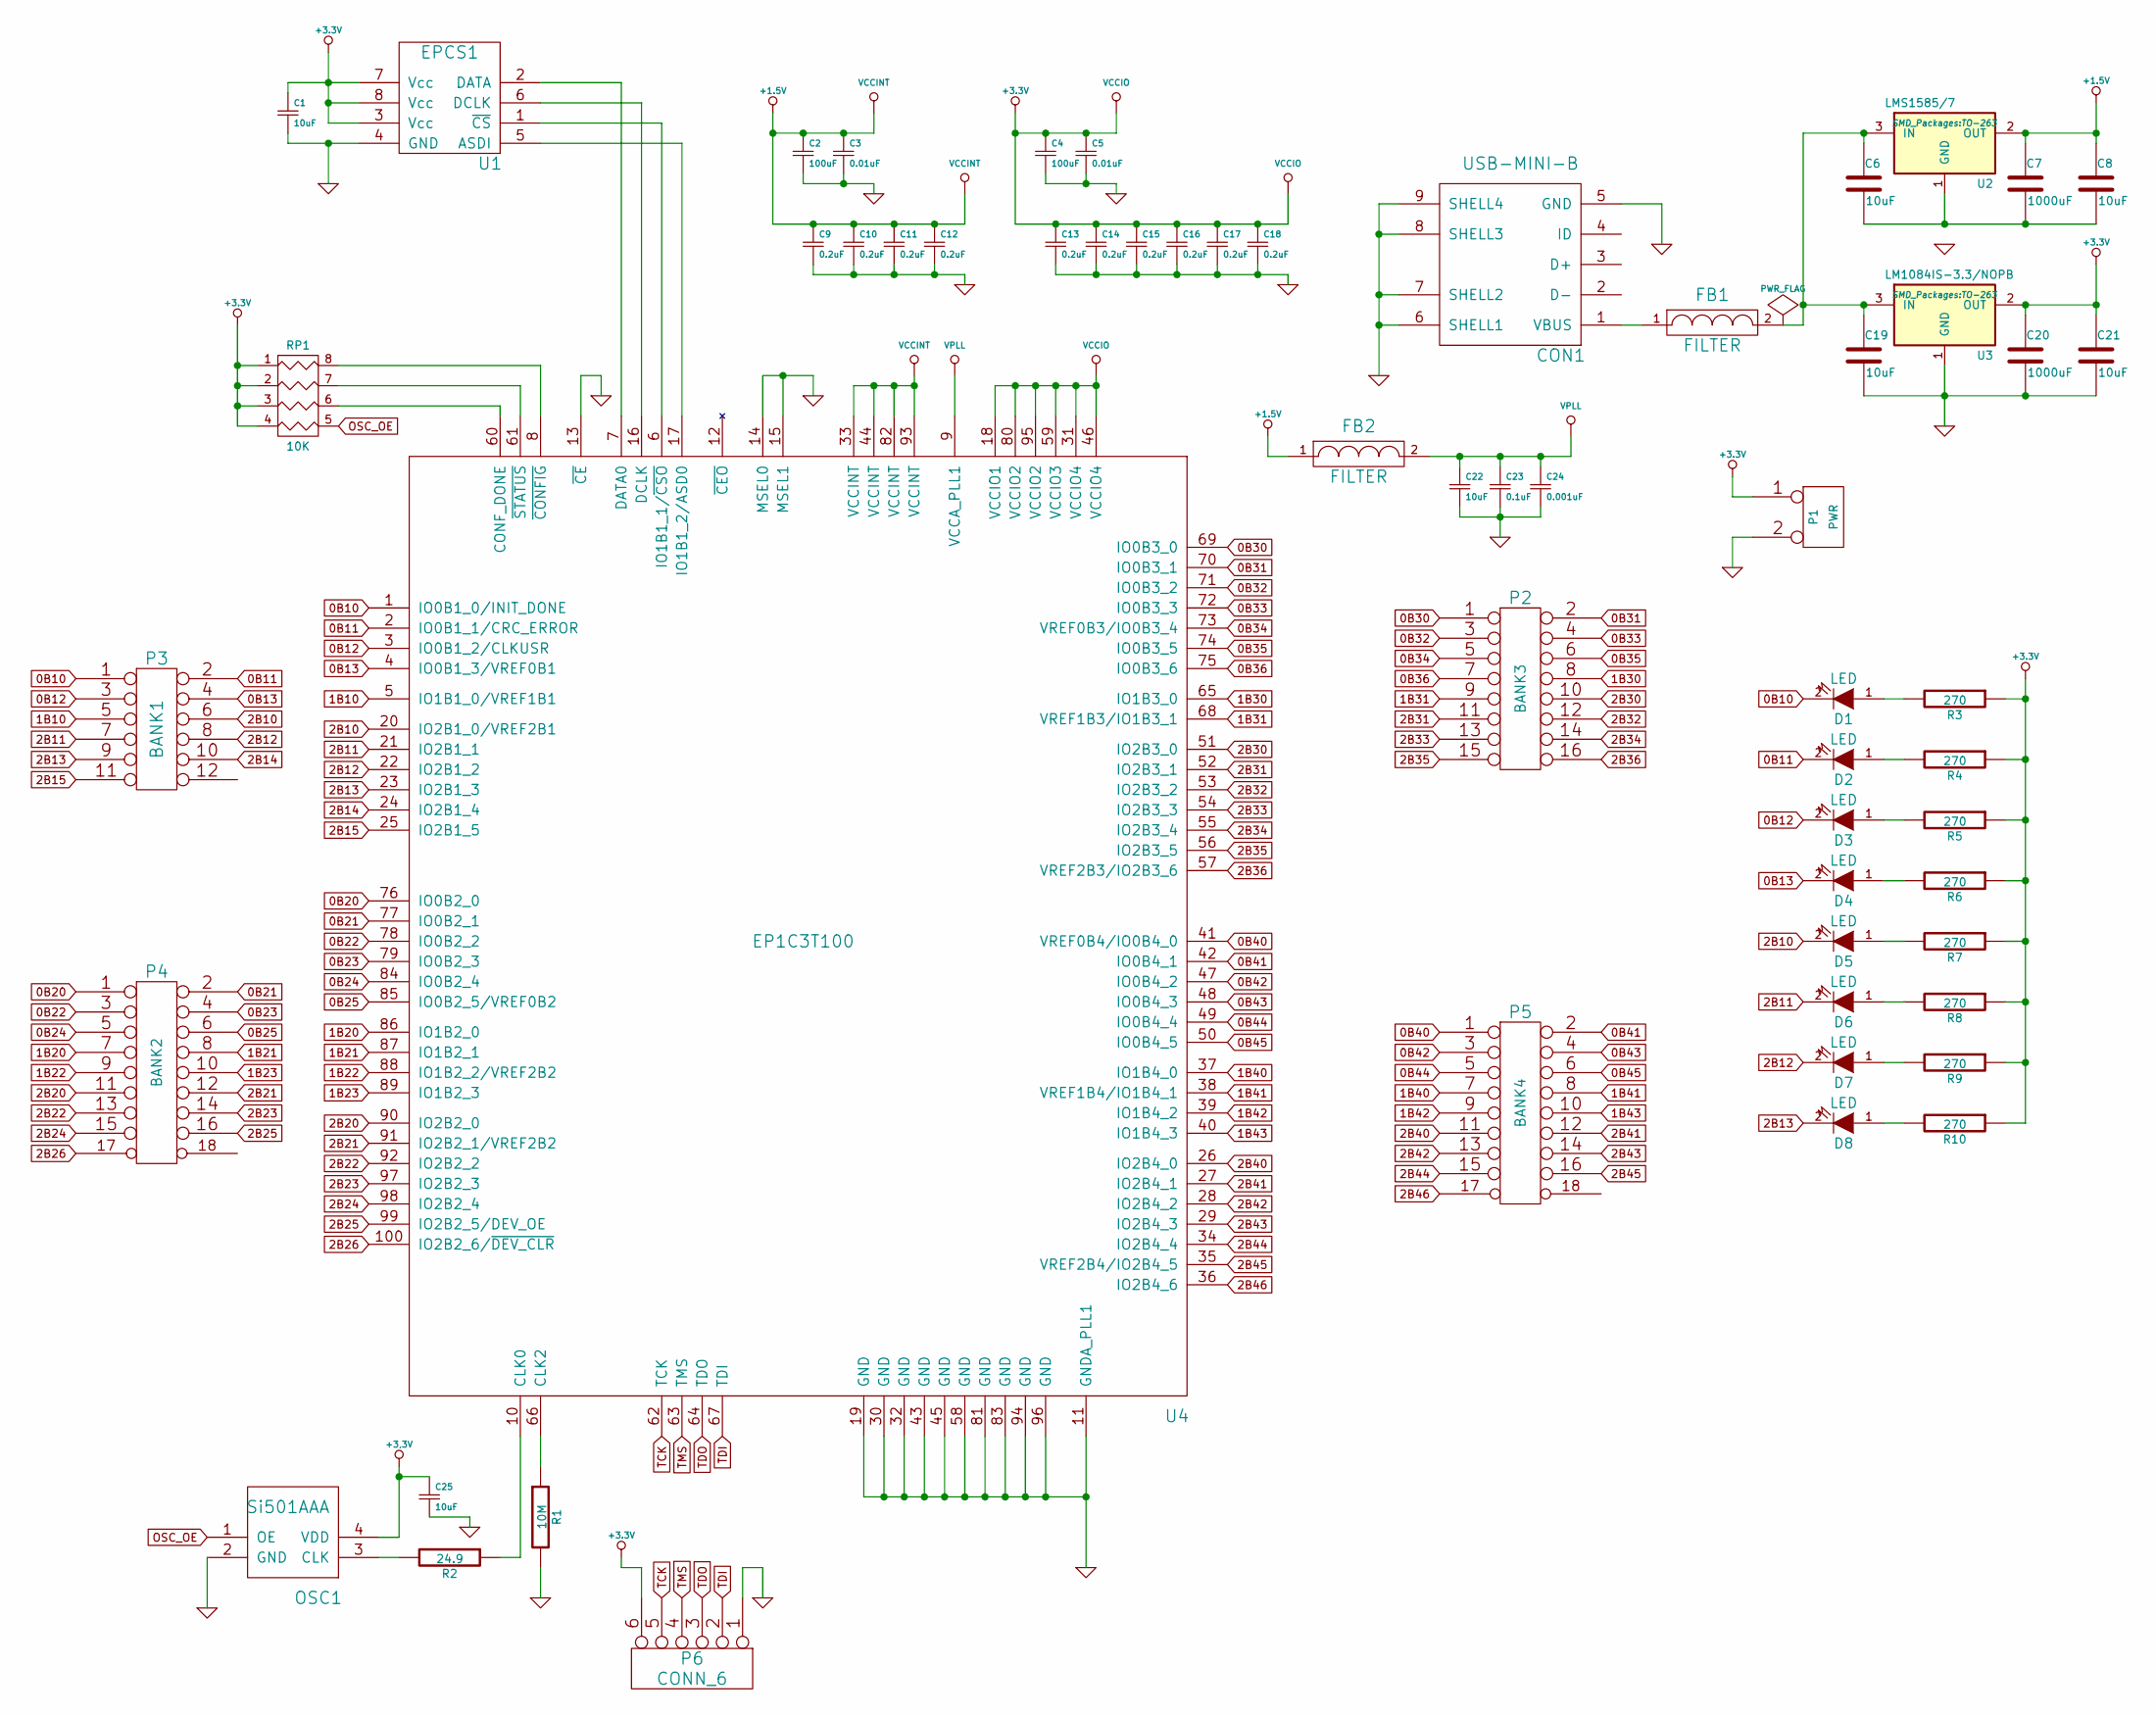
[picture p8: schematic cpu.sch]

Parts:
C1: 10uF; C_0805_HandSoldering
C2, C4: 100uF; C_0805_HandSoldering
C3, C5: 0.01uF; C_0805_HandSoldering
C6, C8: 10uF; c_elec_4x4.5
C7: 1000uF; c_elec_4x4.5; PARTNO EEEFK0J102AP
C9, C10, C11, C12, C13, C14, C15, C16, C17, C18: 0.2uF; C_0805_HandSoldering
C19, C21, C22: 10uF; c_elec_4x5.3
C20: 1000uF; c_elec_4x5.3; PARTNO EEEFK0J102AP
C23: 0.1uF; C_0805
C24: 0.001uF; C_0805
C25: 10uF; C_0805
CON1: USB-MINI-B; USB_Mini-B
D1: LED; LED-0805; PARTNO 5988150107F
D2, D3, D4, D5, D6, D7, D8: LED; LED-0805
FB1, FB2: FILTER; R_0805_HandSoldering; PARTNO MMZ2012Y202BT000
OSC1: Si501AAA; DFN4-Si501; PARTNO 501AAA50M0000DAF
P1: PWR; Pin_Header_Straight_1x02
P2: BANK3; Pin_Header_Straight_2x08
P3: BANK1; Pin_Header_Straight_2x06
P4: BANK2; Pin_Header_Straight_2x09
P5: BANK4; Pin_Header_Straight_2x09
P6: CONN_6; Pin_Header_Straight_1x06
R1: 10M; R_0805_HandSoldering
R2: 24.9; R_0805_HandSoldering
R3, R4, R5, R6, R7, R8, R9, R10: 270; R_0805_HandSoldering
RP1: 10K; R_Array_Convex_4x1206; PARTNO YC164-JR-0710KL
U1: EPCS1; SOIC-8-N; PARTNO EPCS1
U2: LMS1585/7; TO-263
U3: LM1084IS-3.3/NOPB; TO-263
U4: EP1C3T100; TQFP-100_14x14mm_Pitch0.5mm; PARTNO EP1C3T100C8N

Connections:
0B10: D1.2 (K), P3.1, U4.1 (IO0B1_0/INIT_DONE)
0B11: D2.2 (K), P3.2, U4.2 (IO0B1_1/CRC_ERROR)
0B12: D3.2 (K), P3.3, U4.3 (IO0B1_2/CLKUSR)
0B13: D4.2 (K), P3.4, U4.4 (IO0B1_3/VREF0B1)
0B20: P4.1, U4.76 (IO0B2_0)
0B21: P4.2, U4.77 (IO0B2_1)
0B22: P4.3, U4.78 (IO0B2_2)
0B23: P4.4, U4.79 (IO0B2_3)
0B24: P4.5, U4.84 (IO0B2_4)
0B25: P4.6, U4.85 (IO0B2_5/VREF0B2)
0B30: P2.1, U4.69 (IO0B3_0)
0B31: P2.2, U4.70 (IO0B3_1)
0B32: P2.3, U4.71 (IO0B3_2)
0B33: P2.4, U4.72 (IO0B3_3)
0B34: P2.5, U4.73 (VREF0B3/IO0B3_4)
0B35: P2.6, U4.74 (IO0B3_5)
0B36: P2.7, U4.75 (IO0B3_6)
0B40: P5.1, U4.41 (VREF0B4/IO0B4_0)
0B41: P5.2, U4.42 (IO0B4_1)
0B42: P5.3, U4.47 (IO0B4_2)
0B43: P5.4, U4.48 (IO0B4_3)
0B44: P5.5, U4.49 (IO0B4_4)
0B45: P5.6, U4.50 (IO0B4_5)
1B10: P3.5, U4.5 (IO1B1_0/VREF1B1)
1B20: P4.7, U4.86 (IO1B2_0)
1B21: P4.8, U4.87 (IO1B2_1)
1B22: P4.9, U4.88 (IO1B2_2/VREF2B2)
1B23: P4.10, U4.89 (IO1B2_3)
1B30: P2.8, U4.65 (IO1B3_0)
1B31: P2.9, U4.68 (VREF1B3/IO1B3_1)
1B40: P5.7, U4.37 (IO1B4_0)
1B41: P5.8, U4.38 (VREF1B4/IO1B4_1)
1B42: P5.9, U4.39 (IO1B4_2)
1B43: P5.10, U4.40 (IO1B4_3)
2B10: D5.2 (K), P3.6, U4.20 (IO2B1_0/VREF2B1)
2B11: D6.2 (K), P3.7, U4.21 (IO2B1_1)
2B12: D7.2 (K), P3.8, U4.22 (IO2B1_2)
2B13: D8.2 (K), P3.9, U4.23 (IO2B1_3)
2B14: P3.10, U4.24 (IO2B1_4)
2B15: P3.11, U4.25 (IO2B1_5)
2B20: P4.11, U4.90 (IO2B2_0)
2B21: P4.12, U4.91 (IO2B2_1/VREF2B2)
2B22: P4.13, U4.92 (IO2B2_2)
2B23: P4.14, U4.97 (IO2B2_3)
2B24: P4.15, U4.98 (IO2B2_4)
2B25: P4.16, U4.99 (IO2B2_5/DEV_OE)
2B26: P4.17, U4.100 (IO2B2_6/~DEV_CLR)
2B30: P2.10, U4.51 (IO2B3_0)
2B31: P2.11, U4.52 (IO2B3_1)
2B32: P2.12, U4.53 (IO2B3_2)
2B33: P2.13, U4.54 (IO2B3_3)
2B34: P2.14, U4.55 (IO2B3_4)
2B35: P2.15, U4.56 (IO2B3_5)
2B36: P2.16, U4.57 (VREF2B3/IO2B3_6)
2B40: P5.11, U4.26 (IO2B4_0)
2B41: P5.12, U4.27 (IO2B4_1)
2B42: P5.13, U4.28 (IO2B4_2)
2B43: P5.14, U4.29 (IO2B4_3)
2B44: P5.15, U4.34 (IO2B4_4)
2B45: P5.16, U4.35 (VREF2B4/IO2B4_5)
2B46: P5.17, U4.36 (IO2B4_6)
GND: C1.2, C2.2, C3.2, C4.2, C5.2, C9.2, C10.2, C11.2, C12.2, C13.2, C14.2, C15.2, C16.2, C17.2, C18.2, C19.2, C20.2, C21.2, C22.2, C23.2, C24.2, C25.2, CON1.5 (GND), CON1.6 (SHELL1), CON1.7 (SHELL2), CON1.8 (SHELL3), CON1.9 (SHELL4), OSC1.2 (GND), P1.2 (PM), P6.1, R1.2, U1.4 (GND), U3.1 (GND), U4.11 (GNDA_PLL1), U4.13 (~CE), U4.14 (MSEL0), U4.15 (MSEL1), U4.19 (GND), U4.30 (GND), U4.32 (GND), U4.43 (GND), U4.45 (GND), U4.58 (GND), U4.81 (GND), U4.83 (GND), U4.94 (GND), U4.96 (GND)
unnamed: C6.2, C7.2, C8.2, U2.1 (GND)
unnamed: C6.1, C19.1, FB1.2, U2.3 (IN), U3.3 (IN)
unnamed: CON1.1 (VBUS), FB1.1
unnamed: D1.1 (A), R3.2
unnamed: D2.1 (A), R4.2
unnamed: D3.1 (A), R5.2
unnamed: D4.1 (A), R6.2
unnamed: D5.1 (A), R7.2
unnamed: D6.1 (A), R8.2
unnamed: D7.1 (A), R9.2
unnamed: D8.1 (A), R10.2
unnamed: OSC1.3 (CLK), R2.2
unnamed: R1.1, U4.66 (CLK2)
unnamed: R2.1, U4.10 (CLK0)
unnamed: RP1.6 (R3), U4.60 (CONF_DONE)
unnamed: RP1.7 (R2), U4.61 (~STATUS)
unnamed: RP1.8 (R1), U4.8 (~CONFIG)
unnamed: U1.1 (~CS), U4.6 (IO1B1_1/~CSO)
unnamed: U1.2 (DATA), U4.7 (DATA0)
unnamed: U1.5 (ASDI), U4.17 (IO1B1_2/ASD0)
unnamed: U1.6 (DCLK), U4.16 (DCLK)
OSC_OE: OSC1.1 (OE), RP1.5 (R4)
TCK: P6.5, U4.62 (TCK)
TDI: P6.2, U4.67 (TDI)
TDO: P6.3, U4.64 (TDO)
TMS: P6.4, U4.63 (TMS)
VCCINT: C2.1, C3.1, C7.1, C8.1, C9.1, C10.1, C11.1, C12.1, FB2.1, U2.2 (OUT), U4.33 (VCCINT), U4.44 (VCCINT), U4.82 (VCCINT), U4.93 (VCCINT)
VPLL: C22.1, C23.1, C24.1, FB2.2, U4.9 (VCCA_PLL1)

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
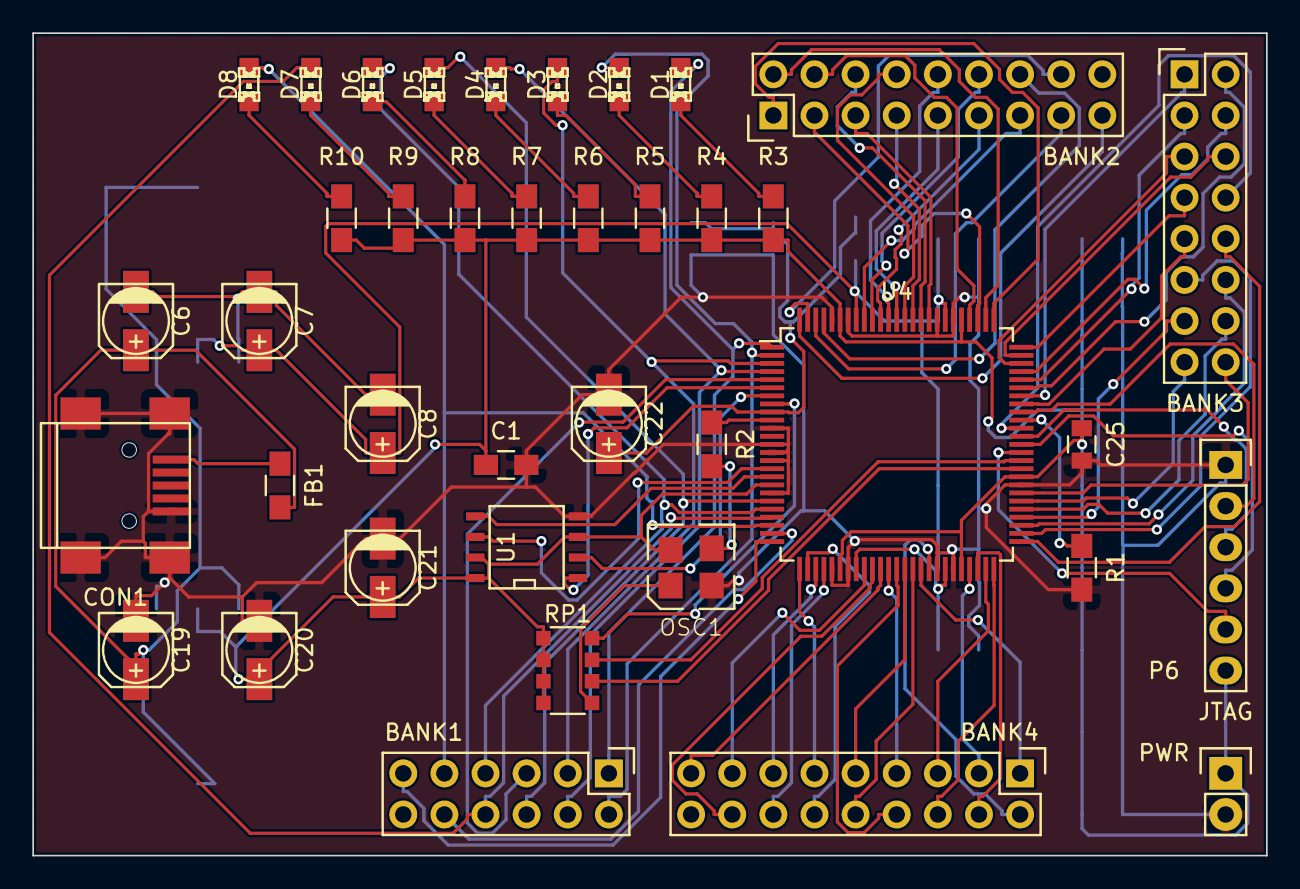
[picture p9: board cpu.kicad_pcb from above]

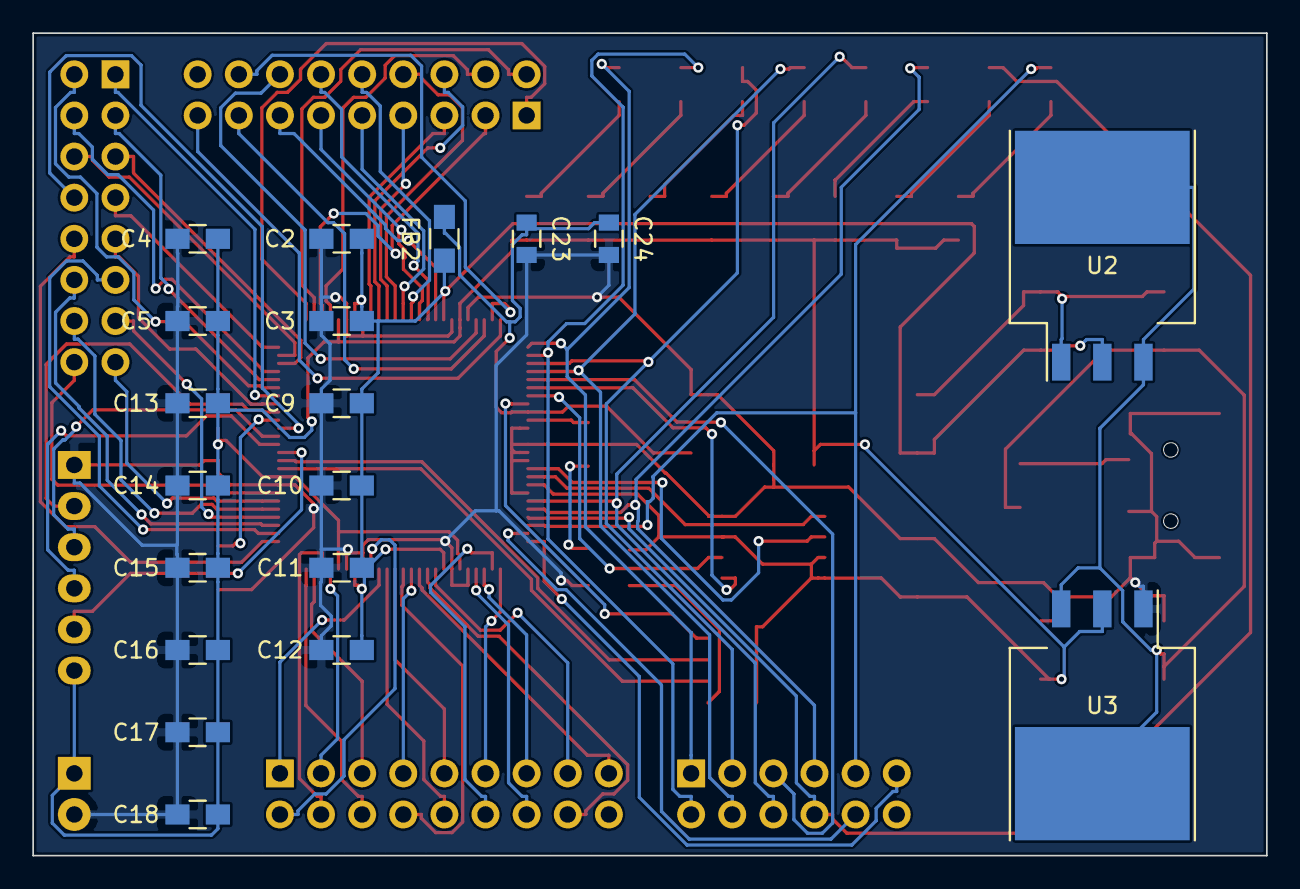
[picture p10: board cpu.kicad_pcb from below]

Board: 2 copper layers, 76.2 x 50.8 mm, 58 parts (19 on the bottom side), 91 nets.

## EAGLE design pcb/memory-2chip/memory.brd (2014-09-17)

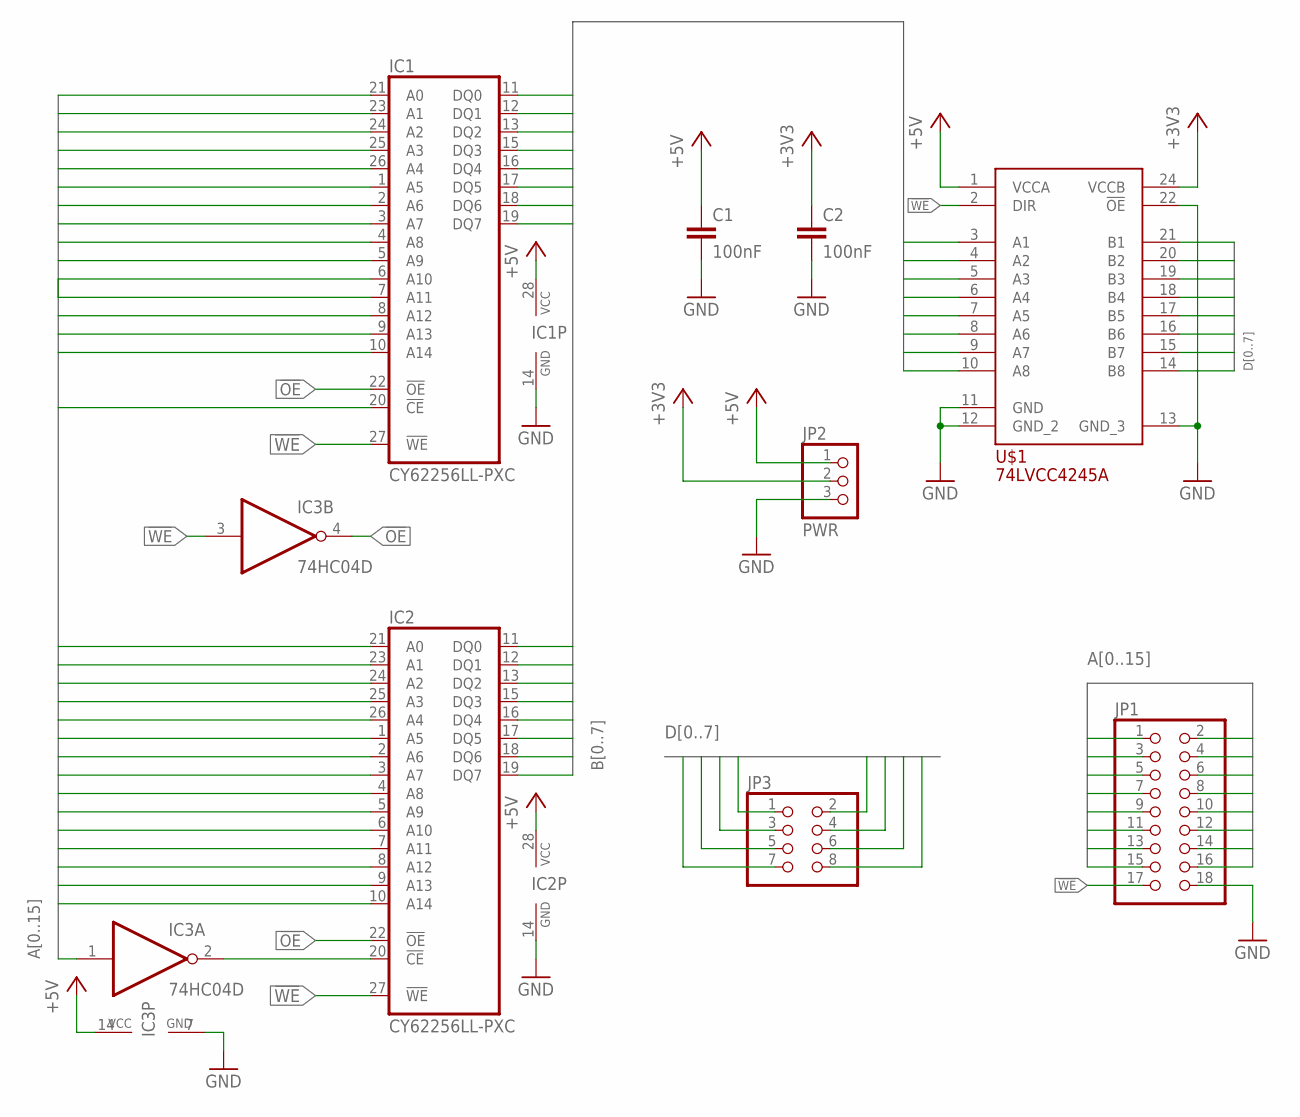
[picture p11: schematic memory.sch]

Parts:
C1, C2: 100nF; C0805
IC1, IC2: CY62256LL-PXC; DIL28-6
IC3: 74HC04D; SO14
JP1: PINHD-2X9; 2X09
JP2: PWR; 1X03
JP3: PINHD-2X4; 2X04
U$1: 74LCC4245A; SO24W

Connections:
!OE!: IC1.22 (!OE), IC2.22 (!OE), IC3.4 (O)
!WE!: IC1.27 (!WE), IC2.27 (!WE), IC3.3 (I), JP1.17, U$1.2 (DIR)
+3V3: C2.1, JP2.2, U$1.24 (VCCB)
+5V: C1.1, IC1.28 (VCC), IC2.28 (VCC), IC3.14 (VCC), JP2.1, U$1.1 (VCCA)
A0: IC1.21 (A0), IC2.21 (A0), JP1.1
A1: IC1.23 (A1), IC2.23 (A1), JP1.2
A2: IC1.24 (A2), IC2.24 (A2), JP1.3
A3: IC1.25 (A3), IC2.25 (A3), JP1.4
A4: IC1.26 (A4), IC2.26 (A4), JP1.5
A5: IC1.1 (A5), IC2.1 (A5), JP1.6
A6: IC1.2 (A6), IC2.2 (A6), JP1.7
A7: IC1.3 (A7), IC2.3 (A7), JP1.8
A8: IC1.4 (A8), IC2.4 (A8), JP1.9
A9: IC1.5 (A9), IC2.5 (A9), JP1.10
A10: IC1.6 (A10), IC2.6 (A10), JP1.11
A11: IC1.7 (A11), IC2.7 (A11), JP1.12
A12: IC1.8 (A12), IC2.8 (A12), JP1.13
A13: IC1.9 (A13), IC2.9 (A13), JP1.14
A14: IC1.10 (A14), IC2.10 (A14), JP1.15
A15: IC1.20 (!CE), IC3.1 (I), JP1.16
B0: IC1.11 (DQ0), IC2.11 (DQ0), U$1.3 (A1)
B1: IC1.12 (DQ1), IC2.12 (DQ1), U$1.4 (A2)
B2: IC1.13 (DQ2), IC2.13 (DQ2), U$1.5 (A3)
B3: IC1.15 (DQ3), IC2.15 (DQ3), U$1.6 (A4)
B4: IC1.16 (DQ4), IC2.16 (DQ4), U$1.7 (A5)
B5: IC1.17 (DQ5), IC2.17 (DQ5), U$1.8 (A6)
B6: IC1.18 (DQ6), IC2.18 (DQ6), U$1.9 (A7)
B7: IC1.19 (DQ7), IC2.19 (DQ7), U$1.10 (A8)
D0: JP3.1, U$1.21 (B1)
D1: JP3.2, U$1.20 (B2)
D2: JP3.3, U$1.19 (B3)
D3: JP3.4, U$1.18 (B4)
D4: JP3.5, U$1.17 (B5)
D5: JP3.6, U$1.16 (B6)
D6: JP3.7, U$1.15 (B7)
D7: JP3.8, U$1.14 (B8)
GND: C1.2, C2.2, IC1.14 (GND), IC2.14 (GND), IC3.7 (GND), JP1.18, JP2.3, U$1.11 (GND), U$1.12 (GND_2), U$1.13 (GND_3), U$1.22 (!OE!)
unnamed: IC2.20 (!CE), IC3.2 (O)

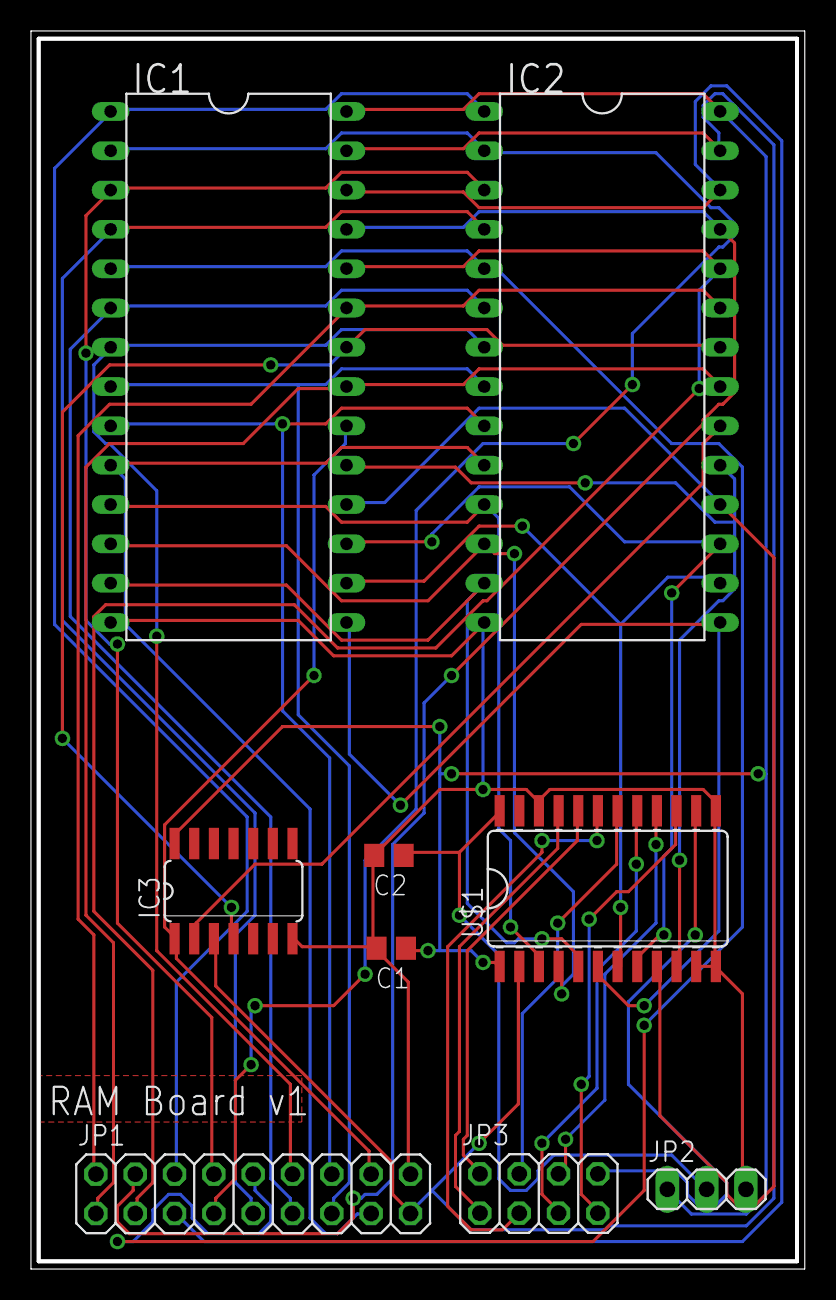
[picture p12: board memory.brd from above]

Board: 2 copper layers, 50.0 x 80.0 mm, 9 parts (0 on the bottom side), 38 nets.

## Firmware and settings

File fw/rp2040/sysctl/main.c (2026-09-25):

/*
 * System card firmware (doc/hardware/sysctl.md, system-slot.md): the sysctl
 * core (fw/sysctl/core) on the RP2040, talking USB CDC to cupc8.py on its
 * first serial port (CDC 0) and carrying the kernel's terminal on the second
 * (CDC 1, the console: doc/proposals/usb-console.md).
 *
 * At start-up it drives nothing on the machine: every machine-facing pin is
 * an input until a command needs it, and returns to one afterwards.
 */
#include "hardware/adc.h"
#include "hardware/gpio.h"
#include "hardware/i2c.h"
#include "hardware/pio.h"
#include "hardware/clocks.h"
#include "hardware/dma.h"
#include "hardware/spi.h"
#include "pico/stdlib.h"
#include "pins.h"
#include "sysctl.h"
#include "tusb.h"
#include "uart.pio.h"

#define BRIDGE_HZ 1000000       /* the chipset oversamples SCK: <= 1 MHz (memory-map.md) */
#define FLASH_HZ  10000000      /* W25Q; FL1 runs through the CPU socket */

static sysctl_t sys;

/* the machine-facing SPI pins of each bus: SCK, MOSI, MISO, CS_n */
static const uint8_t bus_pins[3][4] = {
	[SPI_BRIDGE] = { PIN_BR_SCK, PIN_BR_MOSI, PIN_BR_MISO, PIN_BR_NCS },
	[SPI_FL0] = { PIN_FL0_SCK, PIN_FL0_MOSI, PIN_FL0_MISO, PIN_FL0_NCS },
	[SPI_FL1] = { PIN_FL1_SCK, PIN_FL1_MOSI, PIN_FL1_MISO, PIN_FL1_NCS },
};
static int selected = SPI_NONE;

static void release_bus(int bus)
{
	for (int i = 0; i < 4; i++) {
		gpio_set_function(bus_pins[bus][i], GPIO_FUNC_SIO);
		gpio_set_dir(bus_pins[bus][i], false);   /* Hi-Z: the FPGA owns its flash */
	}
}

static void h_spi_select(void *ctx, int bus)
{
	(void)ctx;
	if (selected != SPI_NONE)
		release_bus(selected);
	selected = bus;
	if (bus == SPI_NONE)
		return;
	spi_inst_t *spi = bus == SPI_BRIDGE ? spi0 : spi1;
	spi_set_baudrate(spi, bus == SPI_BRIDGE ? BRIDGE_HZ : FLASH_HZ);
	for (int i = 0; i < 3; i++)
		gpio_set_function(bus_pins[bus][i], GPIO_FUNC_SPI);
	gpio_put(bus_pins[bus][3], 0);                /* CS_n by hand: frames span calls */
	gpio_set_dir(bus_pins[bus][3], true);
}

static void h_spi_xfer(void *ctx, const uint8_t *tx, uint8_t *rx, int n)
{
	(void)ctx;
	if (selected == SPI_NONE)
		return;
	spi_inst_t *spi = selected == SPI_BRIDGE ? spi0 : spi1;
	static const uint8_t zero[64];
	while (n > 0) {
		int k = n > 64 ? 64 : n;
		const uint8_t *t = tx ? tx : zero;
		if (rx)
			spi_write_read_blocking(spi, t, rx, (size_t)k);
		else
			spi_write_blocking(spi, t, (size_t)k);
		if (tx)
			tx += k;
		if (rx)
			rx += k;
		n -= k;
	}
}

static const uint8_t hal_pins[] = {
	[HAL_CHIPSET_CRESET] = PIN_CHIPSET_NCRESET, [HAL_CHIPSET_CDONE] = PIN_CHIPSET_CDONE,
	[HAL_CPUCARD_CRESET] = PIN_CPUCARD_NCRESET, [HAL_CPUCARD_CDONE] = PIN_CPUCARD_CDONE,
	[HAL_SYS_NRST] = PIN_SYS_NRST,
};

/* open drain: low is driven, high is released to the board's pull-up */
static void h_pin_write(void *ctx, int pin, bool level)
{
	(void)ctx;
	gpio_set_dir(hal_pins[pin], !level);
}

static bool h_pin_read(void *ctx, int pin)
{
	(void)ctx;
	return gpio_get(hal_pins[pin]);
}

static int h_adc_mv(void *ctx, int ch)
{
	(void)ctx;
	adc_select_input((uint)(ch == ADC_CC1 ? 0 : ch == ADC_CC2 ? 1 : 2));
	return (int)(adc_read() * 3300u / 4096u);
}

static int h_i2c_write(void *ctx, uint8_t addr, const uint8_t *data, int n)
{
	(void)ctx;
	return i2c_write_timeout_us(i2c0, addr, data, (size_t)n, false, 10000) == n ? 0 : -1;
}

static int h_i2c_read(void *ctx, uint8_t addr, uint8_t reg, uint8_t *data, int n)
{
	(void)ctx;
	if (i2c_write_timeout_us(i2c0, addr, &reg, 1, true, 10000) != 1)
		return -1;
	return i2c_read_timeout_us(i2c0, addr, data, (size_t)n, false, 10000) == n ? 0 : -1;
}

static void h_delay_us(void *ctx, uint32_t us)
{
	(void)ctx;
	sleep_us(us);
}

static uint32_t h_now_ms(void *ctx)
{
	(void)ctx;
	return to_ms_since_boot(get_absolute_time());
}

/* USB activity LEDs (milestone-1.md, Indicator LEDs): each is lit until
 * its deadline, ~30 ms after the last data in its direction */
#define ACTIVITY_MS 30
static uint32_t led_tx_until, led_rx_until;

static void activity(uint32_t *until)
{
	*until = to_ms_since_boot(get_absolute_time()) + ACTIVITY_MS;
}

enum { CDC_PROTOCOL = 0, CDC_CONSOLE = 1 };

static void h_usb_write(void *ctx, const uint8_t *data, int n)
{
	(void)ctx;
	if (n > 0)
		activity(&led_tx_until);
	while (n > 0 && tud_cdc_n_connected(CDC_PROTOCOL)) {
		uint32_t k = tud_cdc_n_write(CDC_PROTOCOL, data, (uint32_t)n);
		data += k;
		n -= (int)k;
		tud_cdc_n_write_flush(CDC_PROTOCOL);
		if (!k)
			tud_task();
	}
}

/* ------------------------------------------------------------ the console */

static bool usb_started, usb_on;

/* the host's VBUS gone counts as closed: HOST is cleared, the kernel stops waiting */
static bool h_con_open(void *ctx)
{
	(void)ctx;
	return usb_on && tud_cdc_n_connected(CDC_CONSOLE);
}

static int h_con_room(void *ctx)
{
	(void)ctx;
	return (int)tud_cdc_n_write_available(CDC_CONSOLE);
}

static void h_con_write(void *ctx, const uint8_t *data, int n)
{
	(void)ctx;
	if (n <= 0)
		return;
	activity(&led_tx_until);
	tud_cdc_n_write(CDC_CONSOLE, data, (uint32_t)n);   /* fits: con_room said so */
	tud_cdc_n_write_flush(CDC_CONSOLE);
}

static int h_con_read(void *ctx, uint8_t *data, int max)
{
	(void)ctx;
	int n = (int)tud_cdc_n_read(CDC_CONSOLE, data, (uint32_t)max);
	if (n > 0)
		activity(&led_rx_until);
	return n;
}

/* ---------------------------------------------------- the programming port */

static const uint8_t mux_pins[3] = { PIN_MUX_SEL0, PIN_MUX_SEL1, PIN_MUX_SEL2 };

/* a slot: MUX_SEL driven; -1: released, and the board's pull-ups pick the
 * unconnected channel 7 */
static void h_prog_select(void *ctx, int slot)
{
	(void)ctx;
	for (int i = 0; i < 3; i++) {
		gpio_put(mux_pins[i], slot >= 0 && (slot >> i & 1));
		gpio_set_dir(mux_pins[i], slot >= 0);
	}
}

#define SWD_HALF_US 1           /* ~500 kHz: slow enough for the mux and 33 ohm */
static bool swdio_out;

static void swd_clock(void)
{
	sleep_us(SWD_HALF_US);
	gpio_put(PIN_PROG_CLK, 1);
	sleep_us(SWD_HALF_US);
	gpio_put(PIN_PROG_CLK, 0);
}

/* SWDIO changes while SWCLK is low; the target samples on the rising edge
 * and drives its bits after it, so the host samples just before the next one */
static void h_swd_io(void *ctx, bool out, uint32_t *bits, int n)
{
	(void)ctx;
	gpio_set_dir(PIN_PROG_CLK, true);
	if (out != swdio_out) {
		/* turnaround: one clock with nobody driving SWDIO */
		gpio_set_dir(PIN_PROG_IO, false);
		swd_clock();
		gpio_set_dir(PIN_PROG_IO, out);
		swdio_out = out;
	}
	if (!out)
		*bits = 0;
	for (int i = 0; i < n; i++) {
		if (out) {
			gpio_put(PIN_PROG_IO, *bits >> i & 1);
			swd_clock();
		} else {
			sleep_us(SWD_HALF_US);
			*bits |= (uint32_t)gpio_get(PIN_PROG_IO) << i;
			gpio_put(PIN_PROG_CLK, 1);
			sleep_us(SWD_HALF_US);
			gpio_put(PIN_PROG_CLK, 0);
		}
	}
}

static PIO uart_pio = pio0;
static uint uart_tx_sm, uart_rx_sm, uart_tx_prog, uart_rx_prog;
static bool uart_on;

/* received bytes stream into a ring by DMA: the PIO FIFO holds 8, and the
 * host polls about once a millisecond, when 11 can arrive at 115200 */
#define RX_RING_BITS 12
static uint8_t rx_ring[1u << RX_RING_BITS] __attribute__((aligned(1u << RX_RING_BITS)));
static int rx_dma = -1;
static uint32_t rx_tail;                       /* free-running */

static uint32_t rx_head(void)
{
	return 0xffffffffu - dma_channel_hw_addr((uint)rx_dma)->transfer_count;
}

static void port_release(void)
{
	gpio_set_function(PIN_PROG_CLK, GPIO_FUNC_SIO);
	gpio_set_function(PIN_PROG_IO, GPIO_FUNC_SIO);
	gpio_set_dir(PIN_PROG_CLK, false);
	gpio_set_dir(PIN_PROG_IO, false);
	gpio_put(PIN_PROG_CLK, 0);
	swdio_out = false;
}

static void h_uart_open(void *ctx, uint32_t baud)
{
	(void)ctx;
	if (uart_on) {
		pio_sm_set_enabled(uart_pio, uart_tx_sm, false);
		pio_sm_set_enabled(uart_pio, uart_rx_sm, false);
		dma_channel_abort((uint)rx_dma);
		uart_on = false;
	}
	port_release();
	if (!baud)
		return;
	float div = (float)clock_get_hz(clk_sys) / (8.0f * (float)baud);
	/* TX on PROG_CLK */
	pio_sm_config c = port_uart_tx_program_get_default_config(uart_tx_prog);
	sm_config_set_out_shift(&c, true, false, 32);
	sm_config_set_out_pins(&c, PIN_PROG_CLK, 1);
	sm_config_set_sideset_pins(&c, PIN_PROG_CLK);
	sm_config_set_fifo_join(&c, PIO_FIFO_JOIN_TX);
	sm_config_set_clkdiv(&c, div);
	pio_sm_set_pins_with_mask(uart_pio, uart_tx_sm, 1u << PIN_PROG_CLK, 1u << PIN_PROG_CLK);
	pio_sm_set_pindirs_with_mask(uart_pio, uart_tx_sm, 1u << PIN_PROG_CLK, 1u << PIN_PROG_CLK);
	pio_gpio_init(uart_pio, PIN_PROG_CLK);
	pio_sm_init(uart_pio, uart_tx_sm, uart_tx_prog, &c);
	/* RX on PROG_IO */
	c = port_uart_rx_program_get_default_config(uart_rx_prog);
	sm_config_set_in_pins(&c, PIN_PROG_IO);
	sm_config_set_jmp_pin(&c, PIN_PROG_IO);
	sm_config_set_in_shift(&c, true, false, 32);
	sm_config_set_fifo_join(&c, PIO_FIFO_JOIN_RX);
	sm_config_set_clkdiv(&c, div);
	gpio_pull_up(PIN_PROG_IO);
	pio_sm_init(uart_pio, uart_rx_sm, uart_rx_prog, &c);
	/* the byte is in bits 31:24 of the RX FIFO word: DMA its top byte */
	dma_channel_config d = dma_channel_get_default_config((uint)rx_dma);
	channel_config_set_transfer_data_size(&d, DMA_SIZE_8);
	channel_config_set_read_increment(&d, false);
	channel_config_set_write_increment(&d, true);
	channel_config_set_ring(&d, true, RX_RING_BITS);
	channel_config_set_dreq(&d, pio_get_dreq(uart_pio, uart_rx_sm, false));
	dma_channel_configure((uint)rx_dma, &d, rx_ring, (const uint8_t *)&uart_pio->rxf[uart_rx_sm] + 3, 0xffffffffu, true);
	rx_tail = 0;
	pio_sm_set_enabled(uart_pio, uart_tx_sm, true);
	pio_sm_set_enabled(uart_pio, uart_rx_sm, true);
	uart_on = true;
}

static void h_uart_write(void *ctx, const uint8_t *d, int n)
{
	(void)ctx;
	for (int i = 0; i < n && uart_on; i++)
		pio_sm_put_blocking(uart_pio, uart_tx_sm, d[i]);
}

static int h_uart_read(void *ctx, uint8_t *d, int max)
{
	(void)ctx;
	int n = 0;
	if (!uart_on)
		return 0;
	uint32_t head = rx_head();
	if (head - rx_tail > sizeof rx_ring)
		rx_tail = head - sizeof rx_ring;      /* overrun: keep the newest */
	while (n < max && rx_tail != head)
		d[n++] = rx_ring[rx_tail++ % sizeof rx_ring];
	return n;
}

static const sysctl_hal hal = {
	.spi_select = h_spi_select, .spi_xfer = h_spi_xfer, .pin_write = h_pin_write, .pin_read = h_pin_read,
	.adc_mv = h_adc_mv, .i2c_write = h_i2c_write, .i2c_read = h_i2c_read, .delay_us = h_delay_us,
	.now_ms = h_now_ms, .usb_write = h_usb_write,
	.prog_select = h_prog_select, .swd_io = h_swd_io,
	.uart_open = h_uart_open, .uart_write = h_uart_write, .uart_read = h_uart_read,
	.con_open = h_con_open, .con_room = h_con_room, .con_write = h_con_write, .con_read = h_con_read,
};

int main(void)
{
	/* every machine-facing pin an input: nothing is driven until asked */
	for (int b = 0; b < 3; b++) {
		for (int i = 0; i < 4; i++)
			gpio_init(bus_pins[b][i]);
		release_bus(b);
	}
	spi_init(spi0, BRIDGE_HZ);
	spi_init(spi1, FLASH_HZ);
	for (unsigned i = 0; i < sizeof hal_pins; i++) {
		gpio_init(hal_pins[i]);
		gpio_put(hal_pins[i], 0);       /* only ever driven low, when output */
		gpio_set_dir(hal_pins[i], false);
	}
	i2c_init(i2c0, 100000);
	gpio_set_function(PIN_I2C_SDA, GPIO_FUNC_I2C);
	gpio_set_function(PIN_I2C_SCL, GPIO_FUNC_I2C);
	adc_init();
	adc_gpio_init(PIN_CC1_SENSE);
	adc_gpio_init(PIN_CC2_SENSE);
	adc_gpio_init(PIN_V1V2_SENSE);
	for (int i = 0; i < 3; i++)
		gpio_init(mux_pins[i]);             /* inputs: the mux parks on channel 7 */
	gpio_init(PIN_PROG_CLK);
	gpio_init(PIN_PROG_IO);
	port_release();
	uart_tx_prog = pio_add_program(uart_pio, &port_uart_tx_program);
	uart_rx_prog = pio_add_program(uart_pio, &port_uart_rx_program);
	uart_tx_sm = (uint)pio_claim_unused_sm(uart_pio, true);
	uart_rx_sm = (uint)pio_claim_unused_sm(uart_pio, true);
	rx_dma = dma_claim_unused_channel(true);
	gpio_init(PIN_USB_NVBUS);                /* input: low while the host's VBUS is there */
	gpio_pull_up(PIN_USB_NVBUS);             /* the card has 10k to 3V3 too */
	gpio_init(PIN_LED_USB_TX);
	gpio_set_dir(PIN_LED_USB_TX, true);
	gpio_init(PIN_LED_USB_RX);
	gpio_set_dir(PIN_LED_USB_RX, true);

	sysctl_init(&sys, &hal, NULL);
	/* A self-powered device must not pull D+ up while VBUS is absent (USB 2.0,
	 * 7.1.5): the card runs from the slot, so it starts USB only once the host's
	 * VBUS is seen, and lets go of the bus (the pull-up) whenever it goes. */
	for (;;) {
		bool vbus = !gpio_get(PIN_USB_NVBUS);
		if (vbus && !usb_started) {
			tusb_init();                     /* enables the pull-up */
			usb_started = usb_on = true;
		} else if (usb_started && vbus != usb_on) {
			if (vbus)
				tud_connect();
			else
				tud_disconnect();
			usb_on = vbus;
		}
		if (usb_started)
			tud_task();
		uint8_t buf[256];
		uint32_t n = usb_started && tud_cdc_n_available(CDC_PROTOCOL) ? tud_cdc_n_read(CDC_PROTOCOL, buf, sizeof buf) : 0;
		if (n) {
			activity(&led_rx_until);
			sysctl_rx(&sys, buf, (int)n);
		}
		sysctl_poll(&sys);                   /* and the console, while it is open */
		uint32_t now = to_ms_since_boot(get_absolute_time());
		gpio_put(PIN_LED_USB_TX, (int32_t)(led_tx_until - now) > 0);
		gpio_put(PIN_LED_USB_RX, (int32_t)(led_rx_until - now) > 0);
	}
}

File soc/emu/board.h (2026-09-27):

// The main board of the whole-machine emulator: the Verilated CPU + chipset
// netlist (machine_core.vhd), the SRAM, and the SST39VF040 ROM chip
// (fw/test/sysmodels.c, the same model as the sysctl tests). Shared by the
// Node addon test/emu/machine.mjs uses (soc/emu/core.cpp) and the native
// whole-machine emulator (emu/machine/).
//
// inputs:  bit 0 SPI MISO, 1-6 SLOT_nIRQ[5:0], 7 BR_SCK, 8 BR_MOSI, 9 BR_nCS,
//          10 PWR_HI, 11 CPU_CDONE, 12 nPOR, 13 CPU reset copper continuity
// outputs: bit 0 SPI SCK, 1 MOSI, 2-8 SPI_nCS[6:0], 9 BR_MISO, 10 CPU_nRST,
//          11 halted, 16-23 GPO
#pragma once

#include <cstddef>
#include <cstdint>
#include <cstring>
#include <array>

#include "Vmachine_core.h"
#include "verilated.h"

extern "C" {
#include "sysmodels.h"
}

struct MainBoard {
	static constexpr double NS_PER_CLOCK = 1000.0 / 12.0;
	struct MemoryWiring {
		std::array<uint8_t, 19> ramAddress{}, romAddress{};
		std::array<uint8_t, 8> ramData{}, romData{};
		std::array<uint8_t, 16> cpuAddress{};
		std::array<uint8_t, 8> cpuData{};
		std::array<uint8_t, 16> cpuAddressConnected{};
		std::array<uint8_t, 8> cpuDataConnected{};
		MemoryWiring() {
			for (unsigned i = 0; i < 19; ++i) ramAddress[i] = romAddress[i] = i;
			for (unsigned i = 0; i < 16; ++i) { cpuAddress[i] = i; cpuAddressConnected[i] = 1; }
			for (unsigned i = 0; i < 8; ++i) {
				ramData[i] = romData[i] = cpuData[i] = i;
				cpuDataConnected[i] = 1;
			}
		}
	};
	MemoryWiring wiring;
	bool timedMemory = false;
	double ramAccessNs = 45.0, romAccessNs = 70.0;
	bool ramWriteConnected = true, romWriteConnected = true;
	bool romD0Connected = true;

	Vmachine_core *top = nullptr;
	sst39_t rom;
	uint8_t ram[1 << 19];                 // the 512 KB SRAM, all 19 address lines (banked RAM, extended-ram.md)
	uint64_t clocks = 0;
	int last_we = 1;
	uint8_t last_din = 0;
	int reading = 0;                      // 1 RAM, 2 ROM: a read cycle in progress
	uint32_t read_addr = 0;
	uint8_t read_data = 0;
	uint8_t pending_data = 0;
	double read_ready_ns = 0;

	MainBoard() = default;
	MainBoard(const MainBoard &) = delete;
	MainBoard &operator=(const MainBoard &) = delete;
	~MainBoard() { delete top; }

	// a 512 KB ROM image (the chip's contents); nPOR held low
	void init(const void *data, size_t len)
	{
		delete top;
		top = new Vmachine_core;
		uint64_t addressMap = 0;
		uint32_t dataMap = 0, dataInverse = 0;
		for (unsigned i = 0; i < 16; ++i) addressMap |= uint64_t(wiring.cpuAddress[i]) << (4 * i);
		for (unsigned i = 0; i < 8; ++i) {
			dataMap |= uint32_t(wiring.cpuData[i]) << (3 * i);
			dataInverse |= uint32_t(i) << (3 * wiring.cpuData[i]);
		}
		top->cpu_a_map = addressMap;
		top->cpu_d_map = dataMap;
		top->cpu_d_inv_map = dataInverse;
		uint16_t addressConnected = 0;
		uint8_t dataConnected = 0;
		for (unsigned i = 0; i < 16; ++i) addressConnected |= uint16_t(wiring.cpuAddressConnected[i] != 0) << i;
		for (unsigned i = 0; i < 8; ++i) dataConnected |= uint8_t(wiring.cpuDataConnected[i] != 0) << i;
		top->cpu_a_connected = addressConnected;
		top->cpu_d_connected = dataConnected;
		sst39_init(&rom);
		memcpy(rom.mem, data, len < sizeof rom.mem ? len : sizeof rom.mem);
		for (size_t i = 0; i < sizeof ram; i++)
			ram[i] = (uint8_t)(i * 13 + 5);                // SRAM powers up with junk
		clocks = 0;
		last_we = 1;
		reading = 0;
		read_ready_ns = 0;
		apply(1 | 0x3F << 1 | 1 << 9 | 1 << 11);         // nPOR low: the supervisor holds reset
		top->clk = 0;
		top->eval();
	}

	uint32_t outputs() const
	{
		return (uint32_t)top->spi_sck | top->spi_mosi << 1 | (uint32_t)top->spi_n_cs << 2 | top->br_miso << 9 |
		       top->cpu_n_rst << 10 | top->cpu_halted << 11 | (uint32_t)top->gpo << 16;
	}

	double ns() const { return clocks * NS_PER_CLOCK; }
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

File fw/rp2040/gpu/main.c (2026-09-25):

/*
 * Graphics card firmware (doc/hardware/gpu-protocol.md): 640x480 DVI from
 * PicoDVI on an RP2040 at 252 MHz, the TMDS bit clock.
 *
 * Core 0: the slot SPI slave (fw/rp2040/common/slotspi.c), command execution
 * (fw/gpu/core/gpu.c, the same core the host tests and simulator use), the
 * frame count, and PicoDVI's DMA interrupt.
 * Core 1: renders every scanline from the GPU state straight to TMDS:
 *   TEXT: tmds_encode_font_2bpp, 80x30 cells, fg/bg in RGB222
 *   GFX:  the 320-pixel line through the palette to RGB565, pixel-doubled
 */
#include <string.h>

#include "dvi.h"
#include "dvi_serialiser.h"
#include "gpu.h"
#include "hardware/clocks.h"
#include "hardware/irq.h"
#include "hardware/structs/bus_ctrl.h"
#include "hardware/vreg.h"
#include "pico/multicore.h"
#include "pico/stdlib.h"
#include "pins.h"
#include "slotspi.h"
#include "tmds_encode.h"
#include "tmds_encode_font_2bpp.h"

#define DVI_TIMING dvi_timing_640x480p_60hz
#define WORDS_PER_LANE (GPU_OUT_W / DVI_SYMBOLS_PER_WORD)
#define COLOUR_WORDS (GPU_TEXT_COLS * 4 / 32)          /* one plane of one text row */

/* our TMDS pins (hw/pins.yaml): lanes blue, green, red; GPIO n+1 is P (the
 * pads invert), which puts the pairs in the HDMI receptacle's order */
static const struct dvi_serialiser_cfg gpu_dvi_cfg = {
	.pio = pio0,
	.sm_tmds = { 0, 1, 2 },
	.pins_tmds = { PIN_TMDS_D00, PIN_TMDS_D10, PIN_TMDS_D20 },
	.pins_clk = PIN_TMDS_CLK0,
	.invert_diffpairs = true,
};

static gpu_t gpu;
static struct dvi_inst dvi0;
static volatile uint32_t frames;               /* frames finished by core 1 */

/* core 1's scanline state */
static uint8_t font_lines[16][256];            /* font16 by scanline: [line][char] */
static uint16_t attr_nibbles[256];             /* attr -> fg|bg<<2 for each plane, 4 bits each */
/* the text screen as core 1 shows it, snapshotted in each vertical blank */
static uint8_t frame_chars[GPU_TEXT_ROWS][GPU_TEXT_COLS];
static uint32_t frame_colour[GPU_TEXT_ROWS][3 * COLOUR_WORDS];
static uint32_t cursor_colour[3 * COLOUR_WORDS];       /* the cursor's row, its cell swapped */
static uint16_t line565[GPU_GFX_W];

/* TEXT colours are the palette's first 16 entries in RGB222: blue in bits
 * 1:0 (lane 0), green 3:2, red 5:4. The VGA defaults are exact. */
static uint32_t rgb222(uint16_t c)
{
	return (uint32_t)(((c & 0x1f) >> 3) | (((c >> 5) & 0x3f) >> 4) << 2 | ((c >> 11) >> 3) << 4);
}

static uint8_t rev8(uint8_t b)
{
	b = (uint8_t)((b & 0xf0) >> 4 | (b & 0x0f) << 4);
	b = (uint8_t)((b & 0xcc) >> 2 | (b & 0x33) << 2);
	return (uint8_t)((b & 0xaa) >> 1 | (b & 0x55) << 1);
}

static bool cursor_on(void)
{
	return gpu.cursor != 0 && (gpu.vsync_count / 15) % 2 == 0;     /* as gpu_render() */
}

/* once a frame: what each attribute byte looks like in the three planes */
static void make_attr_nibbles(void)
{
	uint32_t c[16];
	for (int i = 0; i < 16; i++)
		c[i] = rgb222(gpu.palette[i]);
	for (int a = 0; a < 256; a++) {
		uint32_t fg = c[a & 15], bg = c[a >> 4], n = 0;
		for (int plane = 0; plane < 3; plane++)
			n |= (((fg >> (2 * plane)) & 3) | ((bg >> (2 * plane)) & 3) << 2) << (4 * plane);
		attr_nibbles[a] = (uint16_t)n;
	}
}

/* Build text row `row` for this frame. All 30 are built in the vertical
 * blank, so a scanline only pays for its three TMDS encodes. */
static void __not_in_flash_func(build_row)(int row)
{
	uint32_t *colour = frame_colour[row];
	memset(colour, 0, 3 * COLOUR_WORDS * sizeof(uint32_t));
	for (int col = 0; col < GPU_TEXT_COLS; col++) {
		gpu_cell_t cell = gpu.text[row][col];
		frame_chars[row][col] = cell.ch;
		uint32_t nib = attr_nibbles[cell.attr];
		int w = col / 8, sh = (col % 8) * 4;
		colour[w] |= (nib & 0xf) << sh;
		colour[COLOUR_WORDS + w] |= ((nib >> 4) & 0xf) << sh;
		colour[2 * COLOUR_WORDS + w] |= ((nib >> 8) & 0xf) << sh;
	}
}

/* the cursor inverts its cell: the same row with that cell's fg and bg swapped */
static void make_cursor_row(int row, int col)
{
	memcpy(cursor_colour, frame_colour[row], sizeof cursor_colour);
	int w = col / 8, sh = (col % 8) * 4;
	for (int plane = 0; plane < 3; plane++) {
		uint32_t *p = &cursor_colour[plane * COLOUR_WORDS + w];
		uint32_t v = (*p >> sh) & 0xf;
		*p = (*p & ~(0xfu << sh)) | ((v >> 2) | (v & 3) << 2) << sh;
	}
}

/* 320 palette lookups, two pixels per store */
static void __not_in_flash_func(gfx_line)(const uint8_t *src)
{
	const uint16_t *pal = gpu.palette;
	const uint32_t *in = __builtin_assume_aligned(src, 4);  /* gfx rows are word-aligned */
	uint32_t *out = (uint32_t *)line565;
	for (int i = 0; i < GPU_GFX_W / 4; i++) {
		uint32_t four = in[i];
		out[2 * i] = pal[four & 0xff] | (uint32_t)pal[(four >> 8) & 0xff] << 16;
		out[2 * i + 1] = pal[(four >> 16) & 0xff] | (uint32_t)pal[four >> 24] << 16;
	}
}

static void __not_in_flash_func(core1_main)(void)
{
	uint32_t *prev = NULL;
	for (;;) {
		/* vertical blank: pick up font and palette changes, build row 0 */
		/* PicoDVI's font encoder takes the leftmost pixel from bit 0; our
		 * glyphs have it in bit 7 */
		for (int line = 0; line < 16; line++)
			for (int ch = 0; ch < 256; ch++)
				font_lines[line][ch] = rev8(gpu.font16[ch][line]);
		make_attr_nibbles();
		bool gfx = gpu.mode == GPU_MODE_GFX;
		bool cursor = cursor_on();
		int cursor_row = gpu.cy, cursor_col = gpu.cx;
		if (!gfx) {
			for (int row = 0; row < GPU_TEXT_ROWS; row++)
				build_row(row);
			if (cursor)
				make_cursor_row(cursor_row, cursor_col);
		}
		for (int y = 0; y < GPU_OUT_H; y++) {
			uint32_t *tmds;
			queue_remove_blocking_u32(&dvi0.q_tmds_free, &tmds);
			if (gfx) {
				if (y & 1) {
					/* the second copy of a 320x240 line: the same symbols */
					memcpy(tmds, prev, 3 * WORDS_PER_LANE * sizeof(uint32_t));
				} else {
					gfx_line(gpu.gfx[y / 2]);
					const uint32_t *pix = (const uint32_t *)line565;
					tmds_encode_data_channel_16bpp(pix, tmds + 0 * WORDS_PER_LANE, GPU_GFX_W, DVI_16BPP_BLUE_MSB, DVI_16BPP_BLUE_LSB);
					tmds_encode_data_channel_16bpp(pix, tmds + 1 * WORDS_PER_LANE, GPU_GFX_W, DVI_16BPP_GREEN_MSB, DVI_16BPP_GREEN_LSB);
					tmds_encode_data_channel_16bpp(pix, tmds + 2 * WORDS_PER_LANE, GPU_GFX_W, DVI_16BPP_RED_MSB, DVI_16BPP_RED_LSB);
				}
				prev = tmds;
			} else {
				int row = y / 16, line = y % 16;
				bool inv = cursor && row == cursor_row && (gpu.cursor == 2 || line >= 14);
				const uint32_t *colour = inv ? cursor_colour : frame_colour[row];
				for (int plane = 0; plane < 3; plane++)
					tmds_encode_font_2bpp(frame_chars[row], &colour[plane * COLOUR_WORDS],
							      tmds + plane * WORDS_PER_LANE, GPU_OUT_W, font_lines[line]);
			}
			queue_add_blocking_u32(&dvi0.q_tmds_valid, &tmds);
		}
		frames++;
	}
}
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

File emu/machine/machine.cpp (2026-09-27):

// The whole machine, natively: see machine.h. Every function here is the
// machine.mjs / tmds.mjs function of the same name, in the same order.
#include "machine.h"

#include <linux/futex.h>
#include <sys/syscall.h>
#include <unistd.h>

#include <climits>
#include <ctime>
#include <cstdlib>

#include <algorithm>
#include <set>
#include <stdexcept>
#include <cctype>
#include <cerrno>
#include <cstring>
#include <fstream>
#include <iterator>
#include <sstream>
#include <stdexcept>

#include "../../soc/emu/board.h"

#if defined(__x86_64__) || defined(__i386__)
#include <immintrin.h>
static inline void cpuRelax() { _mm_pause(); }
#else
static inline void cpuRelax() {}
#endif

using namespace rp2040js;

namespace machine {

// the RP2040 cards' slot pins (hw/pins.yaml)
namespace P {
constexpr int SCK = 2, MOSI = 3, MISO = 4, NCS = 5, NIRQ = 6;
}

static std::vector<uint8_t> packBits(const std::vector<uint8_t> &bits) {
  std::vector<uint8_t> out;
  for (size_t i = 0; i + 8 <= bits.size(); i += 8) {
    uint8_t v = 0;
    for (size_t j = 0; j < 8; j++) v = static_cast<uint8_t>((v << 1) | bits[i + j]);
    out.push_back(v);
  }
  return out;
}

// ------------------------------------------------------------ Rp2040Card

Rp2040Card::Rp2040Card(const std::string &kind_, const std::string &elf, double mhz) : e(elf, mhz) {
  kind = kind_;
  auto &g = e.mcu->gpio;
  g[P::NCS].setInputValue(true);
  g[P::SCK].setInputValue(false);
  g[P::MOSI].setInputValue(false);
}

void Rp2040Card::drive(uint32_t sck, uint32_t mosi, bool selected) {
  if (logging) {
    // record every frame: its MOSI bytes, and the time it ended
    if (selected && !sel) {
      bits.clear();
      rbits.clear();
      t0 = e.ns();
    }
    if (selected && sck && !sck_) {
      bits.push_back(static_cast<uint8_t>(mosi));
      rbits.push_back(static_cast<uint8_t>(miso()));
    }
    if (!selected && sel && !bits.empty()) {
      log.push_back({t0, e.ns(), packBits(bits), packBits(rbits), static_cast<uint32_t>(bits.size() % 8)});
    }
    sel = selected;
    sck_ = sck;
  }
  // Only the pins that change. setInputValue (rp2040js's, ported) latches
  // an edge on every call, so setting CS_n high again while it was high
  // made a rising edge the card never had: slotspi's CS_n interrupt then
  // restarted its PIO machine, and when that landed at the start of the
  // host's next frame the frame lost its first byte (exec's quick chunk
  // reads went unanswered, E2E-011).
  auto &g = e.mcu->gpio;
  constexpr uint32_t EDGE_HIGH = 1u << 3;  // the GPIO's latched rising edge (INTR)
  const bool edgeWas = g[P::NCS].irqStatus & EDGE_HIGH;
  if (!!mosi != pinMosi) g[P::MOSI].setInputValue(pinMosi = !!mosi);
  if (!!sck != pinSck) g[P::SCK].setInputValue(pinSck = !!sck);
  if (!selected != pinNcs) g[P::NCS].setInputValue(pinNcs = !selected);
  if (!edgeWas && (g[P::NCS].irqStatus & EDGE_HIGH)) csEdges++;
  if (!selected && selNow) csRises++;
  selNow = selected;
}

uint32_t Rp2040Card::miso() {
  GPIOPin &p = e.mcu->gpio[P::MISO];
  return p.outputEnable() ? (p.outputValue() ? 1 : 0) : 1;  // released: the main board's pull-up
}

bool Rp2040Card::irq() {
  GPIOPin &p = e.mcu->gpio[P::NIRQ];
  return p.outputEnable() && !p.outputValue();  // open drain, active low
}

// ------------------------------------------------------------ EspCard

// The Wi-Fi card's firmware runs in the lockstep QEMU (tools/qemu_build.sh,
// tools/patches/qemu-esp-lockstep.patch, system/cupc8-lockstep.c), its
// clock a function of the instructions run (icount), and only as far as this
// card lets it: advance(t) grants it the board's time t in GRANT_NS steps,
// so it trails the board and runs beside it. The slot SPI slave is a device
// in QEMU that holds the MISO preload the firmware armed when the previous
// frame ended (fw/wifi/port/esp32c3/main/transport_slotdev.c, as
// transport_spi.c's DMA descriptors): at CS_n falling QEMU runs to the
// board's time and hands over that preload, and at CS_n rising the MOSI bytes
// reach the device at the board's time and interrupt the guest. The board
// never waits for the guest to answer, as it never waits for the real card:
// QEMU's clock is the board's at every select. The same board run gives the
// same guest run, cycle for cycle.

EspCard::EspCard(int tx_, int rx_) : tx(tx_), rx(rx_) {
  kind = "wifi";
  if (const char *f = std::getenv("CUPC8_ESP_TRACE")) trace = std::fopen(f, "w");
}

EspCard::~EspCard() {
  if (trace) std::fclose(trace);
}

void EspCard::readAll(uint8_t *b, size_t n) {
  for (size_t got = 0; got < n;) {
    const ssize_t r = ::read(rx, b + got, n - got);
    if (r < 0 && errno == EINTR) continue;
    if (r <= 0) throw std::runtime_error("the Wi-Fi card's QEMU has gone");
    got += static_cast<size_t>(r);
  }
}

void EspCard::writeAll(const std::vector<uint8_t> &b) {
  for (size_t put = 0; put < b.size();) {
    const ssize_t r = ::write(tx, b.data() + put, b.size() - put);
    if (r < 0 && errno == EINTR) continue;
    if (r <= 0) throw std::runtime_error("cannot write to the Wi-Fi card's QEMU");
    put += static_cast<size_t>(r);
  }
}

template <typename T>
static void putLE(std::vector<uint8_t> &v, T x) {
  for (size_t i = 0; i < sizeof x; i++) v.push_back(static_cast<uint8_t>(static_cast<uint64_t>(x) >> (8 * i)));
}

void EspCard::advance(double ns) {
  if (ns < granted + GRANT_NS) return;
  granted = ns;
  std::vector<uint8_t> m = {'G'};
  putLE(m, static_cast<int64_t>(ns));
  writeAll(m);
}

// CS_n falls: QEMU runs to the board's time and gives the preload
void EspCard::select() {
  const double t = now();
  std::vector<uint8_t> m = {'S'};
  putLE(m, static_cast<int64_t>(t));
  writeAll(m);
  uint8_t h[10];
  readAll(h, 10);
  if (h[0] != 'R') throw std::runtime_error("the Wi-Fi card's QEMU answered a select with " + std::to_string(h[0]));
  int64_t g = 0;
  for (int i = 7; i >= 0; i--) g = (g << 8) | h[1 + i];
  guestNs = g;
  ahead = std::max(ahead, g - static_cast<int64_t>(t));
  early += !h[9];
  std::vector<uint8_t> pre(PRELOAD);
  readAll(pre.data(), pre.size());
  bits.clear();
  for (uint8_t b : pre)
    for (int i = 7; i >= 0; i--) bits.push_back((b >> i) & 1);
  if (trace) {
    std::fprintf(trace, "%.0f S @%lld%s", t, static_cast<long long>(g), h[9] ? "" : " (not re-armed)");
    size_t n = pre.size();
    while (n > 0 && pre[n - 1] == 0) n--;
    for (size_t i = 0; i < n; i++) std::fprintf(trace, " %02x", pre[i]);
    std::fprintf(trace, "\n");
    std::fflush(trace);
  }
}
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

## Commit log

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2014-09-17 Fixed pours and borders
    [memory.brd]
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2014-10-12 Memory board schematic: added leds, isp, reset jumper
    [memory.sch]
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2014-10-15 mem brd: fixed minor schematic bugs
    [memory.sch]
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2015-01-05 fpga pcb - fix bank 1
    [cpu.sch]
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2015-05-18 simulator: fixed(ish) GC-related mem leak
    [nim.cfg]
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2026-08-16 Fix the simulator display: keep a framebuffer and enlarge the window.
    The old path drew each SPI rectangle into an OpenGL back buffer and
    swapped every 100k instructions, so typing wiped earlier glyphs. Pixels
    now land in a 320x240 framebuffer that is blit with nearest-neighbor
    integer scaling (3x, 960x720, resizable). Text input uses SDL text
    events so keys come through as ASCII.
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2026-08-16 Park idle I/O on WAI and rebuild the debugger layout.
    Keyboard wait masks to IRQ0 so a poll cannot wake itself via SPI.
    SPI transfers WAI on completion. The simulator stops burning run
    slices while waiting.
    The TUI now uses one column model: funcs/breaks, disasm+source,
    regs/stack, display, with memory and log along the bottom.
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2026-09-22 Verilator netlist engine, parallel tests, SPI master
    - lockstep.py: a Verilator engine that runs the ghdl-synthesised CPU
    netlist (SYN-001) next to the GHDL RTL engine; -j parallel runs; a
    build lock and up-to-date checks; private output directories per
    engine/waits/seed so concurrent tests never share files.
    - cpufuzz.py: parallel; data area moved to $8000 (generated code had
    grown into it); the WAI unit clears stale IRQs; programs that never
    reach HALT now fail the run. 2.8M instructions in seconds, 0
    divergences, 256/256 opcode bytes.
    - spi_master.vhd: new chipset SPI engine (all modes, div 0-31, SPI_CS
    framing) with an independent slave-model testbench (SPI-001/002).
    - test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
2026-09-22 Chipset: decode, memory controller, SPI, IRQ, bridge, stop/step/trace
    soc/chipset.vhd answers the CPU bus: RAM / ROM windows / I/O decode,
    a 4-clock SRAM+ROM controller (bridge first), GPO, the SPI registers over
    spi_master, IRQ_PEND/MASK, SLOT_IRQ, SYSCTL, ROM_BANK, CPU reset, and
    stop / step-cycle / step-instruction via /RDY with a 512-entry trace ring.
    soc/bridge.vhd is sysctl's SPI port (1 MHz): RAM and ROM access, raw
    ROM bus writes for JEDEC programming, STATUS, GPO, CPU_CTL, TRACE_RD.
    Testbench tb_chipset (CPU BFM + bridge BFM + SPI slave) with timing-
    checking SRAM (IS62WV5128) and SST39VF040/010 models: MMU-001..003,
    ROM-001..003, SPI-003, IRQ-001/002, BRG-001/002, DBG-001 all pass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
2026-09-22 Main board integration testbench: CPU + chipset + memory models
    tb_mainboard runs the real CPU and chipset with the SRAM/SST39 timing
    models and prints the lockstep trace from the CPU bus, with a protocol
    monitor (BUS-002). lockstep.py and cpufuzz.py gain --engine mainboard,
    and --noise hammers SRAM through the bridge while the CPU runs (BRG-003).
    All 27 test programs and the fuzzer match sim.nim on the whole system.
    The memory models can now load image files.
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2026-09-22 Simulator: model the M1 machine with the real card firmware
    sim.nim gains an I/O model switch. Legacy keeps the ILI9340/SD/keyboard
    devices for the existing tests; cards mode models doc/hardware: the ROM
    chip with its fixed and banked windows, SYSCTL and ROM_BANK, SLOT_IRQ
    with IRQ0 on the slot OR, and per-device SPI registers with SPI_CS
    framing. Slot cards are the real firmware cores, linked in through
    fw/sim/simcards.c, so the simulator's graphics and keyboard behave
    exactly like the cards will.
    simdisplay can resize, so the GPU card's 640x480 picture is displayed.
    New test SIM-004 drives both cards from guest code (tools/testdata/
    cards_gpu.s) and checks the text cells, the key byte and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
2026-09-22 Boot ROM, ROM image builder, and the boot chain in the simulator
    rom/boot.s: POST with LED codes, a RAM test that avoids its own stack
    page, slot probing by IDENT, a banner on the first graphics card, the
    kernel header check, the copy through the banked ROM window with a
    checksum, and the jump into the kernel. tools/mkrom.py builds the ROM
    image and can inspect one.
    sim.nim can load a ROM and reset to , so the simulator runs the
    real boot chain: SIM tests cover the POST sequence, banner, kernel
    entry, and every failure path (bad magic, version, header checksum,
    oversize, body checksum) plus booting with no cards fitted.
    Assembler notes learned the hard way: %define swallows trailing
    commen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
2026-09-22 Kernel: drive the graphics and IO cards, boot to BASIC
    kernel/gpu.s replaces the ILI9340 pixel path: the card holds the text
    buffer, cursor and font, so print_ascii_char is a two-byte PUTC frame.
    It finds its console in the slot table the boot ROM leaves at .
    kernel/keyb.s reads keys from the IO card (GETKEY + READ frame) and
    sleeps in WAI on the slot IRQ. kernel.s switches the ROM windows off
    first, then starts the drivers.
    printf.s loses the glyph renderer, the ASCII-to-C64-charset mappers and
    the font dumper; gfx.s fills through the card. ili9340.s, st7735.s and
    charset.s move to kernel/legacy (the C64 font is Commodore's; the card
    carries a public-domain CP437 font).
    New test KRN-001: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
2026-09-22 Wi-Fi card core with a real-socket host backend
    fw/wifi/core: the socket-level protocol from wifi-card.md (link, scan,
    resolve, four sockets, events, status byte) over a backend interface, so
    the host and simulator use BSD sockets and the ESP32-C3 will use lwIP.
    fw/wifi/host/netposix.c is that host backend.
    WIFI-001/002: the protocol plus a real TCP exchange with a listener in
    the test process - connect by name, send, receive, peer close - and the
    socket-exhaustion, TLS-unavailable and malformed-command paths.
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2026-09-22 KiCad pipeline smoke test, Kaplan Labs logo, sysctl core (WIP)
    - hw/tools/kicadgen.py: generate .kicad_sch from the KiCad libraries
    (flattened symbols, labelled pin stubs), export the netlist, build the
    board with pcbnew, route with Freerouting, JLC-derived design rules
    and Default/Power net classes in a generated .kicad_pro
    - hw/smoke/smoke.py (E2E-006): USB-C + LDO + LED board through ERC,
    routing, DRC with schematic parity, Gerbers/drill, BOM/CPL, 3D render
    - hw/tools/logo.py: the Kaplan Labs logo as a board-only silkscreen
    footprint, with a check that no detail is under JLC's 0.15 mm minimum
    - sysctl core, spec and test models: work in progress, to be reworked
    for the removab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
2026-09-22 Schematic layout checker: no overlaps, fields placed clear
    Schematic.write now places each part's Reference/Value in the first
    spot beside it that touches nothing, and refuses to write a sheet
    where any text overlaps text, a body, a pin or a wire, bodies overlap,
    a wire crosses another part, or anything leaves the page frame.
    Stacked pins get one stub and label; library-hidden fields stay
    hidden; rotated parts keep horizontal text. The smoke test's DRC now
    fails on warnings too (silkscreen overlaps and the like).
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2026-09-23 Graphics card firmware on PicoDVI, tested as the real binary (GPU-004/005)
    fw/rp2040/gpu: core 1 renders every scanline to TMDS (TEXT with PicoDVI's
    2bpp font encoder, GFX pixel-doubled RGB565), core 0 runs the slot SPI, the
    commands and PicoDVI's DMA interrupt. fw/rp2040/common/slotspi: a PIO SPI
    slave for every RP2040 card; DMA streams MOSI into a ring, the next frame's
    MISO is preloaded, and frames are replayed through the card engine.
    Bug fixed: gpu_run() kept an 8 KB command buffer on the RP2040's 2 KB stack;
    every command wrote into core 1's code in SCRATCH_X. The buffer is now in
    gpu_t, and our firmware builds with -Wstack-usage=512.
    Tests: test/emu drives gpu.elf at its slot pins w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
    [main.c, pins.yaml]
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2026-09-23 IO card firmware (TinyUSB host), USB host mode for rp2040js, IOC-004
    fw/rp2040/io: a keyboard on the native USB port through TinyUSB host HID,
    into the IO core and out through the slot SPI slave; lock LEDs driven by
    the card, VBUS switch and its fault flag.
    rp2040js patch: the USB controller's host mode (usb-host.ts): EPX control
    and bulk transfers with single/double buffering, interrupt endpoints polled
    per frame, attach/detach through SIE_STATUS.SPEED. test/emu/usbkbd.mjs is a
    boot keyboard on it.
    Bug fixed (found by IOC-004 at full speed): slotspi_refresh() restarted the
    state machine to swap the preload, and a frame starting meanwhile came out
    two bits late. The first pull of a frame n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
    [main.c, tusb_config.h]
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2026-09-23 pins: the Wi-Fi card's MISO off the GPIO2 strapping pin
    MISO was on GPIO2, which the ESP32-C3 samples at reset; the slot's MISO is
    shared, so another card's traffic could strap the module wrongly. It is on
    GPIO5 now, and pincheck rejects signals on the strapping pins.
    [pins.yaml]
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2026-09-23 Wi-Fi card firmware on ESP-IDF 5.5.5; JOIN's save flag reaches the backend
    fw/wifi/port/esp32c3: the core on the ESP32-C3 with lwIP sockets, esp-tls
    (certificate bundle, the CONNECT_HOST name checked), DNS on its own task,
    and the GPSPI2 slave (two descriptors, the next preloaded from the ISR).
    A QEMU build carries the frames over UART1 and uses OpenCores Ethernet,
    since QEMU has neither a radio nor an SPI slave.
    Bug fixed: the core ignored JOIN's save byte, so credentials were never
    kept for auto-join at power-up. The backend now gets it; the card stores
    them in NVS only when asked and joins them at boot.
    Hardware: MISO goes through a 74LVC1G125 enabled by CS_n, so the card
    releases the s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
    [main.c]
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2026-09-23 Card programming port: sysctl core, real HAL, SWD target model; rp2040js PIO timing
    sysctl moves bits and bytes for card programming (PROG_SELECT, SWD_SEQ,
    SWD_XFER, UART_OPEN, UART_XFER); the protocols go to cupc8.py (sysctl.md,
    slot.md). fw/test/swdtarget: a bit-level RP2040 behind SWD (dormant wake-up,
    multi-drop, AHB-AP, core debug, boot ROM flash routines) for SYS-004.
    Real HAL: mux pins, bit-banged SWD, PIO UART with RX streamed by DMA into
    a ring.
    Bug fixed (SYS-006): the UART only had the PIO FIFO (8 bytes) between the
    host's ~1 ms polls, so longer bootloader replies lost bytes.
    rp2040js patch: PIO clock dividers and [delay] cycles were not applied at all,
    and disabled state machin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
    [main.c]
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2026-09-23 GPU: PicoDVI's DMA interrupt at the top priority; the slot SPI masks only its own IRQ
    Bug fixed (found by the whole-machine emulator at the boot ROM's slot probe):
    the slot SPI's CS_n interrupt ran above PicoDVI's DMA interrupt, and its
    refresh disabled all interrupts on core 0. A delayed DVI interrupt misses
    its porch window to rewrite the next scanline's control blocks, and the
    three TMDS lanes' DMA channels end up cross-wired. The DVI IRQ is now
    priority 0, CS_n's 0x40, and slotspi's critical sections mask only the GPIO
    IRQ. GPU-005 now also checks the picture after 200 SPI frames at random
    moments; EMU-002 shows the emulator's nested interrupts are sound (so this
    was the firmware, not rp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
    [main.c]
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2026-09-24 gpu: TMDS green on GPIO14/15 and clock on 10/11, pads inverted (P on n+1): the pairs then sit round the RP2040 in the HDMI receptacle's order, so they route without crossings
    GPU-005 (real gpu.elf, TMDS decoded) passes: invert_diffpairs is a pad
    output override, the PIO lanes are unchanged.
    [main.c, pins.yaml]
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2026-09-24 hw: CPU card on JLC's footprints with datasheet pin tables (BRD-001); pins.yaml: bank-2 CPU bus pins in the socket's finger order
    The CPU card's bank-2 pins now run, bottom to top, in the order their
    fingers do (/RST /STB /RDY RW SYNC D0-D4 CLK D5-D7 TMR0 TMR1 HALTED
    WAITING), so the control lines no longer cross all eight data lines: with
    the old order Freerouting left the same bus nets unrouted in every
    attempt on two board sizes. CPU_CLK stays on GBIN5 (pin 49), A and IRQ
    unchanged. pincheck passes; cpucard fmax 63.8 MHz; bus budget 66%/63%.
    bomcheck: a multi-unit symbol's pins are all its units' (the FPGA), and
    package_ok reads JLC's 'TQFP-144(20x20)', 'SOIC-8-208mil' and '0603x4'.
    Co-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
    [pins.yaml]
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2026-09-24 native machine and card-test backends: work in progress (snapshot)
    emu/machine (threaded whole-machine emulator), emu/rp2040/node and harness
    (the native Emu binding for the card tests), test/emu backend switch: being
    written, not yet the default anywhere.
    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
    [addon.cpp, board.h, machine.cpp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]
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2026-09-24 hw: CPU card pins in the fingers' order on each side of the package, arrays at their pins
    pins.yaml cpu_fpga: the bottom side carries A0-A15 (1-20, unchanged), then
    CPU_CLK (21, GBIN6), /RST, /STB, /RDY, RW, SYNC (22-26); the right side,
    bottom up, D0-D7 (37-45), IRQ0-3 (47-52), TMR_EXP0/1, HALTED, WAITING
    (55-61). Each side's order is the order of its fingers, left to right, so
    the front-side bus lines reach the socket without crossing and A drops to
    the back layer through its arrays. With the old order (IRQ on the bottom
    side, the control lines and CLK on the right) Freerouting left 5-7 bus
    nets unrouted on every try, even given the 3V3 layer to route on.
    pincheck: 0 problems; cpucard fmax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
    [pins.yaml]
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2026-09-24 rp2040 emu: PIO fast path (lazy runners and stalled machines), exact to rp2040js
    While every enabled state machine of a PIO block is either stalled on a
    WAIT that only a syncing event can end, or runs a loop of plain OUTs
    (PicoDVI's out pc, 1 serialiser) that will not autopull for a while,
    RPPIO::step() only counts the cycles it owes. RPPIO::sync() replays them
    exactly (a specialised copy of the OUT path, then checkForUpdates on
    every pin that changed, which with no listeners only sets lastValue) and
    returns to per-cycle stepping. Every path into the block syncs first:
    its bus registers, GPIOPin's PIO output functions, setInputValue,
    addListener, IO_BANK0 ctrl and PADS writes. The autopull c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
    [gpio-pin.cpp]
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2026-09-24 rp2040 emu: cheaper exact paths (same behaviour)
    - CortexM0Core::setInterrupt inline for its common cases (already pending,
    clearing); RP2040::setInterrupt stays out of line for test_periph_diff.
    - RPPIO::checkInterrupts computes intRaw() once.
    - FIFO keeps its length and wraps without %.
    - RPSIO::selectCore only records the core; the divider/interpolator bank
    swap happens at the next SIO access (the only users of those fields),
    so RP2040::step selecting core 1 and back costs nothing.
    - SimulationClock: unlinking an alarm that is not in the list (a fired
    one keeps 'scheduled') skips the search.
    - Emu::cycles uses stepPIOs() when there is no onCycle hook.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
    [rp2040.cpp]
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2026-09-24 storage card (type $04, microSD in M1, medium-neutral protocol) replaces the microSD on the IO card; e-ink GPU card recorded for exploration; doc/m1-status.md: decisions and in-flight work
    [pins.yaml]
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2026-09-24 SD model: the machine's storage slot kind, Node bindings, and the model under the pico-sdk's SPI/DMA (EMU-008)
    emu/machine: a 'storage' card (build/rp2040/storage.elf at 125 MHz) with
    the microSD socket on its SPI1; machine.node sdInsert/sdRemove/sdCard and
    machinenative.mjs m.sd. rp2040emu.node and rp2040native.mjs: SdSocket for
    the card tests (native only). fw/rp2040/selftest/sdspi.c: an independent
    SD host on the SDK's hardware_spi and hardware_dma, run by
    test/emu/test_sdspi.mjs on SDHC and SDSC images. tools/fetch_sdks.sh:
    pyfatfs 1.1.0 in a pinned venv for the host FAT checks.
    [addon.cpp, machine.cpp, machine.h]
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2026-09-25 sysctl: USB VBUS sensing - the card no longer pulls D+ up without a host (USB 2.0, 7.1.5)
    A 2N7002 (Q1, C8545) pulls GPIO29 (USB_nVBUS, was the status LED) low while
    the host's VBUS is there; 10k/100k on its gate, 10k pull-up on the drain.
    The RP2040 pin never sees VBUS. The firmware starts USB only once VBUS is
    seen and drops the pull-up (tud_disconnect) whenever it goes. The status LED
    is gone: the LED row is PWR, TX, RX. SYS-006 checks no pull-up and no
    enumeration without VBUS, and the pull-up going and coming back with it.
    [main.c, pins.yaml]
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2026-09-25 hw: CPU card pinout by layer: the bottom side carries the front-side bus lines in the fingers' order (/RST /STB /RDY RW SYNC D0-7 IRQ0-3 TMR_EXP HALTED WAITING), the right side A0-15 for the back-sid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
    On the I/O-card outline the band under the package is 10 mm, and any two
    front-side groups whose pins and fingers were in opposite orders crossed in
    it (the D lines from the right side across the control lines, for one): 16
    or more nets unrouted. Now the front lines drop to their fingers without
    crossing, and A, alone on the back layer, crosses under everything.
    /STB, RW and SYNC get single 0402s (C25105): /RDY sits between them.
    pincheck: 0 problem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
    [pins.yaml]
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2026-09-25 Revert "hw: CPU card pinout by layer" (b937e8d)
    With the D and control lines on the bottom side and A on the right, the A
    lines' long back-side diagonals routed worse (10 unrouted, and 8 with a third
    signal layer) than the previous pinout with its arrays in order (1 unrouted
    with a third signal layer). Back to that pinout: pins.yaml as at 4e04e9c
    (FPGA build 59.5 MHz, bus 65%/64% slack, checked then).
    [pins.yaml]
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2026-09-25 emu: the HDMI card's slot kind is 'hdmi' (was 'gpu'; it still runs gpu.elf); an unknown kind is an error, not a card without its models
    [addon.cpp, machine.cpp, machinerun.cpp]
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2026-09-25 emu/machine: drive a card's slot pins only when they change
    rp2040js's setInputValue (ported in emu/rp2040) latches an edge on every
    call, and Rp2040Card::drive set CS_n (and SCK, MOSI) on every sync, so a
    deselected card saw a rising CS_n edge it never had, over and over. Each
    ran slotspi's cs_rose, which restarts the PIO machine; one landing at the
    start of the host's next frame cost that frame its first byte, and the
    command went unanswered. exec's quick 128-byte chunk reads hit it every
    time (E2E-011: "card error" after 65280 not-ready READs). Real pins only
    have edges when they change, and now so do these.
    [machine.cpp, machine.h]
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2026-09-25 emulator: a composite CDC host (cdchost.mjs and its C++ port) for the system card's two ports; m.console in machinenative.mjs, the viewer's console pane and --console-port; SYS-006 on both ports; the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
    rp2040js's USBCDC takes the last CDC function's endpoints, so against the
    composite card it spoke to the console port and SYS-006 lost every reply.
    The native backend had no usbCtrl.sieCtrl, so EMU-006 (sysctl) failed its
    two D+ pull-up checks on the native side since 7b1e0f5.
    [addon.cpp, machine.cpp, machine.h]
2026-09-25 E2E-011: every CS_n edge a card latches is a real deselect; a 24 KB exec
    The CS_n-edge fix (08496f0) was guarded only by exec's chunk reads failing
    by timing, which today's kernel and firmware no longer meet (not even 192
    chunk reads back to back). Rp2040Card now counts the chipset's deselects
    (csRises) and the rising edges the card's CS_n GPIO latched (csEdges),
    given by cards(); E2E-011 requires csEdges <= csRises on every card:
    191/191, 311/311, 1113/1113 with the fix, 364k-434k edges with the bug
    back. The counters do not change what the machine does (EMU-007).
    E2E-011 also execs the program with 24 KB after it, and SIM-010's text
    names the parked-program check.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
    [addon.cpp, machine.cpp, machine.h]
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2026-09-26 emu/machine: the Wi-Fi card's QEMU in step with the board
    EspCard drives the lockstep QEMU (tools/qemu_build.sh): advance(t) grants it
    the board's time in 100 us steps (also for the threaded leader's main cards,
    as iterateSerial does), and the $A6/$A5 exchanges are sent at the board's
    time of the select/deselect and wait for the guest's answer, which fails
    after 10 s of guest time instead of hanging. machinenative.mjs starts it with
    -icount shift=3,sleep=off -seed 1 and the cupc8 chardev, and takes a pcap
    option (filter-dump of the guest's traffic). The Wi-Fi card now logs its
    frames (spiLog, with QEMU's clock at each frame's end) and cards() gives
    QEMU's clock as its ns; the frame log moved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
    [addon.cpp, machine.cpp, machine.h]
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2026-09-26 EMU-009: the Wi-Fi card in step (serial = threaded = threaded, pcap included); E2E-003 repeatable
    test/emu/test_wifi_lockstep.mjs boots, joins and fetches from an HTTP server
    in a child process, serially and threaded twice, and compares board, CPU,
    cards (QEMU's clock), every SPI frame, the guest's traffic (pcap, guest
    times) and the screen, and requires every packet the guest receives to reach
    it at the guest time of the packet that asked for it.
    That check found the settle missing TCP connects: the SYN opens a host
    socket the main loop's poll set does not have yet, so the SYN-ACK came
    0.44 ms of guest time later, whenever the main loop went round (once in
    three runs the guest's ACK moved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
    [machine.cpp]
2026-09-26 emu/machine README, CLAUDE.md: the Wi-Fi card is no longer an exception to cycle-perfect
    The Wi-Fi card section: the lockstep mechanism, what is and is not in step
    (the host network behind slirp never is; the settle pins down prompt
    answers), the guest clock running ahead while the kernel polls back to back
    (and why taking UART bytes at once was not the fix: the frames task starved
    the firmware's main task), traces, pcap, and speed before and after.
    [machine.h]
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2026-09-26 wifi firmware: the frame-end ISR no longer asks lwIP for the status byte
    frames_preload() runs in the SPI slave's post-transaction ISR on the card
    (transport_spi.c) and called the card's status(), which asks lwIP (FIONREAD
    on each open socket, and a TLS step): from an interrupt that corrupts
    FreeRTOS's lists once a socket is open; the lockstep QEMU's SPI slave
    stand-in hung in vListInsert (interrupt watchdog) right after DHCP. The UART
    stand-in took the preload in a task and hid it. The task now takes the status
    byte (frames_status(), each main-loop pass, at most a tick old) and the ISR
    uses that.
    [main.c]
2026-09-26 Wi-Fi card: QEMU holds the slot SPI preload itself; the card's clock tracks the board's
    The lockstep QEMU gets a stand-in for the ESP32-C3's GPSPI2 slave (at its
    address and interrupt source): it holds the MISO preload the firmware armed,
    as the real slave's queued DMA descriptor does. The emulator's EspCard sends
    'S' at CS_n falling (QEMU runs to the board's time and hands over the
    preload) and 'F' at CS_n rising (the MOSI bytes reach the device at the
    board's time and interrupt the guest), and no longer waits for the guest to
    answer over UART, which took ~1.3 ms of guest time per frame and let the
    card's clock run 0.3 s ahead during net join's polling. The firmware's QEMU
    build uses the de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
    [addon.cpp, machine.cpp, machine.h]
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2026-09-27 Drive native reset from routed supervisor nPOR path
    [addon.cpp, machine.cpp, machine.h]
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2026-09-27 Execute routed chipset-to-CPU reset continuity in co-simulation
    [addon.cpp, board.h, machine.cpp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]
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
